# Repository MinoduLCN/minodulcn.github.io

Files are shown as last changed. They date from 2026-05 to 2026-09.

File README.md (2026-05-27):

# Minodu Project — GitHub Pages Site

Project presentation and documentation site for the Minodu Project.  
Built with [Jekyll](https://jekyllrb.com/) + [Minima](https://github.com/jekyll/minima) theme, served by GitHub Pages.

🌐 **Live site:** <https://minodulcn.github.io>

---

## Pages

| Page | File | URL |
|---|---|-----|
| Home | `index.md` | `/` |
| Getting Started | `getting-started.md` | `/getting-started/` |
| Features | `features.md` | `/features/` |
| Documentation | `docs.md` | `/docs/` |
| About | `about.md` | `/about/` |

---

## Local Development

### Step 1 — Install a modern Ruby

macOS ships with Ruby 2.6, which is too old for the `github-pages` gem. Use `rbenv` to manage a newer version:

```bash
brew install rbenv ruby-build

# Add rbenv to your shell (run once)
echo 'eval "$(rbenv init - zsh)"' >> ~/.zshrc
source ~/.zshrc

# Install Ruby 3.3 and pin it to this project
rbenv install 3.3.6
rbenv local 3.3.6      # creates a .ruby-version file in the repo
ruby --version          # should show 3.3.6
```

### Step 2 — Install dependencies

```bash
gem install bundler
bundle install
```

> `bundle install` reads the `Gemfile` and installs Jekyll + the same gem set GitHub Pages uses,
> so what you see locally matches what GitHub builds.

### Step 3 — Serve locally

```bash
bundle exec jekyll serve
```

Then open **http://localhost:4000** in your browser. The server watches for file changes and
rebuilds automatically — just save a file and refresh.

### Useful flags

| Flag | Effect |
|---|---|
| `--livereload` | Auto-reloads the browser on save |
| `--drafts` | Also renders posts in `_drafts/` |
| `bundle exec jekyll build` | One-shot build into `_site/` without serving |

---

## Deployment

Every push to `main` triggers an automatic build by GitHub Pages.  
No manual step needed — just push and GitHub does the rest.

> **One-time setup:** Confirm GitHub Pages is enabled in  
> **Settings → Pages → Source → Deploy from branch → `main` / `(root)`**

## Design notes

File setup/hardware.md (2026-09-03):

---
layout: page
title: Hardware Assembly
---

The Minodu Local Community Network mainly consists of two parts: the [Local Community Network](#assembly-guide-minodu-local-community-network): a Raspberry Pi, the TeleAgriculture Board and a power converter, housed in a custom 3D-printed protection box; and the 3D-printed [Stevenson Screen](#stevenson-screen--sensors) in which the environmental sensors are fixed and protected.

<iframe
  src="https://a360.co/4q3GGlT"
  style="width:100%; height:720px;"
></iframe>
[Link to Design (Autodesk Fusion 360)](https://a360.co/4q3GGlT): https://a360.co/4q3GGlT

# Assembly guide: Minodu Local Community Network

<div style="display: grid; grid-template-columns: 1fr 1fr; gap: 1rem; flex-wrap: wrap;">

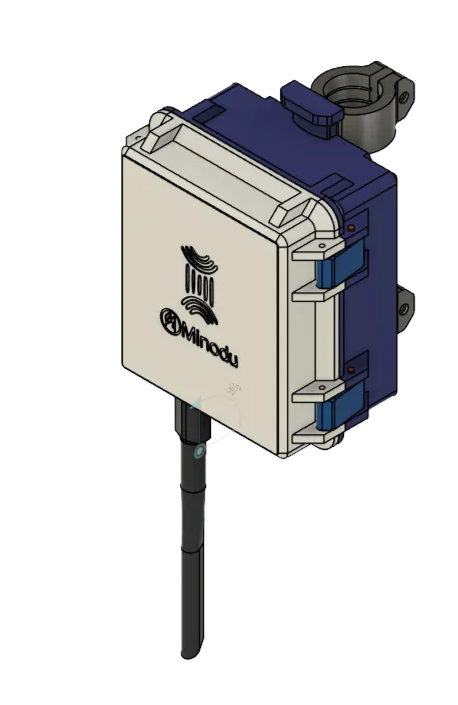
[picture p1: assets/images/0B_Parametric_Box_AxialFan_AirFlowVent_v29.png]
  
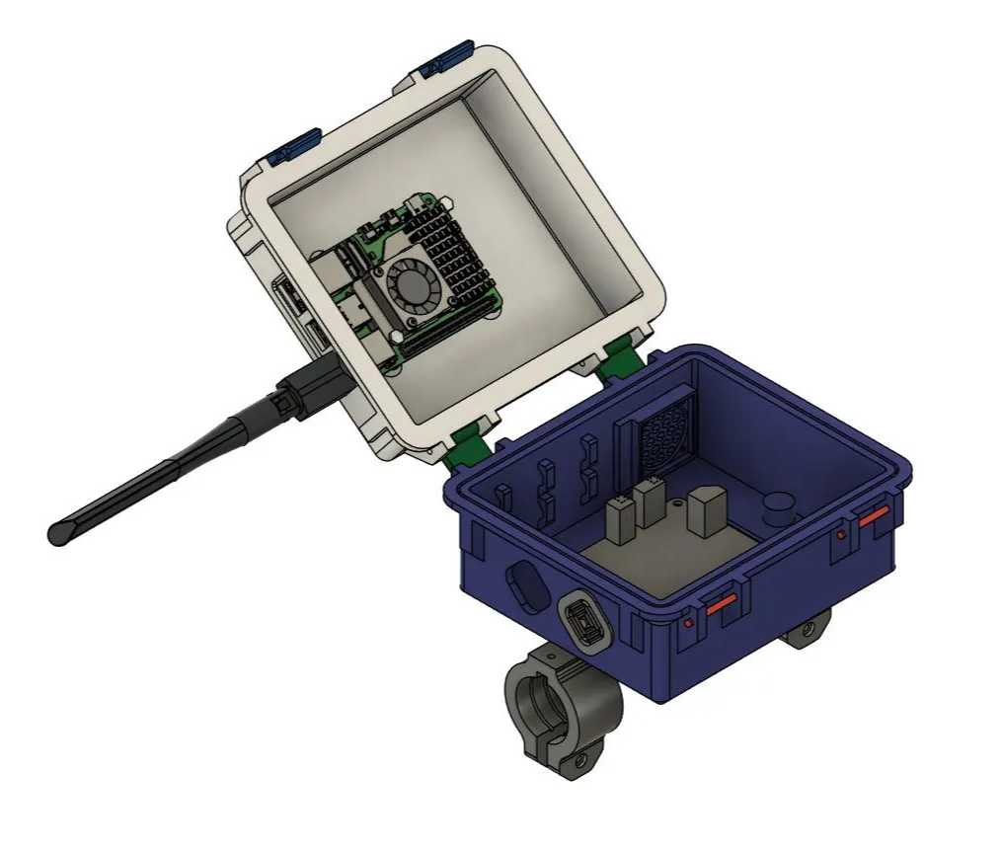
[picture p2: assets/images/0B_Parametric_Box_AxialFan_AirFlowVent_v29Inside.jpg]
  
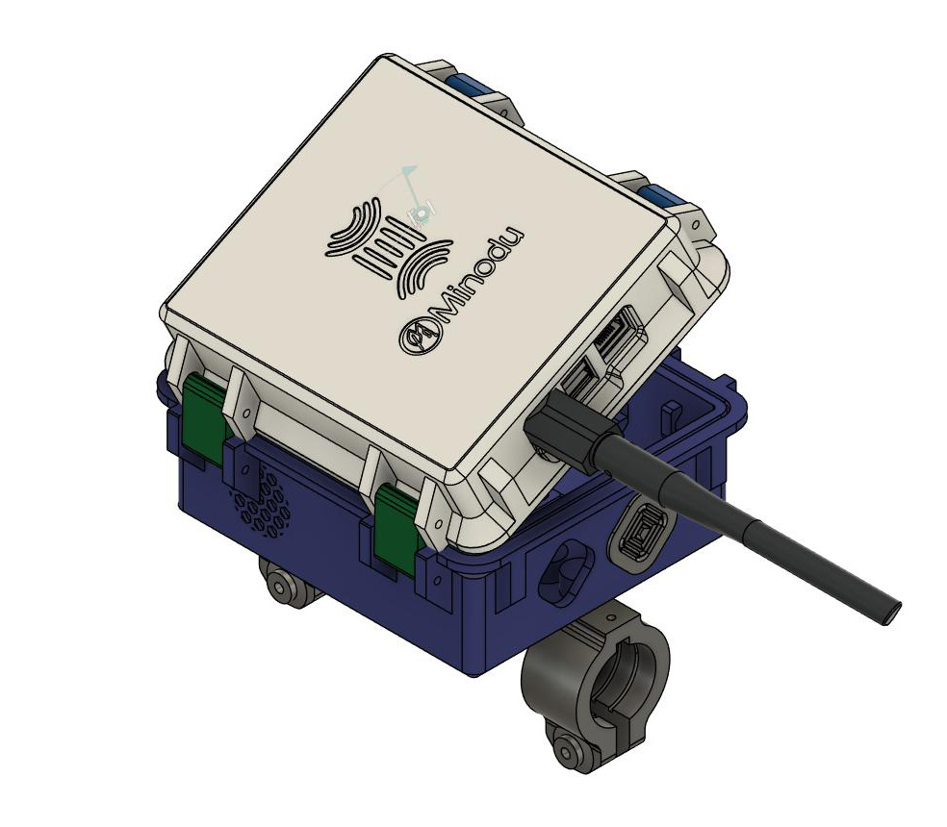
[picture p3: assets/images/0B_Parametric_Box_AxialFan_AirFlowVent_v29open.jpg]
  
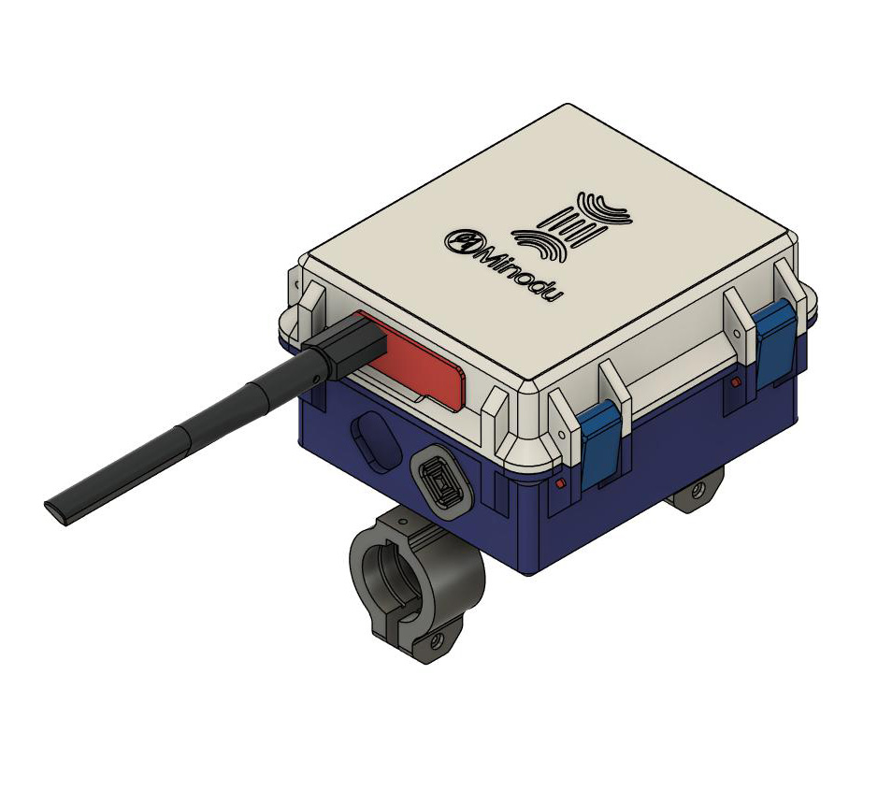
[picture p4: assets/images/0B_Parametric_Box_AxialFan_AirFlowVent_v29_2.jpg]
  

</div>

## 3D Printing Guide

### Materials
- Idealy PETG, ASA, ABS ( Unprotected ABS should almost never be used outdoors. To make ABS suitable for the sun, it must be coated in a UV-resistant paint or clear coat)
- TPU for flexible and sealing components

### Protection Box 3D Files
*ABS or at least PETG for outdoor setup*
 - [01x Base](../assets/3dFiles/Base_x01.stl)
 - [01x Top](../assets/3dFiles/Top_x01.stl) if you can Print Mulitcolor use This [Top_x01-MultiColor.stl](../assets/3dFiles/Top_x01-MultiColor.stl)
 - [02x Hinge](../assets/3dFiles/Hinge_x02.stl)
 - [02x Latch](../assets/3dFiles/Latch_x02.stl)
 - [02x Latch clip](../assets/3dFiles/Clip_x02.stl)

 *Flexible parts (TPU)*
 - [02x TPU Cable outlet cap](../assets/3dFiles/TPU_CableOutletCap_x02.stl)
 - [01x TPU RPi5 ports dust cap](../assets/3dFiles/TPU_RPi5PortDustCaps_x01.stl)

  For the 3D Files for the Stevenson Screen see [Stevenson Screen 3D Files](#stevenson-screen-3d-files)

### Slicer Setup
3D printers only understand G-code language (**geometric code)**; So what we need to do is to convert the *STL* files into G CODE. 

Recommended tool: I personally use [OrcaSlicer](https://www.orcaslicer.com/) but they all work the same.
Tool tutorial: Watch [this quick video](https://www.youtube.com/watch?v=KWfKkeOSpmw) to get you started if you are new to 3D printing with OrcaSlicer.

Here is The Orca slicer projectfile withh all the parts
    - [Minodu_Box.3mf](../assets/3dFiles/Minodu_Box.3mf)

## Protection Box assembly
This guide explains how to assemble the 3D-printed protection box for the Minodu Local Network. The enclosure is designed to house a Raspberry Pi 5, the Tele-Agriculture Board, a 12V-to-5V DC-DC power converter, sensor cables, and can be mounted on a pole for outdoor installations with a Stevenson screen.

**Assembly video**

<iframe width="100%" style="aspect-ratio: 16 / 9" src="https://www.youtube.com/embed/7zh7hve5er4?si=OtjEWRjfrtD__3ae" title="Minodu Protection Box Assembly steps" frameborder="0" allow="accelerometer; autoplay; clipboard-write; encrypted-media; gyroscope; picture-in-picture; web-share" referrerpolicy="strict-origin-when-cross-origin" allowfullscreen></iframe>

### Required Components

#### 3D Printed Parts

- Top cover
- Bottom enclosure
- 2 × Hinges
- 2 × Latches
- TPU dust cap

#### Electronics

- Raspberry Pi 5
- Raspberry Pi Active Cooler
- Tele-Agriculture Board
- 12 V → 5 V DC-DC Converter
- 30 × 30 × 10 mm cooling fan

#### Hardware

- 04x M2.5 heat-set inserts
- 04x M2.5 × 20 mm standoffs
- 04x M2.5 × 6 mm screws
- 06x M3 × 30 mm hex socket head screws
- 06x M3 hex nuts
- 02x M6 heat-set inserts
- 02x M6 × 14 mm countersunk screw

### Step by step assembly
#### Step 1 – Install Raspberry Pi Inserts
{:.no_toc}

| Steps | Images |
|---|---|
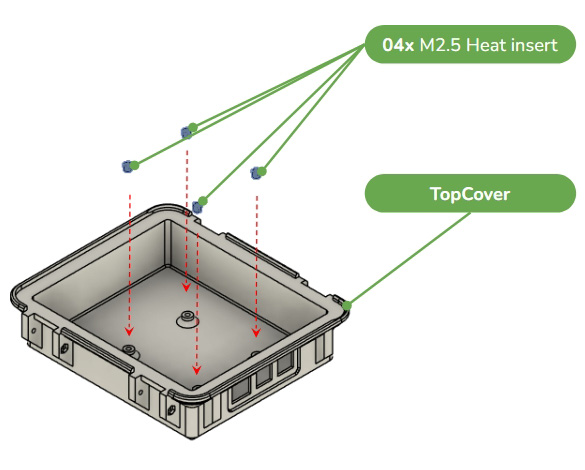
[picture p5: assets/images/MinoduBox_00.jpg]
Step 01
| Turn the top cover upside down. Insert the M2.5 heat-set inserts into the designated mounting holes using a soldering iron or heat-set insert tool. |  |
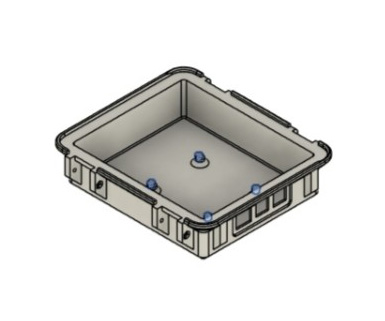
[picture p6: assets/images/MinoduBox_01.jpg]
Step 02
| Ensure every insert sits perfectly flush with the plastic surface. **CAUTION: Allow the inserts to cool before continuing.** |  |

___

#### Step 2 – Mount the Raspberry Pi
{:.no_toc}

| Steps | Images |
|---|---|
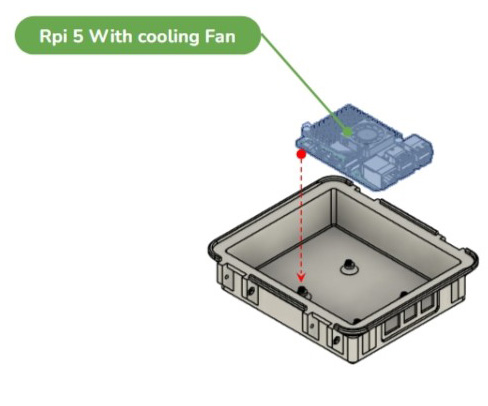
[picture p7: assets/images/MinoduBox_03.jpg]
| Position the Raspberry Pi 5 (with its cooling fan already installed) over the inserts. |  |
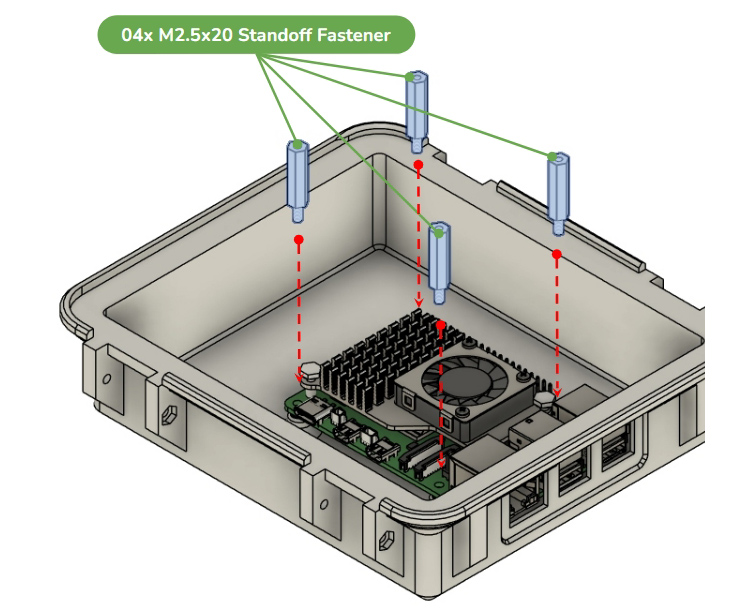
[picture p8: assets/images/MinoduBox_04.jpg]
| Install the 20 mm M2.5 standoffs and secure the Raspberry Pi. |  |
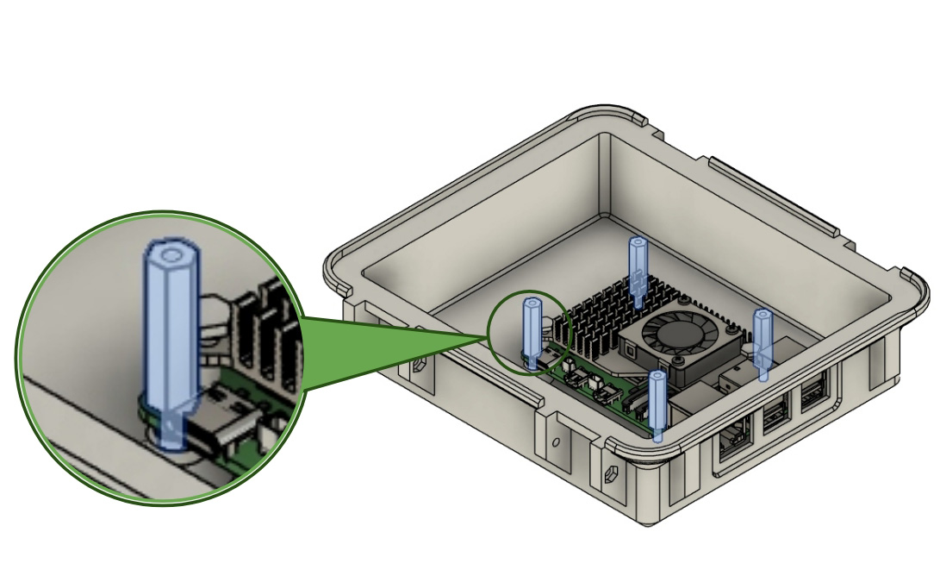
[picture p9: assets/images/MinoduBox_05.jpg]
| Verify that the board is firmly mounted. |  |

___

#### Step 3 – Install the Tele-Agriculture Board
{:.no_toc}

| Steps | Images |
|---|---|
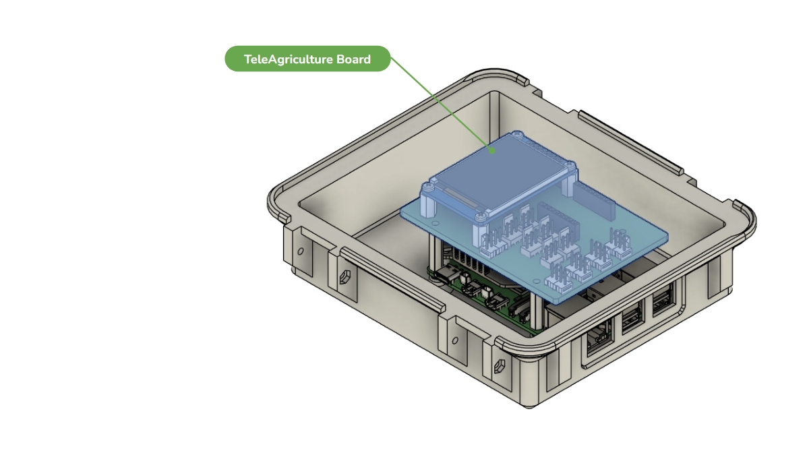
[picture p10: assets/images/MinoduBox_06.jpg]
| Place the Tele-Agriculture Board on top of the standoffs. |  |
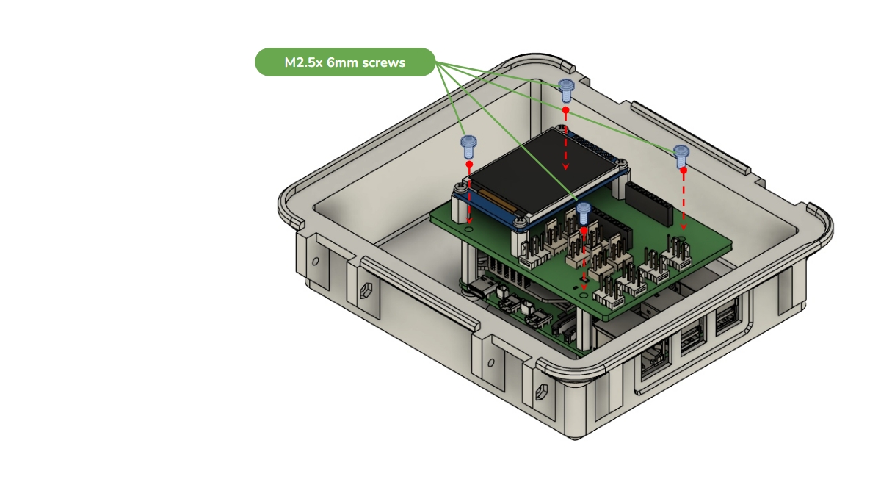
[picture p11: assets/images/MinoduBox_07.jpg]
| Secure it using M2.5 × 6 mm screws. |  |
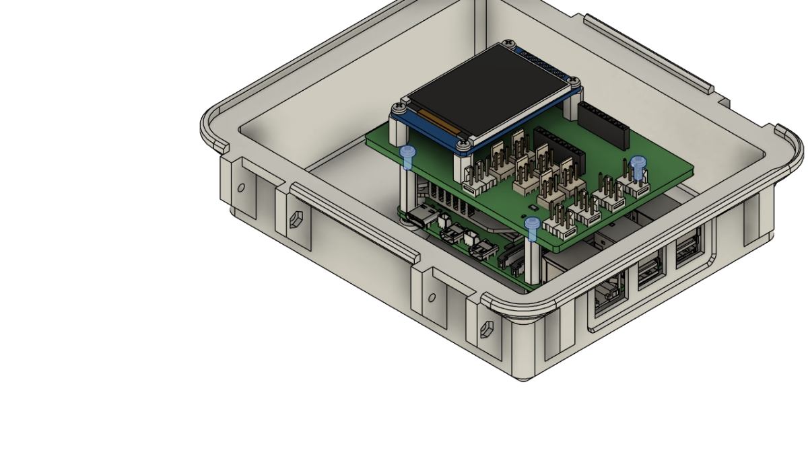
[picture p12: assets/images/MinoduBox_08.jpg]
Step 04 Step 0X
| Install the fourth screw located beneath the display. **IMPORTANT: Check that nothing moves or is loose.** |  |

___

#### Step 4 – Assemble the Latches
{:.no_toc}

| Steps | Images |
|---|---|
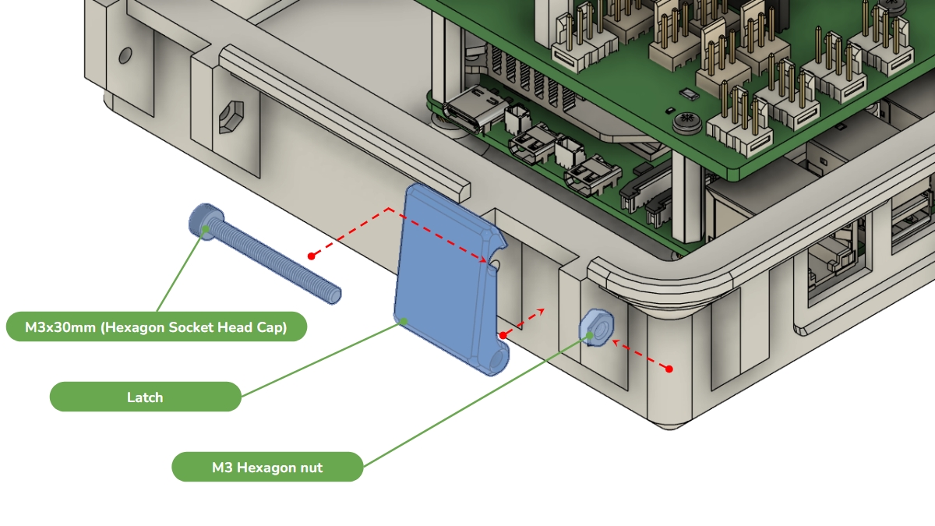
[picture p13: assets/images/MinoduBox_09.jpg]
| Insert one M3 hex nut. Align the latch. Insert one M3 × 30 mm screw. |  |
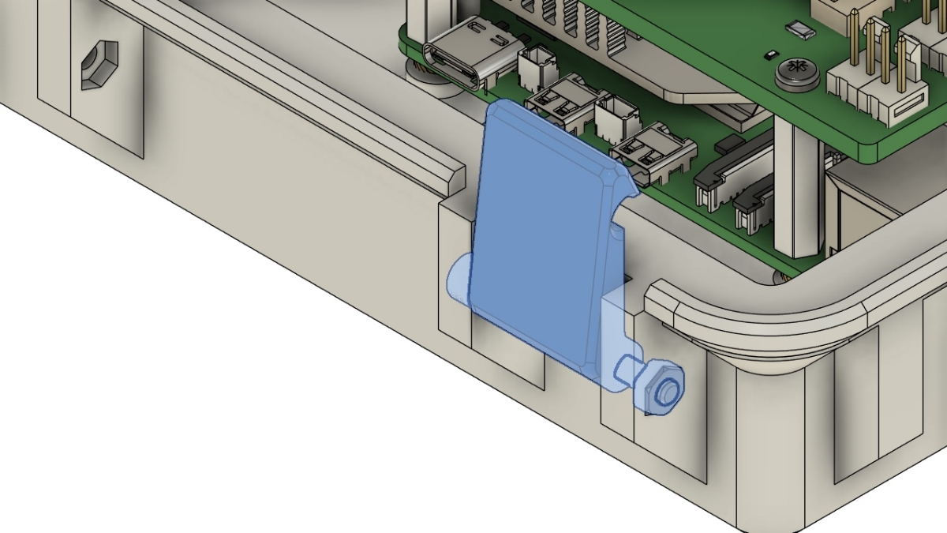
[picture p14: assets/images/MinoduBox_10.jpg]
| Tighten until secure. |  |
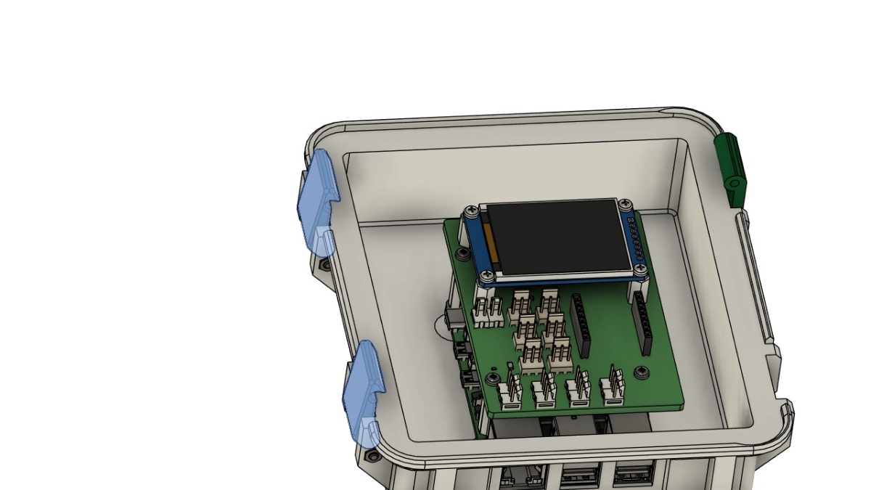
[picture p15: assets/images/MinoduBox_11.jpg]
| Repeat for the second latch. |  |

___

#### Step 5 – Assemble the Hinges
{:.no_toc}

| Steps | Images |
|---|---|
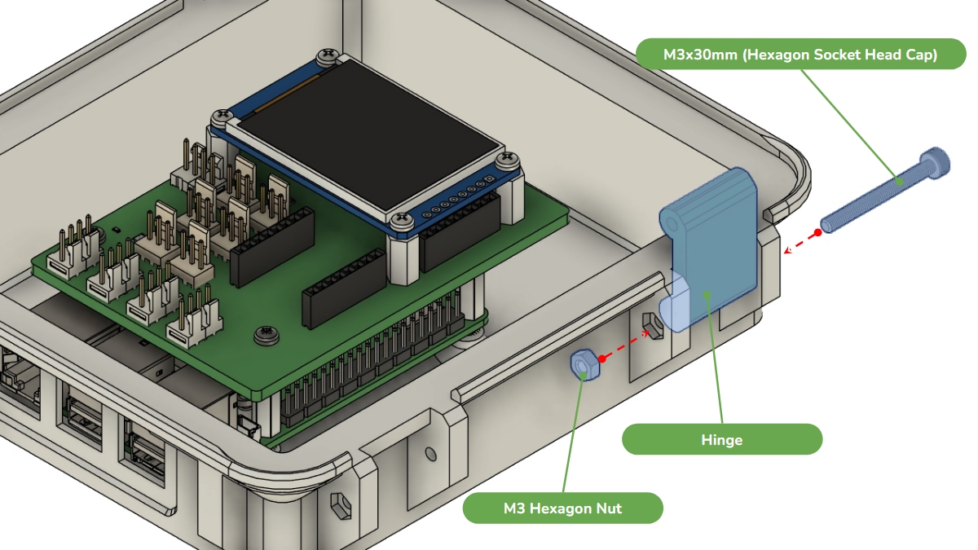
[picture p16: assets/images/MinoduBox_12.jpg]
| On the other side of the box, using the same hardware: Insert the M3 nut. Align the hinge. Insert the M3 × 30 mm screw. Tighten. |  |
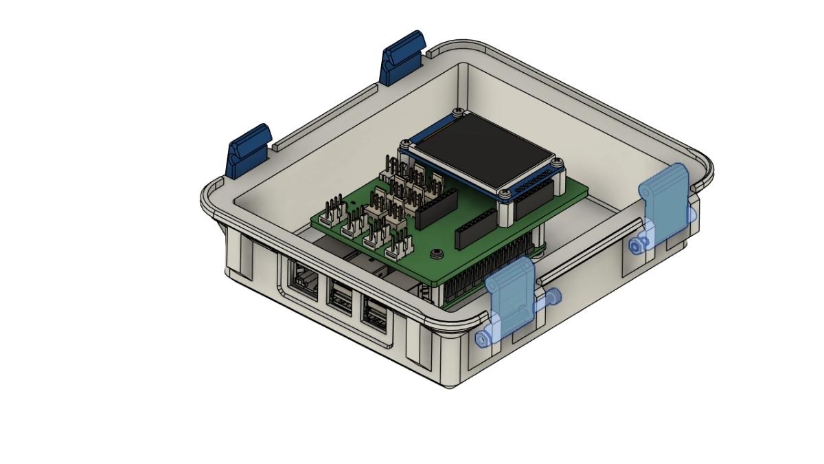
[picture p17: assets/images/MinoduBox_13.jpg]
| Repeat for the second hinge. Ensure both hinges rotate freely. |  |

___

#### Step 6 – Install the DC Converter Insert
{:.no_toc}

| Steps | Images |
|---|---|
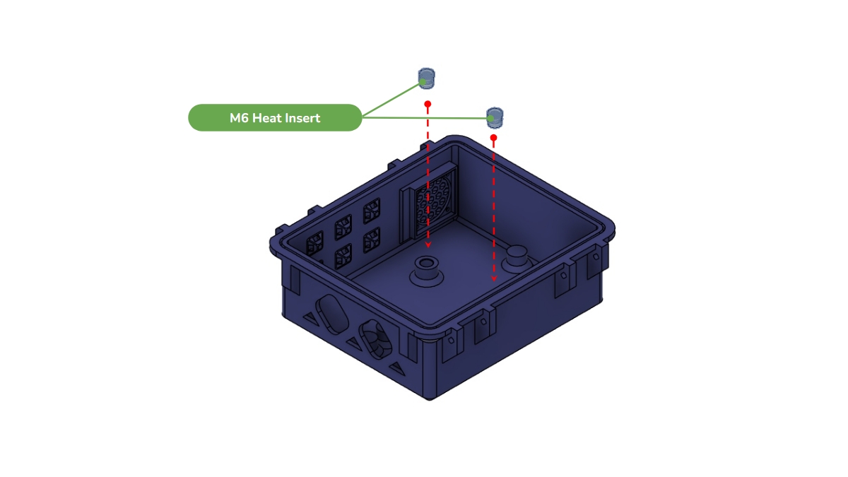
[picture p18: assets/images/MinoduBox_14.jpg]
| Install the M6 heat-set insert for the DC-DC converter into the bottom enclosure. |  |
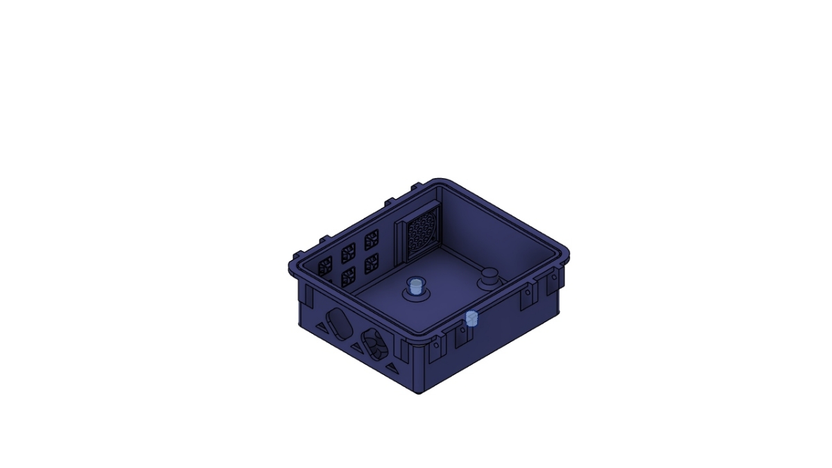
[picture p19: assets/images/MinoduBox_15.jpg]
| Make sure it is completely flush with the plastic. |  |

___

#### Step 7 – Install the Cooling Fan
{:.no_toc}

| Steps | Images |
|---|---|
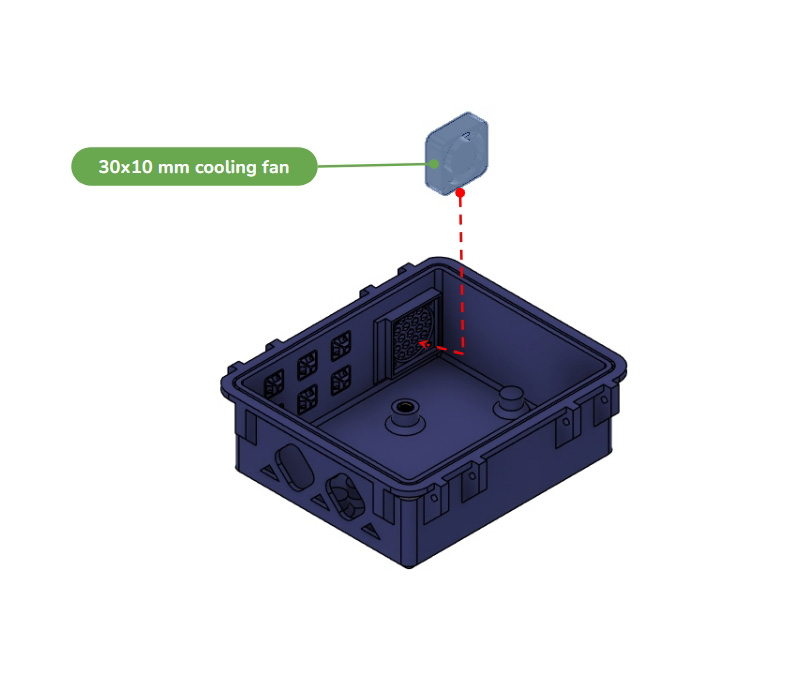
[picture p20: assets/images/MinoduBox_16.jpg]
| Insert the 30 × 30 × 10 mm cooling fan into its ventilation opening. **IMPORTANT: The cable exits toward the wiring opening. Airflow is directed from inside the enclosure to the outside.** |  |
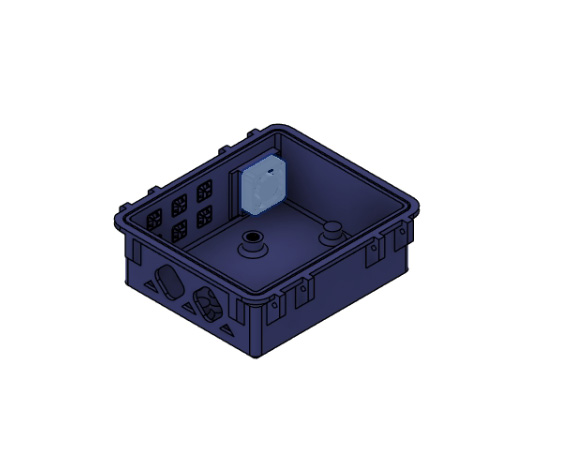
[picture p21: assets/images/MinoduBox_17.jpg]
| Push the fan fully into position. If necessary, secure it with a very small amount of glue. **CAUTION: Ensure the fan blades rotate freely. If the blades touch the >enclosure, If they rub against the enclosure, it can be jammed, overheat and be fried.** |  |

___

#### Step 8 – Install the DC-DC Converter
{:.no_toc}

| Steps | Images |
|---|---|
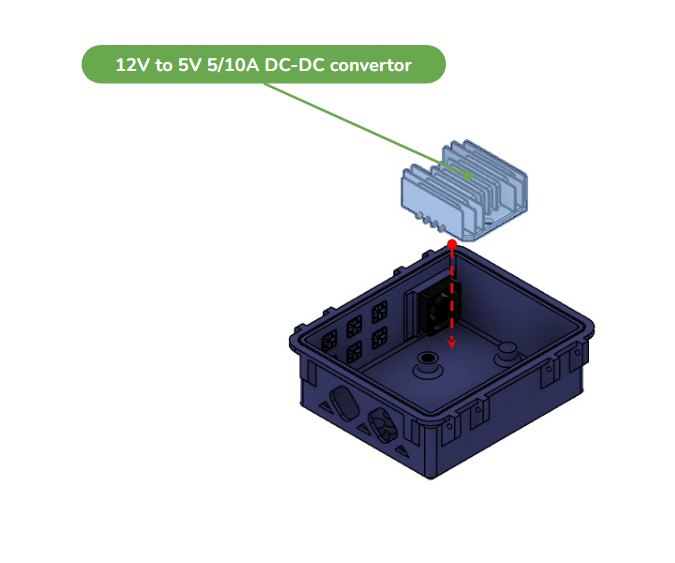
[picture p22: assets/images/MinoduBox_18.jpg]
| Position the 12V-to-5V converter inside the enclosure. |  |
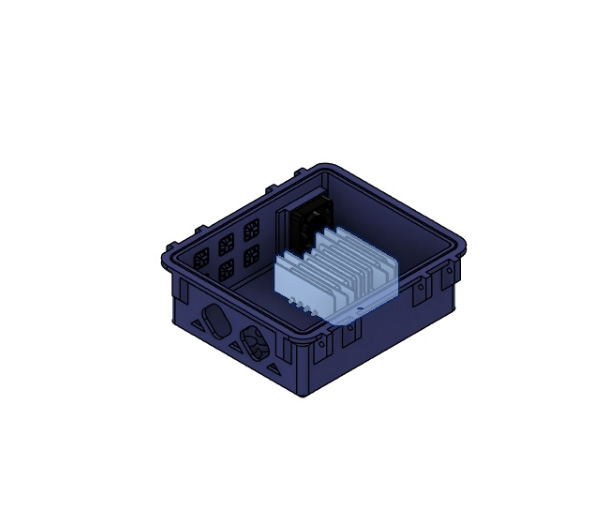
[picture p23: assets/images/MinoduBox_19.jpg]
| Align the mounting holes with the insert. |  |
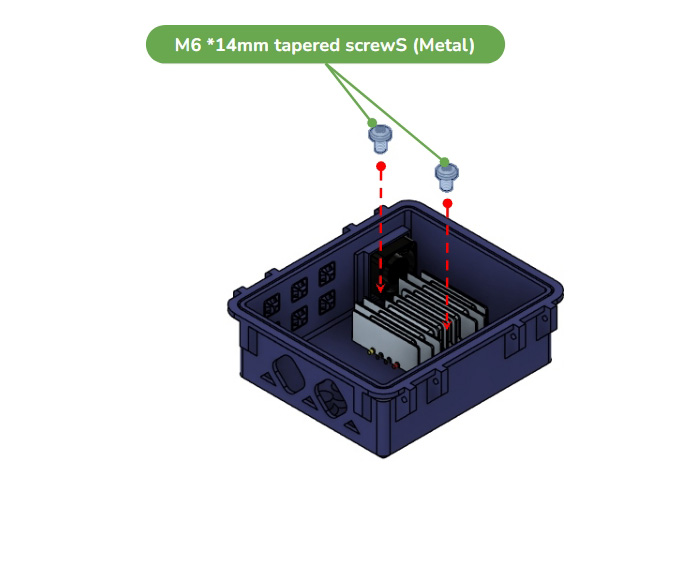
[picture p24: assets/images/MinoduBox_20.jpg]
| Secure it using the M6 × 14 mm countersunk screw. |  |
| Ensure the wiring faces the cable exit. | Step 0X |

___

#### Step 9 – Join Both Halves
{:.no_toc}

| Steps | Images |
|---|---|
| Align the hinge side first. Insert the hinge screws, nuts and, tighten. | Step 0X |
| Then align the latch side and secure it. Verify that: A) The enclosure opens smoothly. B) The enclosure closes correctly. | Step 0X |

#### Step 10 – Install the Latch Clips
{:.no_toc}

| Steps | Images |
|---|---|
| Insert the two printed latch clips into the lower enclosure. Push them fully into place until flush. | Step 0X |
| Close the enclosure and verify that the latches lock securely. | Step 0X |

#### Step 11 – Final Assembly
{:.no_toc}

| Steps | Images |
|---|---|
| Install: A) TPU dust cap; B) Wi-Fi antenna; C) Sensor cables. Install the dust cap around the cables to maintain dust protection. Route all cables through the cable openings. | Step 0X |

The enclosure is now ready to be mounted on a pole together with the Stevenson screen for outdoor deployment.

## Stevenson Screen Assembly

This guide explains how to assemble the 3D-printed Stevenson Screen and install the environmental sensors.

**Assembly video**

<iframe width="100%" style="aspect-ratio: 16 / 9" src="https://www.youtube.com/embed/IDYrpug46No?list=PLMNTAdNwypnw" title="Minodu StevensonScreen Assembly Steps" frameborder="0" allow="accelerometer; autoplay; clipboard-write; encrypted-media; gyroscope; picture-in-picture; web-share" referrerpolicy="strict-origin-when-cross-origin" allowfullscreen></iframe>

### Required Hardware
  - 7 × M3 nuts
  - 4 x M3 lock nuts / nyloc nuts
  - 3 × M3 × 10 mm screws
  - 4 × M3 × 140 mm threaded rods
  - 30+ x M2 heat-set inserts
   
### Required 3D-Printed Parts
  - [01x Stevenson screen sensor plate](../assets/3dFiles/StevensonScreen_RC01_Sensor_Plate)
  - [01x Stevenson screen top](../assets/3dFiles/StevensonScreen_RC01_Top.stl)
  - [01x Stevenson screen sensor plate holder](../assets/3dFiles/StevensonScreen_RC01_Midlle_SensorPlate_Holder.stl)
  - [06x Stevenson screen Midlle sections](../assets/3dFiles/StevensonScreen_RC01_Midlle_X06)
  - [01x Stevenson screen base](../assets/3dFiles/StevensonScreen_RC01_Base.stl)
  - [01x Stevenson screen bottom cover](../assets/3dFiles/StevensonScreen_RC01_Botom.stl)
  
### Step by step assembly 

#### Step 1 – Install the M3 Nuts in the Top
{:.no_toc}

| Steps | Images |
|---|---|
| Take the Stevenson Screen top and locate the four recessed holes. Insert the four M3 nuts into the recessed holes.| Step 0X |
| Push each nut fully into its recess and make sure that they are properly seated and secure. | Step 0X |

#### Step 2 – Install the Threaded Rods
{:.no_toc}

| Steps | Images |
|---|---|
| Take the four M3 × 140 mm threaded rods. Insert one threaded rod into each of the four holes and screw them gently into the M3 nuts installed in the previous step. Do not overtighten (⚠️ Important: Tighten the rods only enough to hold them securely. Excessive force may damage or crack the 3D-printed Stevenson Screen top).| Step 0X |
| Make sure all four rods are secure and properly aligned, then set the assembly aside. | Step 0X |

#### Step 3 – Install the M2 Heat-Set Inserts in the Sensor Plate
{:.no_toc}

| Steps | Images |
|---|---|
| Take the sensor plate and install the M2 heat-set inserts into the designated mounting holes. The position of the inserts can be adapted according to the sensors being used.Ideally, determine the sensor positions before installing the inserts.| Step 0X |
| Make sure each heat-set insert is: 1- Fully inserted; 2- Properly aligned with the sensor holes; 3- Flush with the surface of the sensor plate. | Step 0X |

#### Step 4 – Install the Sensors
{:.no_toc}

Once the inserts are installed, mount the sensors onto the sensor plate using the appropriate screws.
Arrange the sensors according to your desired configuration and route their wires appropriately.

If a particular sensor cannot be mounted using the heat-set inserts, it can instead be secured directly to the sensor plate using zip ties.

Make sure that:
- The sensors are firmly secured;
- The sensors do not obstruct each other;
- The cables are properly routed;

#### Step 5 – Assemble the Sensor Plate Holder
{:.no_toc}

| Steps | Images |
|---|---|
| Take the 3D-printed sensor plate holder. Insert the three M3 nuts into the three recessed holes. | Step 0X |
| Make sure the nuts are fully seated and correctly oriented.| Step 0X |

#### Step 6 – Attach the Sensor Plate to the Holder
{:.no_toc}

| Steps | Images |
|---|---|
| Take the sensor plate with the sensors already installed and wired. Align it with the three sensor plate holder holes.| Step 0X |
| Secure the two parts using three M3 × 10 mm screws.| Step 0X |
| Make sure the sensor plate is firmly attached and that none of the parts are loose.| Step 0X | 

#### Step 7 – Install the Sensor Assembly on the Stevenson Screen Top
{:.no_toc}

| Steps | Images |
|---|---|
| Take the assembled sensor plate + sensor plate holder. Align the four holes with the four 140 mm threaded rods installed on the Stevenson Screen top. Carefully slide the sensor assembly down over the four rods. ⚠️ Important: Lower the assembly gradually and evenly. Do not force one side down while leaving the other side high, as this can bend the threaded rods and make assembly difficult. | Step 0X |
|Push the assembly down gently until it reaches its intended position. Verify that everything is correctly aligned and securely assembled.| Step 0X |

#### Step 8 – Install the Stevenson Screen Middle Sections
{:.no_toc}

| Steps | Images |
|---|---|
| Take the six 3D-printed Stevenson Screen middle sections.Stack them one by one on top of the previously assembled components. Make sure each section is correctly aligned before adding the next one. | Step 0X |

#### Step 9 – Install the Stevenson Screen Base
{:.no_toc}

| Steps | Images |
|---|---|
| TTake the Stevenson Screen base. Place it on top of the assembled middle sections. Check that all components are correctly aligned and that the sensor cables remain properly routed.| Step 0X|

#### Step 10 – Install the Bottom Cover
{:.no_toc}

| Steps | Images |
|---|---|
| Take the Stevenson Screen bottom cover and place it on the base. Make sure that the cable opening is positioned on the same side as the mounting bracket. This orientation will make it easier to route the sensor cables toward the main protection box. | Step 0X |

#### Step 11 – Secure the Assembly
{:.no_toc}

Before securing the final assembly, verify that:
- All sensors are installed;
- All sensors are properly wired;
- All cables are correctly routed;
- The Stevenson Screen sections are properly aligned;
- The threaded rods are straight;
- Nothing is interfering with the sensors.

{:.no_toc}

| Steps | Images |
|---|---|
|Secure the complete assembly using M3 lock nuts (nyloc nuts).⚠️ Recommended: Use nyloc nuts rather than standard M3 nuts. A regular nut can gradually loosen due to vibration, especially in outdoor installations. Once all four lock nuts are tightened, check the complete assembly one final time. | Step 0X |

#### **Final Check**
{:.no_toc}
The Stevenson Screen is now ready to be connected to the Minodu Local Network protection box and mounted for outdoor deployment.

Ensure that the sensors have sufficient exposure to the surrounding air and that the Stevenson Screen provides adequate protection from direct environmental exposure while allowing appropriate airflow.

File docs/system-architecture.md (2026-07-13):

---
layout: page
title: System Architecture
---

The Local Community Network (LCN) is a decentralised, offline-first system combining hardware, software, and local networking.

**Key Design Principles**

- local Wi-Fi network  
- local data storage  
- local access via browser
- local llm
- low power consumption

**Data flow**

1. Sensors collect environmental data  
2. Data is processed and stored locally on the Raspberry Pi  
3. The application provides access to data through a local network  
4. Administrators manage content via the backoffice 

## Hardware Architecture

The system consists of three hardware components:

- **Raspberry Pi (Local Server)**  
  Hosts the application and creates a local Wi-Fi network  

- **Teleagriculture Board**
  Reads and collects the sensor data from the weather sensors and sends them to the raspberry pi.

- **Stevenscreen with Sensors and Wind instruments**  
  Collect environmental data such as temperature, humidity, air pressure, air quality, wind direction and speed

System Architecture Diagram

## Software Architecture

The software stack runs in several seperate docker containers. They are all build from the main minodu repository, which houses a monorepo with all the components:

* **Minodu Backend** serves a REST API to access and edit agricultural data, weather data and market information
* **Minodu Forum** serves a REST API to interact with the forum
* **Minodu AI Services** runs an API to interact with the llm, speech to text and text to speech functionalities
* **Minodu Database** serves a mysql database which holds all the shared data of the components
* **Mindu Frontend** serves the web frontend to access the minodu services
* **Minodu Backoffice** serves the backoffice for the admin to edit the system data

Software Architecture Diagram

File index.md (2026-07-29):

---
layout: home
title: Home
---

# Welcome to Minodu!
{:.no_toc}

## Fostering local sustainable development through technology and research
{:.no_toc}

<!--![cover](assets/images/minodu_cover.webp){: .cover-image}-->
<div class="video">
<iframe src="https://www.youtube.com/embed/Fekm3XAx7Lo?controls=0"
title="Minodu Project Video"
style="position: absolute; top00%; width: 100%; height: 100%;"
frameborder="0"
allow="accelerometer; autoplay; clipboard-write; encrypted-media; gyroscope; picture-in-picture; web-share"
allowfullscreen>
</iframe>
</div>

Together with rural communities in the Kara region of northern Togo, students, researchers, and technical partners, the Minodu project co-designed a **Local Community Network (LCN)** that works without continuous internet access or electricity. It provides local weather data, agricultural audio content in French and Kabiyè, a community forum, and a market interface. The system combines low-cost hardware, environmental sensing, local knowledge, and community-based maintenance. 

## Getting started

What do you want to do?
### [About the Minodu project](about)
**Learn more about this project.**

### [Setup guide](setup) 
**Learn how to build or repair the system.**
- [Material list](setup/materials)
- [Hardware assembly](setup/hardware)
- [Raspberry PI installation](setup/pi)
- [Teleagriculture installation](setup/teleagriculture)

### [Manual](manual)
**Take a look here if you want to use the local network.**
- [Minodu app](manual/app)
- [Backoffice](manual/backoffice)

### [Backoffice](manual/backoffice)
**Get to know how to manage the system.**

### [Documentation](docs)
**Find here more detailed Information about the system.**
- [System Architecture](docs/system-architecture)
- [Minodu API](docs/api)
- [Workshop materials](docs/workshop)

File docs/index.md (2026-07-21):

---
layout: page
title: Docs
heading_title: Documentation
---

This section provides technical and methodological documentation of the Minodu project and the Local Community Network (LCN).
The documentation covers system architecture, implementation details, and the participatory processes used throughout the project.

### System Architecture
This Section describes how the minodu system is organized and explains the technical structure.

*[→ Go to system architecture](./system-architecture)*

### Minodu API
The Minodu API documents the interfaces used for data exchange between system components, including sensor data, application services, and local network communication.

*[→ Go to Minodu API](./api)*

### Workshop materials
This section documents the participatory design and evaluation process of the project, including co-design workshops, prototyping activities, and user feedback methods.

*[→ Explore Workshop materials](./workshop)*

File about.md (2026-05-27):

---
layout: page
title: About
permalink: /about/
---

## The Project

Minodu started as … *(tell the origin story: what gap it fills, when it was created, what drives it)*.

Today it is used for … *(describe the current scope and audience)*.

---

## The Team

| Name | Role | GitHub |
|---|---|---|
| *(Your Name)* | Maintainer | [@minodulcn](https://github.com/minodulcn) |
| *(Contributor)* | *(Role)* | *(link)* |

---

## Contributing

Contributions are welcome! Here's how:

1. Fork the repository on [GitHub](https://github.com/minodulcn/minodulcn.github.io).
2. Create a feature branch: `git checkout -b feature/my-feature`
3. Commit your changes: `git commit -m "Add my feature"`
4. Open a Pull Request.

Please read `CONTRIBUTING.md` *(create this file when ready)* for the full guidelines.

---

## License

Minodu is released under the [MIT License](https://opensource.org/licenses/MIT) *(or replace with your actual license)*.

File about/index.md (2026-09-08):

---
layout: page
title: About
heading_title: About the project
---

Minodu explores how decentralised, locally maintained digital infrastructures can support climate resilience in low-resource settings. Its aim is to bridge local knowledge with scientific knowledge to better address the effects of climate change. The project follows a **co-design** approach: we design, test, and build together.
At the core of Minodu is the Local Community Network (LCN), a decentralised, offline-first system based on low-cost hardware and software. It combines environmental sensing, local data access, and community exchange.
The system enables access to environmental data, agricultural advice, and community knowledge through local networks that operate without continuous Internet connectivity.

LCN_Tchitchao
Local Community Network in Tchitchao.

### Objectives
Launched in 2023 in the Kara region of northern Togo, Minodu aims to: 

- facilitate access to useful knowledge without depending on continuous Internet access; 

- value local knowledge and field-based experience, particularly from the communities of Tchitchao, Lama-Saoudé, and Soumdina-Haut; 

- co-create practical solutions with communities, based on locally identified needs; 

- strengthen self-reliance, local maintenance capacities, and mutual aid between villages. 

Students from the [**Kara University**](https://univ-kara.org/) worked with the communities to co-design **simple, practical and context-based** solutions.

soumdina-group

### What does DIY mean? 

**DIY** stands for **«Do It Yourself»**. It means building, repairing, or adapting things with simple and accessible materials, without relying on expensive external experts.

In Minodu, the DIY approach helps create a robust local community network that is affordable, locally understandable, and easier to maintain over time. 

diy

### Partners
This project is the result of a collaboration between the following parties:
- **Local communities**: Tchitchao, Lama-Saoudé, Soumdina-Haut
- **Kara University**: Magnim Essolakina BOKOBANA, Damghane OUDANOU, Mikémina PILO
- **DFKI (German Center for Artificial Intelligence)**: Friederike Fröbel, Philipp Gschwendtner, Antonia Katthaen, Carina Lange, Jannes Ulbrich 
- **Further Contributers**: Séti AFANOU, Nihade ASSOUMANOU, Abiré BÉRÉ, Ousia FOLI-BEBE, Lutz Reiter, Eric Tiedt, Victoire TSAMEDI

### Funding
This project is funded by the German Federal Ministry of Research, Technology and Space (BMFTR) as part of the Minodu project (FKZ 01LL2202A), within the funding line *"Sustainable land management in sub-Saharan Africa: improving livelihoods through local research"*.

---
### Contributing

Contributions are welcome! 
*Minodu is an open and evolving project. We welcome contributions from students, developers, researchers, makers, community members, and partner organisations who want to help improve the Local Community Network and adapt it to real needs on the ground.* 

You can contribute in different ways, for example by:
- reporting problems or bugs you encounter while using the system; 
- suggesting new features, content, or interface improvements; 
- improving the documentation, setup guide, or user manual; 
- translating or adapting content into local languages; 
- sharing ideas for using the LCN in schools, villages, farms, associations, or training contexts; 
- contributing code, hardware improvements, or maintenance solutions. 

If you would like to contribute directly to the code or documentation, you can: 
1. Fork the repository on [GitHub](https://github.com/minodulcn/minodu).
2. Create a feature branch: `git checkout -b feature/my-feature`
3. Commit your changes: `git commit -m "Add my feature"`
4. Open a Pull Request with a brief description of what you changed and why.

### Support
Are you having problems with your Local Community Network (LCN)?
Or do you have ideas you’d like to implement or share with others?
If you are not familiar with GitHub, you can still contribute. Please send us your feedback, questions, ideas, or post them in the [Discussion Baord](https://github.com/MinoduLCN/minodu/discussions). 
Minodu is built through shared testing, local experience, and practical improvements over time. 

### License

Minodu source code is released under the [GNU License](https://github.com/MinoduLCN/minodu/blob/main/LICENCSE.md).

### Tech-Team

| Name | GitHub |
|---|---|
| Victoire TSAMEDI | [abayi6](https://github.com/abayi6) |
| Friederike Fröbel | [frfr01](https://github.com/frfr01) |
| Jannes Ulbrich | [jannesulbrich](https://github.com/jannesulbrich) |
| Lutz Reiter | [lutzer](https://github.com/lutzer) |
| Ousia A. FOLI-BEBE | [ousiafb](https://github.com/ousiafb) |
| Séti AFANOU | [setico](https://github.com/setico) |

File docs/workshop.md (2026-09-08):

---
layout: page
title: Workshop materials
toc: true
---

The development and evaluation of the Local Community Network (LCN) followed an iterative, participatory process combining co-design, prototyping, and multi-layered evaluation methods.
The workshops form an iterative process from exploration and co-design to prototyping, testing, and multi-layered evaluation.

### Atelier pratique 07/23
This first workshop was conducted on July 27 and 28, 2023, as a hands-on, station-based learning experience at the University of Kara, introducing participants to topics such as electronics, programming, environmental sensing, and climate adaptation.  

The full activity booklet, guiding participants through the workshop stations and exercises, is available here: 
- [Activity booklet](../assets/pdf/Cahier_d'activit%C3%A9_AtelierPratique.pdf)
- [Publication about a part of this workshop](https://dl.acm.org/doi/10.1145/3757232.3757251)

### Weather sounds 03/24
Minodu Weather sounds workshop

The workshop was conducted on March 2024 with students from the University of Kara. This workshop explored how weather sounds are associated with colors, emotions, and visual representations.

The worksheet in English is available here: 
[Activity sheet](./assets/pdf/EvenementsMeteoEN fin.pdf)

### Paper Prototyping with stickers 11/24
Minodu Paper Prototyping Workshop

These workshops were conducted in November 2024 with students from Kara University, who facilitated the activities in the local language with three rural communities (Tchitchao, Soumdina Haut, and Lama Saoudé) in the Kara region. Participants used a sticker-based paper prototyping method to explore needs, priorities, and expectations regarding a local community network. The participants expressed their ideas through drawing and sticker-based activities, focusing on relevant topics, desired services, and the role of weather information in their everyday practices.  

The materials used in this workshop are available here:  
- [Paper Prototyping booklet](../assets/pdf/PaperPrototypingTaches.pdf)  
- [Sticker set](../assets/pdf/CollectedIconsSticker.pdf)

### Clickthrough Prototype Testing 05/25
Minodu Card Sorting Game Workshop

This workshop focused on testing and refining a local, offline-first interface through a clickthrough prototype. Participants navigated the interface through guided tasks, exploring different application sections and information pathways to evaluate usability, clarity, and structure.

The activity booklet used to guide testing and collect feedback is available here:
- [Activity booklet](../assets/pdf/Cahier_d'activit%C3%A9_Interface.pdf)

### Card Sorting Game 05/25
Minodu Card Sorting Game Workshop

This activity was inspired by prior research on culture-aware categorisations of interface elements by [Rodil et al.](https://link.springer.com/chapter/10.1007/978-3-642-40483-2_30). Participants grouped and organised different content images, icons and pictograms to express their own understanding and priorities and to create a categorisation for the Local Community Network (LCN).

The materials used in this workshop are available here: 
- [Card set](../assets/pdf/CardSortingCategories.pdf)

### Application Feedback Workshop 03/26
The application feedback workshop (03/26) follows a three-step methodology to capture how the Local Community Network (LCN) is perceived, understood, and evaluated.

The sticker set used across the following three activities is available here:
- [Sticker set](../assets/pdf/260312_StickerGes_A.pdf)

The sheet is structured into three sections: the left side is used for the System Usability Score (SUS), the middle section for demographic information and application feedback, and the right side for developing user stories.

#### Perception: Application Impression
Minodu Application Workshop

During this workshop activity participants shared their impressions of the system, reflecting on which parts they found useful, confusing, or missing. The worksheet guided participants to evaluate different sections of the application and to articulate their expectations and suggestions for improvement. 
Participants were also invited to rethink the representation of the chatbot by proposing alternative symbols. This task provided insights into how specific system elements are interpreted and how their representation can be adapted to local contexts.

The material used for this activity is available here:  
- [Worksheet](../assets/pdf/FicheDeTravail1.1.pdf)

#### Interpretation: User Stories
Minodu User Stories Workshop

This activity focused on exploring how participants understand and explain the Local Community Network (LCN) through storytelling. Using a guided worksheet, participants were invited to imagine explaining the system to a family member and/or friend and to describe its purpose, use, and relevance within their everyday lives.
The activity encouraged participants to express their perspectives through narratives, drawings, and stickers, supporting the development of user stories grounded in lived experience and local contexts.  

The worksheet used in this workshop is available here:  
- [Worksheet](../assets/pdf/FicheDeTravail2_Histoire.pdf)

#### Evaluation: System Usability Score (SUS)
Minodu User Stories Workshop

This activity focused on evaluating the usability of the local network system using a context-adapted System Usability Scale (SUS). Participants interacted with the system and provided structured feedback on clarity, usability, and overall experience. 
The adapted SUS was translated and simplified to ensure accessibility and comprehension in the local context, using a visual scale.

The materials used in this workshop are available here: 
- [Worksheet](../assets/pdf/FicheDeTravail3_SUS.pdf)

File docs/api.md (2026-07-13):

---
layout: page
title: Minodu API
---

In this document the api of the MinoduLCN system is described. It shows all available endpoints to interact with the system and retrieve data.

## Backend API

When running the project in **development mode**, the full Swagger/OpenAPI documentation is available interactively at `http://localhost:3000/api-docs`

When runnding the project in **release mode**m the docuenation is available at: `http://localhost/api/backend/api-docs`

This interactive documentation allows you to:
- Explore all available endpoints
- View detailed request/response schemas
- Test API endpoints directly from your browser
- Understand the complete API structure

> **Note:** The Swagger UI is only available when the application is running in development environment (`NODE_ENV=development`).

---

### Authentication

Most API endpoints are protected and require a Bearer token for authentication. The token can be obtained by using the `signin` or `signup` endpoints.

- **Security Scheme**: `bearer` (JWT)
- **Format**: `Authorization: Bearer <your-jwt-token>`

---

### API Reference

#### Auth
{:.no_toc}
Endpoints for user authentication and account management.

###### POST `/v1/auth/signin`
{:.no_toc}
Login to your account.

**Request Body:**

```json
{
  "phone": "string (required) - User phone number",
  "password": "string (required) - User password"
}
```

**Response:** `201 Created` - Authentication successful.

---

###### POST `/v1/auth/signup`
{:.no_toc}
Create a new account.

**Request Body:**

```json
{
  "fullName": "string (required) - User full name",
  "phone": "string (required) - User phone number",
  "gender": "string (required) - User gender",
  "password": "string (required) - User password"
}
```

**Response:** `201 Created` - Account created successfully.

---

###### GET `/v1/auth/logout`
{:.no_toc}
Logout from the current session.

**Authentication:** Required (Bearer Token)

**Response:** `200 OK` - Logout successful.

---

#### User
{:.no_toc}
Endpoints for managing users and retrieving user information.

###### GET `/v1/users`
{:.no_toc}
List all users.

**Authentication:** Required (Bearer Token)

**Response:** `200 OK` - Returns list of all users.

---

###### POST `/v1/users`
{:.no_toc}
Create a new user.

**Authentication:** Required (Bearer Token)

**Request Body:**

```json
{
  "fullName": "string (required) - User full name",
  "phone": "string (required) - User phone number",
  "gender": "string (required) - User gender",
  "password": "string (required) - User password",
  "isContactPerson": "string (required) - Is the user the community contact person?"
}
```

**Response:** `201 Created` - User created successfully.

---

###### PATCH `/v1/users`
{:.no_toc}
Update the current user's data.

**Authentication:** Required (Bearer Token)

**Request Body:**

```json
{
  "fullName": "string (required) - User full name",
  "gender": "string (required) - User gender (Male, Female, Other)",
  "phone": "string (required) - User phone number",
  "isContactPerson": "string (required) - Is the user the community contact person?"
}
```

**Response:** `200 OK` - User updated successfully.

---

###### GET `/v1/users/dashboard`
{:.no_toc}
Get the admin dashboard data.

**Authentication:** Required (Bearer Token)

**Response:** `200 OK` - Returns admin dashboard statistics.

---

###### GET `/v1/users/current`
{:.no_toc}
Get details of the current authenticated user.

**Authentication:** Required (Bearer Token)

**Response:** `200 OK` - Returns current user details.

---

###### GET `/v1/users/{id}`
{:.no_toc}
Get information for a specific user.

**Authentication:** Required (Bearer Token)

**Path Parameters:**
- `id` (number, required) - User ID

**Response:** `200 OK` - Returns user information.

---

###### PATCH `/v1/users/{id}`
{:.no_toc}
Update data for a specific user.

**Authentication:** Required (Bearer Token)

**Path Parameters:**
- `id` (number, required) - User ID

**Request Body:**

```json
{
  "fullName": "string (required) - User full name",
  "gender": "string (required) - User gender (Male, Female, Other)",
  "phone": "string (required) - User phone number",
  "isContactPerson": "string (required) - Is the user the community contact person?"
}
```

**Response:** `200 OK` - User updated successfully.

---

###### GET `/v1/users/contact-person`
{:.no_toc}
Get contact person information.

**Authentication:** Required (Bearer Token)

**Query Parameters:**
- `id` (number, required) - User ID

**Response:** `200 OK` - Returns contact person information.

---

###### PUT `/v1/users/password`
{:.no_toc}
Modify the current user's password.

**Authentication:** Required (Bearer Token)

**Request Body:**

```json
{
  "password": "string (required) - New user password"
}
```

**Response:** `200 OK` - Password updated successfully.

---

#### Role
{:.no_toc}
Endpoints for managing roles.

###### GET `/v1/roles`
{:.no_toc}
List all roles.

**Authentication:** Required (Bearer Token)

**Response:** `200 OK` - Returns list of all roles.

---

###### GET `/v1/roles/{id}`
{:.no_toc}
Get information for a specific role.

**Authentication:** Required (Bearer Token)

**Path Parameters:**
- `id` (string, required) - Role ID

**Response:** `200 OK` - Returns role information.

---

#### Product Management
{:.no_toc}

###### Products
{:.no_toc}

GET `/v1/products`
List all products.

**Authentication:** Required (Bearer Token)

**Response:** `200 OK` - Returns list of all products.

---

POST `/v1/products`
Create a new product.

**Authentication:** Required (Bearer Token)

**Content-Type:** `multipart/form-data`

**Request Body:**

| Field | Type | Required | Description |
|---|---|---|---|
| `name` | string | Yes | Name of the product |
| `description` | string | Yes | Description of the product |
| `price` | number | Yes | Price of the product |
| `sales_unit` | string | Yes | Product sales unit (e.g., kg, piece, liter) |
| `categoryId` | number | Yes | Product category ID |
| `image` | file (binary) | Yes | Image file to upload |

**Response:** `201 Created` - Product created successfully.

---

GET `/v1/products/{id}`
Get information for a specific product.

**Authentication:** Required (Bearer Token)

**Path Parameters:**
- `id` (string, required) - Product ID

**Response:** `200 OK` - Returns product information.

---

PATCH `/v1/products/{id}`
Update a specific product.

**Authentication:** Required (Bearer Token)

**Path Parameters:**
- `id` (string, required) - Product ID

**Content-Type:** `multipart/form-data`

**Request Body:**

| Field | Type | Required | Description |
|---|---|---|---|
| `name` | string | Yes | Name of the product |
| `description` | string | Yes | Description of the product |
| `price` | number | Yes | Price of the product |
| `sales_unit` | string | Yes | Product sales unit |
| `categoryId` | number | Yes | Product category ID |
| `image` | file (binary) | No | Image file to upload |

**Response:** `200 OK` - Product updated successfully.

---

DELETE `/v1/products/{id}`
Delete a specific product.

**Authentication:** Required (Bearer Token)

**Path Parameters:**
- `id` (string, required) - Product ID

**Response:** `200 OK` - Product deleted successfully.

---

###### Product Categories
{:.no_toc}

GET `/v1/product-categories`
List all product categories.

**Authentication:** Required (Bearer Token)

**Response:** `200 OK` - Returns list of all product categories.

---

POST `/v1/product-categories`
Create a new product category.

**Authentication:** Required (Bearer Token)

**Content-Type:** `multipart/form-data`

**Request Body:**

| Field | Type | Required | Description |
|---|---|---|---|
| `name` | string | Yes | Name of the category |
| `image` | file (binary) | No | Image file to upload |

**Response:** `201 Created` - Category created successfully.

---

GET `/v1/product-categories/{id}`
Get information for a specific category.

**Authentication:** Required (Bearer Token)

**Path Parameters:**
- `id` (string, required) - Category ID

**Response:** `200 OK` - Returns category information.

---

PATCH `/v1/product-categories/{id}`
Update a specific category.

**Authentication:** Required (Bearer Token)

**Path Parameters:**
- `id` (string, required) - Category ID

**Content-Type:** `multipart/form-data`

**Request Body:**

| Field | Type | Required | Description |
|---|---|---|---|
| `name` | string | Yes | Name of the product category |
| `image` | file (binary) | No | Image file to upload |

**Response:** `200 OK` - Category updated successfully.

---

DELETE `/v1/product-categories/{id}`
Delete a specific category.

**Authentication:** Required (Bearer Token)

**Path Parameters:**
- `id` (string, required) - Category ID

**Response:** `200 OK` - Category deleted successfully.

---

#### Product Offers & Demands
{:.no_toc}

###### Product Offers
{:.no_toc}

GET `/v1/product-offers`
List all product offers.

**Authentication:** Required (Bearer Token)

**Response:** `200 OK` - Returns list of all product offers.

---

POST `/v1/product-offers`
Create a new product offer.

**Authentication:** Required (Bearer Token)

**Request Body:**

```json
{
  "productId": "number (required) - Product ID",
  "farmerId": "number (required) - Farmer ID",
  "quantity": "number (required) - Quantity available"
}
```

**Response:** `201 Created` - Product offer created successfully.

---

GET `/v1/product-offers/archived`
List all archived product offers.

**Authentication:** Required (Bearer Token)

**Response:** `200 OK` - Returns list of archived product offers.

---

GET `/v1/product-offers/farmer/{id}`
List product offers filtered by farmer.

**Authentication:** Required (Bearer Token)

**Path Parameters:**
- `id` (string, required) - Farmer ID

**Response:** `200 OK` - Returns filtered product offers.

---

GET `/v1/product-offers/product/{id}`
List product offers filtered by product.

**Authentication:** Required (Bearer Token)

**Path Parameters:**
- `id` (string, required) - Product ID

**Response:** `200 OK` - Returns filtered product offers.

---

GET `/v1/product-offers/{id}`
Get information for a specific offer.

**Authentication:** Required (Bearer Token)

**Path Parameters:**
- `id` (string, required) - Offer ID

**Response:** `200 OK` - Returns offer information.

---

PATCH `/v1/product-offers/{id}`
Update a specific product offer.

**Authentication:** Required (Bearer Token)

**Path Parameters:**
- `id` (string, required) - Offer ID

**Request Body:**

```json
{
  "productId": "number (optional) - Product ID",
  "farmerId": "number (optional) - Farmer ID",
  "quantity": "number (optional) - Quantity available"
}
```

**Response:** `200 OK` - Offer updated successfully.

---

DELETE `/v1/product-offers/{id}`
Delete a specific product offer.

**Authentication:** Required (Bearer Token)

**Path Parameters:**
- `id` (string, required) - Offer ID

**Response:** `200 OK` - Offer deleted successfully.

---

PUT `/v1/product-offers/archive/{id}`
Archive a specific product offer.

**Authentication:** Required (Bearer Token)

**Path Parameters:**
- `id` (string, required) - Offer ID

**Response:** `200 OK` - Offer archived successfully.

---

PUT `/v1/product-offers/unarchive/{id}`
Unarchive a specific product offer.

**Authentication:** Required (Bearer Token)

**Path Parameters:**
- `id` (string, required) - Offer ID

**Response:** `200 OK` - Offer unarchived successfully.

---

###### Product Demands
{:.no_toc}

GET `/v1/product-demands`
List all product demands.

**Authentication:** Required (Bearer Token)

**Response:** `200 OK` - Returns list of all product demands.

---

POST `/v1/product-demands`
Create a new product demand.

**Authentication:** Required (Bearer Token)

**Request Body:**

```json
{
  "productId": "number (required) - Product ID",
  "partnerId": "number (required) - Partner ID",
  "quantity": "number (required) - Quantity demanded",
  "deadline": "string (required) - Deadline date (ISO format)"
}
```

**Response:** `201 Created` - Product demand created successfully.

---

GET `/v1/product-demands/archived`
List all archived product demands.

**Authentication:** Required (Bearer Token)

**Response:** `200 OK` - Returns list of archived product demands.

---

GET `/v1/product-demands/partner/{id}`
List demands filtered by partner.

**Authentication:** Required (Bearer Token)

**Path Parameters:**
- `id` (string, required) - Partner ID

**Response:** `200 OK` - Returns filtered product demands.

---

GET `/v1/product-demands/product/{id}`
List demands filtered by product.

**Authentication:** Required (Bearer Token)

**Path Parameters:**
- `id` (string, required) - Product ID

**Response:** `200 OK` - Returns filtered product demands.

---

GET `/v1/product-demands/{id}`
Get information for a specific demand.

**Authentication:** Required (Bearer Token)

**Path Parameters:**
- `id` (string, required) - Demand ID

**Response:** `200 OK` - Returns demand information.

---

PATCH `/v1/product-demands/{id}`
Update a specific product demand.

**Authentication:** Required (Bearer Token)

**Path Parameters:**
- `id` (string, required) - Demand ID

**Request Body:**

```json
{
  "productId": "number (optional) - Product ID",
  "partnerId": "number (optional) - Partner ID",
  "quantity": "number (optional) - Quantity demanded",
  "deadline": "string (optional) - Deadline date (ISO format)"
}
```

**Response:** `200 OK` - Demand updated successfully.

---

DELETE `/v1/product-demands/{id}`
Delete a specific product demand.

**Authentication:** Required (Bearer Token)

**Path Parameters:**
- `id` (string, required) - Demand ID

**Response:** `200 OK` - Demand deleted successfully.

---

PUT `/v1/product-demands/{id}/archive`
Archive a specific product demand.

**Authentication:** Required (Bearer Token)

**Path Parameters:**
- `id` (string, required) - Demand ID

**Response:** `200 OK` - Demand archived successfully.

---

PUT `/v1/product-demands/{id}/unarchive`
Unarchive a specific product demand.

**Authentication:** Required (Bearer Token)

**Path Parameters:**
- `id` (string, required) - Demand ID

**Response:** `200 OK` - Demand unarchived successfully.

---

#### Post Management
{:.no_toc}

###### Posts
{:.no_toc}

GET `/v1/posts`
List all posts.

**Authentication:** Required (Bearer Token)

**Response:** `200 OK` - Returns list of all posts.

---

POST `/v1/posts`
Create a new post.

**Authentication:** Required (Bearer Token)

**Content-Type:** `multipart/form-data`

**Request Body:**

| Field | Type | Required | Description |
|---|---|---|---|
| `idCategory` | number | Yes | Post category ID |
| `author` | string | Yes | Post author |
| `title` | string | Yes | Post title |
| `description` | string | Yes | Post description |
| `image` | file (binary) | No | Post image |
| `attachment` | file (binary) | Yes | Post attachment file |
| `attachmentKb` | file (binary) | Yes | Post attachment in Kabye language |
| `attachmentPdf` | file (binary) | Yes | Post attachment in PDF format |
| `tags` | string | Yes | Post tags list (comma-separated or array) |
| `resources` | string | No | Post resources list (comma-separated or array) |

**Response:** `201 Created` - Post created successfully.

---

GET `/v1/posts/resource/{id}`
List posts filtered by a specific resource.

**Authentication:** Required (Bearer Token)

**Path Parameters:**
- `id` (string, required) - Resource ID

**Response:** `200 OK` - Returns filtered posts.

---

GET `/v1/posts/tag/{id}`
List posts filtered by a specific tag.

**Authentication:** Required (Bearer Token)

**Path Parameters:**
- `id` (string, required) - Tag ID

**Response:** `200 OK` - Returns filtered posts.

---

GET `/v1/posts/{id}`
Get information for a specific post.

**Authentication:** Required (Bearer Token)

**Path Parameters:**
- `id` (string, required) - Post ID

**Response:** `200 OK` - Returns post information.

---

PATCH `/v1/posts/{id}`
Update a specific post.

**Authentication:** Required (Bearer Token)

**Path Parameters:**
- `id` (string, required) - Post ID

**Content-Type:** `multipart/form-data`

**Request Body:**

| Field | Type | Required | Description |
|---|---|---|---|
| `idCategory` | number | Yes | Post category ID |
| `author` | string | Yes | Post author |
| `title` | string | Yes | Post title |
| `description` | string | Yes | Post description |
| `image` | file (binary) | No | Post image |
| `attachment` | file (binary) | No | Post attachment file |
| `attachmentKb` | file (binary) | No | Post attachment in Kabye language |
| `attachmentPdf` | file (binary) | No | Post attachment in PDF format |
| `tags` | string | Yes | Post tags list |
| `resources` | string | No | Post resources list |

**Response:** `200 OK` - Post updated successfully.

---

DELETE `/v1/posts/{id}`
Delete a specific post.

**Authentication:** Required (Bearer Token)

**Path Parameters:**
- `id` (string, required) - Post ID

**Response:** `200 OK` - Post deleted successfully.

---

###### Post Categories
{:.no_toc}

GET `/v1/post-categories`
List all post categories.

**Authentication:** Required (Bearer Token)

**Response:** `200 OK` - Returns list of all post categories.

---

POST `/v1/post-categories`
Create a new post category.

**Authentication:** Required (Bearer Token)

**Content-Type:** `multipart/form-data`

**Request Body:**

| Field | Type | Required | Description |
|---|---|---|---|
| `name` | string | Yes | Name of the category |
| `nameKb` | string | Yes | Name of the category in Kabye |
| `image` | file (binary) | No | Image file to upload |

**Response:** `201 Created` - Category created successfully.

---

GET `/v1/post-categories/{id}`
Get information for a specific category.

**Authentication:** Required (Bearer Token)

**Path Parameters:**
- `id` (string, required) - Category ID

**Response:** `200 OK` - Returns category information.

---

PATCH `/v1/post-categories/{id}`
Update a specific category.

**Authentication:** Required (Bearer Token)

**Path Parameters:**
- `id` (string, required) - Category ID

**Content-Type:** `multipart/form-data`

**Request Body:**

| Field | Type | Required | Description |
|---|---|---|---|
| `name` | string | Yes | Name of the category |
| `nameKb` | string | Yes | Name of the category in Kabye |
| `image` | file (binary) | No | Image file to upload |

**Response:** `200 OK` - Category updated successfully.

---

DELETE `/v1/post-categories/{id}`
Delete a specific category.

**Authentication:** Required (Bearer Token)

**Path Parameters:**
- `id` (string, required) - Category ID

**Response:** `200 OK` - Category deleted successfully.

---

###### Post Tags
{:.no_toc}

GET `/v1/tags`
List all tags.

**Authentication:** Required (Bearer Token)

**Response:** `200 OK` - Returns list of all tags.

---

POST `/v1/tags`
Create a new tag.

**Authentication:** Required (Bearer Token)

**Content-Type:** `multipart/form-data`

**Request Body:**

| Field | Type | Required | Description |
|---|---|---|---|
| `name` | string | No | Name of the tag |
| `image` | file (binary) | Yes | Image file to upload |

**Response:** `201 Created` - Tag created successfully.

---

GET `/v1/tags/{id}`
Get information for a specific tag.

**Authentication:** Required (Bearer Token)

**Path Parameters:**
- `id` (string, required) - Tag ID

**Response:** `200 OK` - Returns tag information.

---

PATCH `/v1/tags/{id}`
Update a specific tag.

**Authentication:** Required (Bearer Token)

**Path Parameters:**
- `id` (string, required) - Tag ID

**Content-Type:** `multipart/form-data`

**Request Body:**

| Field | Type | Required | Description |
|---|---|---|---|
| `name` | string | Yes | Name of the tag |
| `image` | file (binary) | No | Image file to upload |

**Response:** `200 OK` - Tag updated successfully.

---

DELETE `/v1/tags/{id}`
Delete a specific tag.

**Authentication:** Required (Bearer Token)

**Path Parameters:**
- `id` (string, required) - Tag ID

**Response:** `200 OK` - Tag deleted successfully.

---

###### Post Resources
{:.no_toc}

GET `/v1/resource`
List all resources.

**Authentication:** Required (Bearer Token)

**Response:** `200 OK` - Returns list of all resources.

---

POST `/v1/resource`
Create a new resource.

**Authentication:** Required (Bearer Token)

**Content-Type:** `multipart/form-data`

**Request Body:**

| Field | Type | Required | Description |
|---|---|---|---|
| `name` | string | Yes | Name of the resource |
| `image` | file (binary) | Yes | Image file to upload |

**Response:** `201 Created` - Resource created successfully.

---

GET `/v1/resource/{id}`
Get information for a specific resource.

**Authentication:** Required (Bearer Token)

**Path Parameters:**
- `id` (string, required) - Resource ID

**Response:** `200 OK` - Returns resource information.

---

PATCH `/v1/resource/{id}`
Update a specific resource.

**Authentication:** Required (Bearer Token)

**Path Parameters:**
- `id` (string, required) - Resource ID

**Content-Type:** `multipart/form-data`

**Request Body:**

| Field | Type | Required | Description |
|---|---|---|---|
| `name` | string | Yes | Name of the resource |
| `image` | file (binary) | No | Image file to upload |

**Response:** `200 OK` - Resource updated successfully.

---

DELETE `/v1/resource/{id}`
Delete a specific resource.

**Authentication:** Required (Bearer Token)

**Path Parameters:**
- `id` (string, required) - Resource ID

**Response:** `200 OK` - Resource deleted successfully.

---

#### Configuration
{:.no_toc}

###### GET `/v1/config`
{:.no_toc}
Get the current configuration.

**Authentication:** Required (Bearer Token)

**Response:** `200 OK` - Returns current community configuration.

---

###### PATCH `/v1/config`
{:.no_toc}
Update the default configuration.

**Authentication:** Required (Bearer Token)

**Request Body:**

```json
{
  "name": "string (optional) - Community name",
  "intro": "string (optional) - Community introduction",
  "adresse": "string (optional) - Community address",
  "location": "string (optional) - Community location",
  "whatsappLink": "string (optional) - Advice center WhatsApp link",
  "stationLink": "string (optional) - Teleagriculture station link"
}
```

**Response:** `200 OK` - Configuration updated successfully.

---

#### Weather
{:.no_toc}

###### GET `/v1/weather`
{:.no_toc}
List weather data.

**Query Parameters:**
- `limit` (number, required) - Number of records to retrieve

**Authentication:** Not required

**Response:** `200 OK` - Returns list of weather data.

---

###### POST `/v1/weather`
{:.no_toc}
Sync weather from the teleagriculture station.

**Authentication:** Not required

**Request Body:**

```json
{
  "temp": "number (optional) - Main temperature in °C (example: 22)",
  "temp1": "number (optional) - Secondary temperature in °C (example: 21.8)",
  "hum": "number (optional) - Main humidity percentage (example: 45)",
  "hum1": "number (optional) - Secondary humidity percentage (example: 47.2)",
  "press": "number (optional) - Atmospheric pressure in hPa (example: 1013.25)",
  "lux": "number (optional) - Luminosity in lux (example: 320.5)",
  "ambient": "number (optional) - Ambient light sensor raw value (example: 215)",
  "CO": "number (optional) - Carbon monoxide concentration in ppm (example: 0.5)",
  "NO2": "number (optional) - Nitrogen dioxide concentration in ppb (example: 12)",
  "wind_dir": "number (optional) - Wind direction in degrees (example: 180)",
  "wind_spd": "number (optional) - Wind speed in m/s (example: 5.2)",
  "uv": "number (optional) - UV index (example: 6)",
  "battery": "number (optional) - Battery level in % (example: 85)",
  "time": "string (optional) - Time of the measurement (ISO format)"
}
```

**Response:** `201 Created` - Weather data synced successfully.

---

###### GET `/v1/weather/current`
{:.no_toc}
Get the current weather details.

**Authentication:** Not required

**Response:** `200 OK` - Returns current weather information.

---

###### GET `/v1/weather/download`
{:.no_toc}
Download weather data as a spreadsheet.

**Authentication:** Not required

**Response:** `200 OK` - Returns weather data in spreadsheet format (file download).

---

#### Partners
{:.no_toc}

###### GET `/v1/partners`
{:.no_toc}
List all partners.

**Authentication:** Required (Bearer Token)

**Response:** `200 OK` - Returns list of all partners.

---

###### POST `/v1/partners`
{:.no_toc}
Create a new partner.

**Authentication:** Required (Bearer Token)

**Request Body:**

```json
{
  "name": "string (required) - Partner's name",
  "adresse": "string (required) - Partner's address (city, village, etc.)",
  "phone": "string (required) - Partner's phone number"
}
```

**Response:** `201 Created` - Partner created successfully.

---

###### GET `/v1/partners/{id}`
{:.no_toc}
Get information for a specific partner.

**Authentication:** Required (Bearer Token)

**Path Parameters:**
- `id` (string, required) - Partner ID

**Response:** `200 OK` - Returns partner information.

---

###### PATCH `/v1/partners/{id}`
{:.no_toc}
Update a specific partner.

**Authentication:** Required (Bearer Token)

**Path Parameters:**
- `id` (string, required) - Partner ID

**Request Body:**

```json
{
  "name": "string (optional) - Partner's name",
  "adresse": "string (optional) - Partner's address (city, village, etc.)",
  "phone": "string (optional) - Partner's phone number"
}
```

**Response:** `200 OK` - Partner updated successfully.

---

###### DELETE `/v1/partners/{id}`
{:.no_toc}
Delete a specific partner.

**Authentication:** Required (Bearer Token)

**Path Parameters:**
- `id` (string, required) - Partner ID

**Response:** `200 OK` - Partner deleted successfully.

---

#### Utilities
{:.no_toc}

###### Backup
{:.no_toc}

GET `/backup/create`
Create a system backup (files & database dump).

**Authentication:** Not required

**Response:** `200 OK` - Backup created successfully.

---

###### Nginx Logs
{:.no_toc}

GET `/v1/nginx-logs`
Read raw Nginx log files.

**Authentication:** Required (Bearer Token)

**Query Parameters:**
| Parameter | Type | Required | Description |
|---|---|---|---|
| `lines` | number | No | Number of lines to retrieve (default: 500) |
| `type` | string | No | Type of log to read: `access`, `error`, or `default` |

**Response:** `200 OK` - Returns the requested Nginx logs.

---

DELETE `/v1/nginx-logs`
Empty all log files.

**Authentication:** Required (Bearer Token)

**Response:** `200 OK` - All log files emptied successfully.

---

###### Forum
{:.no_toc}

GET `/v1/forum`
List all forum entries.

**Authentication:** Required (Bearer Token)

**Response:** `200 OK` - Returns list of all forum entries.

---

DELETE `/v1/forum/{id}`
Remove a specific forum entry.

**Authentication:** Required (Bearer Token)

**Path Parameters:**
- `id` (string, required) - Forum entry ID

**Response:** `200 OK` - Forum entry removed successfully.

## Forum API

When running the project in **development mode** with `npx nx dev minodu-forum`, the full Swagger/OpenAPI documentation is available interactively at `http://localhost:3003/docs`

When runnding the project in **release mode** with `npm run docker:start`in root dir, the docuemation is available at: `http://localhost/api/forum/docs`
<!-- Generator: Widdershins v4.0.1 -->

> Scroll down for code samples, example requests and responses. Select a language for code samples from the tabs above or the mobile navigation menu.

Base URLs:

* <a href="/api/forum">/api/forum</a>

### Authentication

- HTTP Authentication, scheme: bearer 

#### Root
{:.no_toc}

`GET /`

> Example responses

> 200 Response

```json
null
```

<h3 id="root-responses">Responses</h3>

|Status|Meaning|Description|Schema|
|---|---|---|---|
|200|[OK](https://tools.ietf.org/html/rfc7231#section-6.3.1)|Successful Response|Inline|

<h3 id="root-responseschema">Response Schema</h3>

<aside class="success">
This operation does not require authentication
</aside>

#### Get Posts
{:.no_toc}

`GET /posts/`

> Example responses

> 200 Response

```json
[
  {
    "id": 0,
    "title": "string",
    "text": "string",
    "created_at": "2019-08-24T14:15:22Z",
    "updated_at": "2019-08-24T14:15:22Z",
    "parent_id": 0,
    "author": {
      "id": 0,
      "name": "string",
      "avatar": {
        "id": 0,
        "filename": "string",
        "file_urlpath": "string",
        "color": "string"
      }
    },
    "files": [
      {
        "id": 0,
        "text": "string",
        "filename": "string",
        "content_type": "string",
        "file_hash": "string",
        "file_urlpath": "string",
        "processing_state": "processing"
      }
    ]
  }
]
```

<h3 id="get-posts-responses">Responses</h3>
{:.no_toc}

|Status|Meaning|Description|Schema|
|---|---|---|---|
|200|[OK](https://tools.ietf.org/html/rfc7231#section-6.3.1)|Successful Response|Inline|

<h3 id="get-posts-responseschema">Response Schema</h3>
{:.no_toc}

Status Code **200**

*Response Get Posts Posts  Get*

|Name|Type|Required|Restrictions|Description|
|---|---|---|---|---|
|Response Get Posts Posts  Get|[[PostResponse](#schemapostresponse)]|false|none|none|

*anyOf*

|Name|Type|Required|Restrictions|Description|
|---|---|---|---|---|
| |

*or*

|Name|Type|Required|Restrictions|Description|
|---|---|---|---|---|
| |

*continued*

|Name|Type|Required|Restrictions|Description|
|---|---|---|---|---|
| |

*anyOf*

|Name|Type|Required|Restrictions|Description|
|---|---|---|---|---|
| |

*or*

|Name|Type|Required|Restrictions|Description|
|---|---|---|---|---|
| |

*continued*

|Name|Type|Required|Restrictions|Description|
|---|---|---|---|---|
|»» files|[[FileResponse](#schemafileresponse)]|true|none|none|

<aside class="success">
This operation does not require authentication
</aside>

#### Create Post
{:.no_toc}

`POST /posts/`

> Body parameter

```json
{
  "title": "string",
  "text": "string",
  "parent_id": 0
}
```

<h3 id="create-post-parameters">Parameters</h3>
{:.no_toc}

|Name|In|Type|Required|Description|
|---|---|---|---|---|
|body|body|[PostCreate](#schemapostcreate)|true|none|

> Example responses

> 200 Response

```json
{
  "id": 0,
  "title": "string",
  "text": "string",
  "created_at": "2019-08-24T14:15:22Z",
  "updated_at": "2019-08-24T14:15:22Z",
  "parent_id": 0,
  "author": {
    "id": 0,
    "name": "string",
    "avatar": {
      "id": 0,
      "filename": "string",
      "file_urlpath": "string",
      "color": "string"
    }
  },
  "files": [
    {
      "id": 0,
      "text": "string",
      "filename": "string",
      "content_type": "string",
      "file_hash": "string",
      "file_urlpath": "string",
      "processing_state": "processing"
    }
  ]
}
```

<h3 id="create-post-responses">Responses</h3>
{:.no_toc}

|Status|Meaning|Description|Schema|
|---|---|---|---|
|200|[OK](https://tools.ietf.org/html/rfc7231#section-6.3.1)|Successful Response|[PostResponse](#schemapostresponse)|
|422|[Unprocessable Entity](https://tools.ietf.org/html/rfc2518#section-10.3)|Validation Error|[HTTPValidationError](#schemahttpvalidationerror)|

<aside class="warning">
To perform this operation, you must be authenticated by means of one of the following methods:
HTTPBearer
</aside>

#### Get Posts Paginated
{:.no_toc}

`GET /posts/paginated/`

<h3 id="get-posts-paginated-parameters">Parameters</h3>
{:.no_toc}

|Name|In|Type|Required|Description|
|---|---|---|---|---|
|before|query|any|false|none|
|limit|query|integer|false|none|

> Example responses

> 200 Response

```json
{
  "posts": [
    {
      "id": 0,
      "title": "string",
      "text": "string",
      "created_at": "2019-08-24T14:15:22Z",
      "updated_at": "2019-08-24T14:15:22Z",
      "parent_id": 0,
      "author": {
        "id": 0,
        "name": "string",
        "avatar": {
          "id": 0,
          "filename": "string",
          "file_urlpath": "string",
          "color": "string"
        }
      },
      "files": [
        {
          "id": 0,
          "text": "string",
          "filename": "string",
          "content_type": "string",
          "file_hash": "string",
          "file_urlpath": "string",
          "processing_state": "processing"
        }
      ]
    }
  ],
  "has_more": true
}
```

<h3 id="get-posts-paginated-responses">Responses</h3>
{:.no_toc}

|Status|Meaning|Description|Schema|
|---|---|---|---|
|200|[OK](https://tools.ietf.org/html/rfc7231#section-6.3.1)|Successful Response|[PaginatedPostsResponse](#schemapaginatedpostsresponse)|
|422|[Unprocessable Entity](https://tools.ietf.org/html/rfc2518#section-10.3)|Validation Error|[HTTPValidationError](#schemahttpvalidationerror)|

<aside class="success">
This operation does not require authentication
</aside>

#### Get Threads
{:.no_toc}

`GET /posts/threads`

> Example responses

> 200 Response

```json
[
  {
    "id": 0,
    "title": "string",
    "text": "string",
    "created_at": "2019-08-24T14:15:22Z",
    "updated_at": "2019-08-24T14:15:22Z",
    "author": {
      "id": 0,
      "name": "string",
      "avatar": {
        "id": 0,
        "filename": "string",
        "file_urlpath": "string",
        "color": "string"
      }
    },
    "files": [
      {
        "id": 0,
        "text": "string",
        "filename": "string",
        "content_type": "string",
        "file_hash": "string",
        "file_urlpath": "string",
        "processing_state": "processing"
      }
    ],
    "children": [
      {
        "id": 0,
        "title": "string",
        "text": "string",
        "created_at": "2019-08-24T14:15:22Z",
        "updated_at": "2019-08-24T14:15:22Z",
        "parent_id": 0,
        "author": {
          "id": 0,
          "name": "string",
          "avatar": {
            "id": 0,
            "filename": "string",
            "file_urlpath": "string",
            "color": "string"
          }
        },
        "files": [
          {
            "id": 0,
            "text": "string",
            "filename": "string",
            "content_type": "string",
            "file_hash": "string",
            "file_urlpath": "string",
            "processing_state": "processing"
          }
        ]
      }
    ]
  }
]
```

<h3 id="get-threads-responses">Responses</h3>
{:.no_toc}

|Status|Meaning|Description|Schema|
|---|---|---|---|
|200|[OK](https://tools.ietf.org/html/rfc7231#section-6.3.1)|Successful Response|Inline|

<h3 id="get-threads-responseschema">Response Schema</h3>
{:.no_toc}

Status Code **200**

*Response Get Threads Posts Threads Get*

|Name|Type|Required|Restrictions|Description|
|---|---|---|---|---|
|Response Get Threads Posts Threads Get|[[ThreadResponse](#schemathreadresponse)]|false|none|none|

*anyOf*

|Name|Type|Required|Restrictions|Description|
|---|---|---|---|---|
| |

*or*

|Name|Type|Required|Restrictions|Description|
|---|---|---|---|---|
| |

*continued*

|Name|Type|Required|Restrictions|Description|
|---|---|---|---|---|
|»» files|[[FileResponse](#schemafileresponse)]|true|none|none|
|»» children|[[PostResponse](#schemapostresponse)]|true|none|none|

*anyOf*

|Name|Type|Required|Restrictions|Description|
|---|---|---|---|---|
| |

*or*

|Name|Type|Required|Restrictions|Description|
|---|---|---|---|---|
| |

*continued*

|Name|Type|Required|Restrictions|Description|
|---|---|---|---|---|
| |

<aside class="success">
This operation does not require authentication
</aside>

#### Get Post
{:.no_toc}

`GET /posts/{post_id}`

<h3 id="get-post-parameters">Parameters</h3>

|Name|In|Type|Required|Description|
|---|---|---|---|---|
|post_id|path|integer|true|none|

> Example responses

> 200 Response

```json
{
  "id": 0,
  "title": "string",
  "text": "string",
  "created_at": "2019-08-24T14:15:22Z",
  "updated_at": "2019-08-24T14:15:22Z",
  "parent_id": 0,
  "author": {
    "id": 0,
    "name": "string",
    "avatar": {
      "id": 0,
      "filename": "string",
      "file_urlpath": "string",
      "color": "string"
    }
  },
  "files": [
    {
      "id": 0,
      "text": "string",
      "filename": "string",
      "content_type": "string",
      "file_hash": "string",
      "file_urlpath": "string",
      "processing_state": "processing"
    }
  ]
}
```

<h3 id="get-post-responses">Responses</h3>
{:.no_toc}

|Status|Meaning|Description|Schema|
|---|---|---|---|
|200|[OK](https://tools.ietf.org/html/rfc7231#section-6.3.1)|Successful Response|[PostResponse](#schemapostresponse)|
|422|[Unprocessable Entity](https://tools.ietf.org/html/rfc2518#section-10.3)|Validation Error|[HTTPValidationError](#schemahttpvalidationerror)|

<aside class="success">
This operation does not require authentication
</aside>

#### Edit Post
{:.no_toc}

`PUT /posts/{post_id}`

> Body parameter

```json
{
  "title": "string",
  "text": "string"
}
```

<h3 id="edit-post-parameters">Parameters</h3>
{:.no_toc}

|Name|In|Type|Required|Description|
|---|---|---|---|---|
|post_id|path|integer|true|none|
|body|body|[PostEdit](#schemapostedit)|true|none|

> Example responses

> 200 Response

```json
{
  "id": 0,
  "title": "string",
  "text": "string",
  "created_at": "2019-08-24T14:15:22Z",
  "updated_at": "2019-08-24T14:15:22Z",
  "parent_id": 0,
  "author": {
    "id": 0,
    "name": "string",
    "avatar": {
      "id": 0,
      "filename": "string",
      "file_urlpath": "string",
      "color": "string"
    }
  },
  "files": [
    {
      "id": 0,
      "text": "string",
      "filename": "string",
      "content_type": "string",
      "file_hash": "string",
      "file_urlpath": "string",
      "processing_state": "processing"
    }
  ]
}
```

<h3 id="edit-post-responses">Responses</h3>
{:.no_toc}

|Status|Meaning|Description|Schema|
|---|---|---|---|
|200|[OK](https://tools.ietf.org/html/rfc7231#section-6.3.1)|Successful Response|[PostResponse](#schemapostresponse)|
|422|[Unprocessable Entity](https://tools.ietf.org/html/rfc2518#section-10.3)|Validation Error|[HTTPValidationError](#schemahttpvalidationerror)|

<aside class="warning">
To perform this operation, you must be authenticated by means of one of the following methods:
HTTPBearer
</aside>

#### Delete File
{:.no_toc}

`DELETE /posts/{post_id}`

<h3 id="delete-file-parameters">Parameters</h3>
{:.no_toc}

|Name|In|Type|Required|Description|
|---|---|---|---|---|
|post_id|path|integer|true|none|

> Example responses

> 200 Response

```json
null
```

<h3 id="delete-file-responses">Responses</h3>
{:.no_toc}

|Status|Meaning|Description|Schema|
|---|---|---|---|
|200|[OK](https://tools.ietf.org/html/rfc7231#section-6.3.1)|Successful Response|Inline|
|422|[Unprocessable Entity](https://tools.ietf.org/html/rfc2518#section-10.3)|Validation Error|[HTTPValidationError](#schemahttpvalidationerror)|

<h3 id="delete-file-responseschema">Response Schema</h3>
{:.no_toc}

<aside class="warning">
To perform this operation, you must be authenticated by means of one of the following methods:
HTTPBearer
</aside>

#### Get Authors
{:.no_toc}

`GET /authors/`

> Example responses

> 200 Response

```json
[
  {
    "id": 0,
    "name": "string",
    "avatar": {
      "id": 0,
      "filename": "string",
      "file_urlpath": "string",
      "color": "string"
    }
  }
]
```

<h3 id="get-authors-responses">Responses</h3>
{:.no_toc}

|Status|Meaning|Description|Schema|
|---|---|---|---|
|200|[OK](https://tools.ietf.org/html/rfc7231#section-6.3.1)|Successful Response|Inline|

<h3 id="get-authors-responseschema">Response Schema</h3>
{:.no_toc}

Status Code **200**

*Response Get Authors Authors  Get*

|Name|Type|Required|Restrictions|Description|
|---|---|---|---|---|
|Response Get Authors Authors  Get|[[AuthorResponse](#schemaauthorresponse)]|false|none|none|

<aside class="success">
This operation does not require authentication
</aside>

#### Get Post
{:.no_toc}

`GET /authors/{author_id}`

<h3 id="get-post-parameters">Parameters</h3>
{:.no_toc}

|Name|In|Type|Required|Description|
|---|---|---|---|---|
|author_id|path|integer|true|none|

> Example responses

> 200 Response

```json
{
  "id": 0,
  "name": "string",
  "avatar": {
    "id": 0,
    "filename": "string",
    "file_urlpath": "string",
    "color": "string"
  }
}
```

<h3 id="get-post-responses">Responses</h3>
{:.no_toc}

|Status|Meaning|Description|Schema|
|---|---|---|---|
|200|[OK](https://tools.ietf.org/html/rfc7231#section-6.3.1)|Successful Response|[AuthorResponse](#schemaauthorresponse)|
|422|[Unprocessable Entity](https://tools.ietf.org/html/rfc2518#section-10.3)|Validation Error|[HTTPValidationError](#schemahttpvalidationerror)|

<aside class="success">
This operation does not require authentication
</aside>

#### Edit Author
{:.no_toc}

`PUT /authors/{author_id}`

> Body parameter

```json
{
  "name": "string",
  "avatar": 0
}
```

<h3 id="edit-author-parameters">Parameters</h3>
{:.no_toc}

|Name|In|Type|Required|Description|
|---|---|---|---|---|
|author_id|path|integer|true|none|
|body|body|[AuthorEdit](#schemaauthoredit)|true|none|

> Example responses

> 200 Response

```json
{
  "id": 0,
  "name": "string",
  "avatar": {
    "id": 0,
    "filename": "string",
    "file_urlpath": "string",
    "color": "string"
  }
}
```

<h3 id="edit-author-responses">Responses</h3>
{:.no_toc}

|Status|Meaning|Description|Schema|
|---|---|---|---|
|200|[OK](https://tools.ietf.org/html/rfc7231#section-6.3.1)|Successful Response|[AuthorResponse](#schemaauthorresponse)|
|422|[Unprocessable Entity](https://tools.ietf.org/html/rfc2518#section-10.3)|Validation Error|[HTTPValidationError](#schemahttpvalidationerror)|

<aside class="warning">
To perform this operation, you must be authenticated by means of one of the following methods:
HTTPBearer
</aside>

#### Create Author
{:.no_toc}

`POST /authors/create`

> Body parameter

```json
{
  "name": "string",
  "avatar": 0
}
```

<h3 id="create-author-parameters">Parameters</h3>
{:.no_toc}

|Name|In|Type|Required|Description|
|---|---|---|---|---|
|body|body|[AuthorCreate](#schemaauthorcreate)|true|none|

> Example responses

> 200 Response

```json
{
  "token": "string",
  "id": 0
}
```

<h3 id="create-author-responses">Responses</h3>
{:.no_toc}

|Status|Meaning|Description|Schema|
|---|---|---|---|
|200|[OK](https://tools.ietf.org/html/rfc7231#section-6.3.1)|Successful Response|[AuthorCreateResponse](#schemaauthorcreateresponse)|
|422|[Unprocessable Entity](https://tools.ietf.org/html/rfc2518#section-10.3)|Validation Error|[HTTPValidationError](#schemahttpvalidationerror)|

<aside class="success">
This operation does not require authentication
</aside>

#### Get Files
{:.no_toc}

`GET /files/`

> Example responses

> 200 Response

```json
[
  {
    "id": 0,
    "text": "string",
    "filename": "string",
    "content_type": "string",
    "file_hash": "string",
    "file_urlpath": "string",
    "processing_state": "processing"
  }
]
```

<h3 id="get-files-responses">Responses</h3>
{:.no_toc}

|Status|Meaning|Description|Schema|
|---|---|---|---|
|200|[OK](https://tools.ietf.org/html/rfc7231#section-6.3.1)|Successful Response|Inline|

<h3 id="get-files-responseschema">Response Schema</h3>
{:.no_toc}

Status Code **200**

*Response Get Files Files  Get*

|Name|Type|Required|Restrictions|Description|
|---|---|---|---|---|
|Response Get Files Files  Get|[[FileResponse](#schemafileresponse)]|false|none|none|

<aside class="success">
This operation does not require authentication
</aside>

#### Get File
{:.no_toc}

`GET /files/{file_id}`

<h3 id="get-file-parameters">Parameters</h3>
{:.no_toc}

|Name|In|Type|Required|Description|
|---|---|---|---|---|
|file_id|path|integer|true|none|

> Example responses

> 200 Response

```json
{
  "id": 0,
  "text": "string",
  "filename": "string",
  "content_type": "string",
  "file_hash": "string",
  "file_urlpath": "string",
  "processing_state": "processing"
}
```

<h3 id="get-file-responses">Responses</h3>
{:.no_toc}

|Status|Meaning|Description|Schema|
|---|---|---|---|
|200|[OK](https://tools.ietf.org/html/rfc7231#section-6.3.1)|Successful Response|[FileResponse](#schemafileresponse)|
|422|[Unprocessable Entity](https://tools.ietf.org/html/rfc2518#section-10.3)|Validation Error|[HTTPValidationError](#schemahttpvalidationerror)|

<aside class="success">
This operation does not require authentication
</aside>

#### Delete File
{:.no_toc}

`DELETE /files/{file_id}`

<h3 id="delete-file-parameters">Parameters</h3>
{:.no_toc}

|Name|In|Type|Required|Description|
|---|---|---|---|---|
|file_id|path|integer|true|none|

> Example responses

> 200 Response

```json
null
```

<h3 id="delete-file-responses">Responses</h3>
{:.no_toc}

|Status|Meaning|Description|Schema|
|---|---|---|---|
|200|[OK](https://tools.ietf.org/html/rfc7231#section-6.3.1)|Successful Response|Inline|
|422|[Unprocessable Entity](https://tools.ietf.org/html/rfc2518#section-10.3)|Validation Error|[HTTPValidationError](#schemahttpvalidationerror)|

<h3 id="delete-file-responseschema">Response Schema</h3>
{:.no_toc}

<aside class="warning">
To perform this operation, you must be authenticated by means of one of the following methods:
HTTPBearer
</aside>

#### Upload File
{:.no_toc}

`POST /files/upload`

> Body parameter

```yaml
file: string
post_id: 0
language: string

```

<h3 id="upload-file-parameters">Parameters</h3>
{:.no_toc}

|Name|In|Type|Required|Description|
|---|---|---|---|---|
|body|body|[Body_upload_file_files_upload_post](#schemabody_upload_file_files_upload_post)|true|none|

> Example responses

> 200 Response

```json
{
  "id": 0,
  "text": "string",
  "filename": "string",
  "content_type": "string",
  "file_hash": "string",
  "file_urlpath": "string",
  "processing_state": "processing"
}
```

<h3 id="upload-file-responses">Responses</h3>
{:.no_toc}

|Status|Meaning|Description|Schema|
|---|---|---|---|
|200|[OK](https://tools.ietf.org/html/rfc7231#section-6.3.1)|Successful Response|[FileResponse](#schemafileresponse)|
|422|[Unprocessable Entity](https://tools.ietf.org/html/rfc2518#section-10.3)|Validation Error|[HTTPValidationError](#schemahttpvalidationerror)|

<aside class="warning">
To perform this operation, you must be authenticated by means of one of the following methods:
HTTPBearer
</aside>

#### Get Avatars
{:.no_toc}

`GET /avatars/`

> Example responses

> 200 Response

```json
[
  {
    "id": 0,
    "filename": "string",
    "file_urlpath": "string",
    "color": "string"
  }
]
```

<h3 id="get-avatars-responses">Responses</h3>
{:.no_toc}

|Status|Meaning|Description|Schema|
|---|---|---|---|
|200|[OK](https://tools.ietf.org/html/rfc7231#section-6.3.1)|Successful Response|Inline|

<h3 id="get-avatars-responseschema">Response Schema</h3>
{:.no_toc}

Status Code **200**

*Response Get Avatars Avatars  Get*

|Name|Type|Required|Restrictions|Description|
|---|---|---|---|---|
|Response Get Avatars Avatars  Get|[[AvatarResponse](#schemaavatarresponse)]|false|none|none|

<aside class="success">
This operation does not require authentication
</aside>

#### Check Login
{:.no_toc}

`GET /login/`

> Example responses

> 200 Response

```json
{
  "id": 0,
  "name": "string",
  "avatar": {
    "id": 0,
    "filename": "string",
    "file_urlpath": "string",
    "color": "string"
  }
}
```

<h3 id="check-login-responses">Responses</h3>
{:.no_toc}

|Status|Meaning|Description|Schema|
|---|---|---|---|
|200|[OK](https://tools.ietf.org/html/rfc7231#section-6.3.1)|Successful Response|[AuthorResponse](#schemaauthorresponse)|

<aside class="warning">
To perform this operation, you must be authenticated by means of one of the following methods:
HTTPBearer
</aside>

#### Stream Events
{:.no_toc}

`GET /events/`

> Example responses

> 200 Response

```json
null
```

<h3 id="stream-events-responses">Responses</h3>
{:.no_toc}

|Status|Meaning|Description|Schema|
|---|---|---|---|
|200|[OK](https://tools.ietf.org/html/rfc7231#section-6.3.1)|Successful Response|Inline|

<h3 id="stream-events-responseschema">Response Schema</h3>
{:.no_toc}

<aside class="success">
This operation does not require authentication
</aside>

#### Delete File
{:.no_toc}

`DELETE /admin/posts/{post_id}`

<h3 id="delete-file-parameters">Parameters</h3>
{:.no_toc}

|Name|In|Type|Required|Description|
|---|---|---|---|---|
|post_id|path|integer|true|none|
|X-Admin-Password|header|string|false|none|

> Example responses

> 200 Response

```json
null
```

<h3 id="delete-file-responses">Responses</h3>
{:.no_toc}

|Status|Meaning|Description|Schema|
|---|---|---|---|
|200|[OK](https://tools.ietf.org/html/rfc7231#section-6.3.1)|Successful Response|Inline|
|422|[Unprocessable Entity](https://tools.ietf.org/html/rfc2518#section-10.3)|Validation Error|[HTTPValidationError](#schemahttpvalidationerror)|

<h3 id="delete-file-responseschema">Response Schema</h3>
{:.no_toc}

<aside class="success">
This operation does not require authentication
</aside>

### Schemas

<!-- backwards compatibility -->

```json
{
  "name": "string",
  "avatar": 0
}

```

#### AuthorCreate
{:.no_toc}

|Name|Type|Required|Restrictions|Description|
|---|---|---|---|---|
|name|string|true|none|none|
|avatar|any|false|none|none|

anyOf

|Name|Type|Required|Restrictions|Description|
|---|---|---|---|---|
|» *anonymous*|integer|false|none|none|

or

|Name|Type|Required|Restrictions|Description|
|---|---|---|---|---|
|» *anonymous*|null|false|none|none|

<!-- backwards compatibility -->

```json
{
  "token": "string",
  "id": 0
}

```

#### AuthorCreateResponse
{:.no_toc}

|Name|Type|Required|Restrictions|Description|
|---|---|---|---|---|
|token|string|true|none|none|
|id|integer|true|none|none|

<!-- backwards compatibility -->

```json
{
  "name": "string",
  "avatar": 0
}

```

#### AuthorEdit
{:.no_toc}

|Name|Type|Required|Restrictions|Description|
|---|---|---|---|---|
|name|any|false|none|none|

anyOf

|Name|Type|Required|Restrictions|Description|
|---|---|---|---|---|
|» *anonymous*|string|false|none|none|

or

|Name|Type|Required|Restrictions|Description|
|---|---|---|---|---|
|» *anonymous*|null|false|none|none|

continued

|Name|Type|Required|Restrictions|Description|
|---|---|---|---|---|
|avatar|any|false|none|none|

anyOf

|Name|Type|Required|Restrictions|Description|
|---|---|---|---|---|
|» *anonymous*|integer|false|none|none|

or

|Name|Type|Required|Restrictions|Description|
|---|---|---|---|---|
|» *anonymous*|null|false|none|none|

<!-- backwards compatibility -->

```json
{
  "id": 0,
  "name": "string",
  "avatar": {
    "id": 0,
    "filename": "string",
    "file_urlpath": "string",
    "color": "string"
  }
}

```

#### AuthorResponse
{:.no_toc}

|Name|Type|Required|Restrictions|Description|
|---|---|---|---|---|
|id|integer|true|none|none|
|name|string|true|none|none|
|avatar|any|true|none|none|

anyOf

or

<!-- backwards compatibility -->

```json
{
  "id": 0,
  "filename": "string",
  "file_urlpath": "string",
  "color": "string"
}

```

#### AvatarResponse
{:.no_toc}

|Name|Type|Required|Restrictions|Description|
|---|---|---|---|---|
|id|integer|true|none|none|
|filename|string|true|none|none|
|file_urlpath|string|true|none|none|
|color|string|true|none|none|

<!-- backwards compatibility -->

```json
{
  "file": "string",
  "post_id": 0,
  "language": "string"
}

```

#### Body_upload_file_files_upload_post
{:.no_toc}

|Name|Type|Required|Restrictions|Description|
|---|---|---|---|---|
|file|string(binary)|true|none|none|
|post_id|integer|true|none|none|
|language|string|true|none|none|

<!-- backwards compatibility -->

```json
"processing"

```

#### FileProcessingStatus
{:.no_toc}

|Name|Type|Required|Restrictions|Description|
|---|---|---|---|---|
|FileProcessingStatus|string|false|none|none|

###### Enumerated Values
{:.no_toc}

|Property|Value|
|---|---|
|FileProcessingStatus|processing|
|FileProcessingStatus|done|
|FileProcessingStatus|error|

<!-- backwards compatibility -->

```json
{
  "id": 0,
  "text": "string",
  "filename": "string",
  "content_type": "string",
  "file_hash": "string",
  "file_urlpath": "string",
  "processing_state": "processing"
}

```

#### FileResponse
{:.no_toc}

|Name|Type|Required|Restrictions|Description|
|---|---|---|---|---|
|id|integer|true|none|none|
|text|string|true|none|none|
|filename|string|true|none|none|
|content_type|string|true|none|none|
|file_hash|string|true|none|none|
|file_urlpath|string|true|none|none|

<!-- backwards compatibility -->

```json
{
  "detail": [
    {
      "loc": [
        "string"
      ],
      "msg": "string",
      "type": "string"
    }
  ]
}

```

#### HTTPValidationError
{:.no_toc}

|Name|Type|Required|Restrictions|Description|
|---|---|---|---|---|
|detail|[[ValidationError](#schemavalidationerror)]|false|none|none|

<!-- backwards compatibility -->

```json
{
  "posts": [
    {
      "id": 0,
      "title": "string",
      "text": "string",
      "created_at": "2019-08-24T14:15:22Z",
      "updated_at": "2019-08-24T14:15:22Z",
      "parent_id": 0,
      "author": {
        "id": 0,
        "name": "string",
        "avatar": {
          "id": 0,
          "filename": "string",
          "file_urlpath": "string",
          "color": "string"
        }
      },
      "files": [
        {
          "id": 0,
          "text": "string",
          "filename": "string",
          "content_type": "string",
          "file_hash": "string",
          "file_urlpath": "string",
          "processing_state": "processing"
        }
      ]
    }
  ],
  "has_more": true
}

```

#### PaginatedPostsResponse
{:.no_toc}

|Name|Type|Required|Restrictions|Description|
|---|---|---|---|---|
|posts|[[PostResponse](#schemapostresponse)]|true|none|none|

<!-- backwards compatibility -->

```json
{
  "title": "string",
  "text": "string",
  "parent_id": 0
}

```

#### PostCreate
{:.no_toc}

|Name|Type|Required|Restrictions|Description|
|---|---|---|---|---|
|title|string|true|none|none|
|text|string|true|none|none|
|parent_id|any|false|none|none|

anyOf

|Name|Type|Required|Restrictions|Description|
|---|---|---|---|---|
|» *anonymous*|integer|false|none|none|

or

|Name|Type|Required|Restrictions|Description|
|---|---|---|---|---|
|» *anonymous*|null|false|none|none|

<!-- backwards compatibility -->

```json
{
  "title": "string",
  "text": "string"
}

```

#### PostEdit
{:.no_toc}

|Name|Type|Required|Restrictions|Description|
|---|---|---|---|---|
|title|any|false|none|none|

anyOf

|Name|Type|Required|Restrictions|Description|
|---|---|---|---|---|
|» *anonymous*|string|false|none|none|

or

|Name|Type|Required|Restrictions|Description|
|---|---|---|---|---|
|» *anonymous*|null|false|none|none|

continued

|Name|Type|Required|Restrictions|Description|
|---|---|---|---|---|
|text|any|false|none|none|

anyOf

|Name|Type|Required|Restrictions|Description|
|---|---|---|---|---|
|» *anonymous*|string|false|none|none|

or

|Name|Type|Required|Restrictions|Description|
|---|---|---|---|---|
|» *anonymous*|null|false|none|none|

<!-- backwards compatibility -->

```json
{
  "id": 0,
  "title": "string",
  "text": "string",
  "created_at": "2019-08-24T14:15:22Z",
  "updated_at": "2019-08-24T14:15:22Z",
  "parent_id": 0,
  "author": {
    "id": 0,
    "name": "string",
    "avatar": {
      "id": 0,
      "filename": "string",
      "file_urlpath": "string",
      "color": "string"
    }
  },
  "files": [
    {
      "id": 0,
      "text": "string",
      "filename": "string",
      "content_type": "string",
      "file_hash": "string",
      "file_urlpath": "string",
      "processing_state": "processing"
    }
  ]
}

```

#### PostResponse
{:.no_toc}

|Name|Type|Required|Restrictions|Description|
|---|---|---|---|---|
|id|integer|true|none|none|
|title|string|true|none|none|
|text|string|true|none|none|
|created_at|string(date-time)|true|none|none|
|updated_at|string(date-time)|true|none|none|
|parent_id|any|true|none|none|

anyOf

|Name|Type|Required|Restrictions|Description|
|---|---|---|---|---|
|» *anonymous*|integer|false|none|none|

or

|Name|Type|Required|Restrictions|Description|
|---|---|---|---|---|
|» *anonymous*|null|false|none|none|

continued

<!-- backwards compatibility -->

```json
{
  "id": 0,
  "title": "string",
  "text": "string",
  "created_at": "2019-08-24T14:15:22Z",
  "updated_at": "2019-08-24T14:15:22Z",
  "author": {
    "id": 0,
    "name": "string",
    "avatar": {
      "id": 0,
      "filename": "string",
      "file_urlpath": "string",
      "color": "string"
    }
  },
  "files": [
    {
      "id": 0,
      "text": "string",
      "filename": "string",
      "content_type": "string",
      "file_hash": "string",
      "file_urlpath": "string",
      "processing_state": "processing"
    }
  ],
  "children": [
    {
      "id": 0,
      "title": "string",
      "text": "string",
      "created_at": "2019-08-24T14:15:22Z",
      "updated_at": "2019-08-24T14:15:22Z",
      "parent_id": 0,
      "author": {
        "id": 0,
        "name": "string",
        "avatar": {
          "id": 0,
          "filename": "string",
          "file_urlpath": "string",
          "color": "string"
        }
      },
      "files": [
        {
          "id": 0,
          "text": "string",
          "filename": "string",
          "content_type": "string",
          "file_hash": "string",
          "file_urlpath": "string",
          "processing_state": "processing"
        }
      ]
    }
  ]
}

```

#### ThreadResponse
{:.no_toc}

|Name|Type|Required|Restrictions|Description|
|---|---|---|---|---|
|id|integer|true|none|none|
|title|string|true|none|none|
|text|string|true|none|none|
|created_at|string(date-time)|true|none|none|
|updated_at|string(date-time)|true|none|none|

<!-- backwards compatibility -->

```json
{
  "loc": [
    "string"
  ],
  "msg": "string",
  "type": "string"
}

```

#### ValidationError
{:.no_toc}

|Name|Type|Required|Restrictions|Description|
|---|---|---|---|---|
|loc|[anyOf]|true|none|none|

anyOf

|Name|Type|Required|Restrictions|Description|
|---|---|---|---|---|
|» *anonymous*|string|false|none|none|

or

|Name|Type|Required|Restrictions|Description|
|---|---|---|---|---|
|» *anonymous*|integer|false|none|none|

continued

|Name|Type|Required|Restrictions|Description|
|---|---|---|---|---|
|msg|string|true|none|none|
|type|string|true|none|none|

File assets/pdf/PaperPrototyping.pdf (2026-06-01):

Tâche 1
Nous voulons développer un réseau d‘échange auquel vous pouvez accéder avec votre téléphone portable. Réfléchissez à l‘utilisation que vous voulez faire avec le réseau d‘échange. Quels sont vos souhaits pour cela ? Collez jusqu‘à 5 autocollants ici.
S‘il n‘y a rien d‘approprié, prenez des crayons de couleur et dessinez-le.

BONJOUR!
Bienvenue à notre atelier dans le cadre du projet Minodu.
L’objectif du projet Minodu est de concevoir avec vous des moyens de restaurer la santé du sol, de vous prémunir contre les pluies abondantes ou absentes et de protéger vos plantes contre les ravageurs.
Ce sont vous qui avez le plus de connaissances et d’expérience. Vous vivez sur votre sol et, comme vous êtes un producteur, vous y travaillez le plus. L’atelier prendra environ une heure et se composera de 4 tâches.


l’équipe de projet Minodu

Tâche 4
Choisis jusqu’à trois icônes qui te semblent correspondre à l’ambiance acoustique. Entoure-les avec un crayon. Si tu penses à une icône appropriée, dessine-la dans la case vide.

AMBIANCE ACOUSTIC 3

Tâche 3
Prends 2 minutes pour illustrer l‘ambiance acoustique. Tu es complètement libre comment le dessiner. Utilise les marqueurs et dessine ce qui te vient à l‘esprit.

AMBIANCE ACOUSTIC 3

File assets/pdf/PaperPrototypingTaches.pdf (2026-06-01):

BONJOUR!

Bienvenue à notre atelier dans le cadre du projet Minodu.

L’objectif du projet Minodu est de concevoir avec vous des moyens de restaurer la santé du sol, de vous prémunir contre les pluies abondantes ou absentes et de protéger vos plantes contre les ravageurs.

Ce sont vous qui avez le plus de connaissances et d’expérience. Vous vivez sur votre sol et, comme vous êtes un producteur, vous y travaillez le plus.

L’atelier prendra environ une heure et se composera de 4 tâches.

Nous voulons développer un réseau d‘échange auquel vous pouvez accéder avec un portable andoid ou avec un autre écran.
Vous y trouverez des informations et des applications qui peuvent vous aider en votre qualité de producteur dans la culture de vos plantes, animaux et peut par exemple vous donner des connaissances sur comment se préparer à une sécheresse ou une pluie extrême.

Nous avons préparé à cet effet une feuille de stickers avec des thèmes qui pourraient vous intéresser.
Vous pouvez utiliser ces stickers pour nous montrer ce dont vous avez réellement besoin en termes d’informations et d’applications. Vous pouvez également dessiner quelque chose qui manque avec les crayons.

Merci beaucoup
l’équipe de projet Minodu

Processus

1. Preparataion (10 min)
Préparez les tâches, les stickers et les crayons. Accueillez les participants, expliquez l'atelier et demandez s'il y a des questions à ce sujet !
2. Mise en œuvre
Préparez les tâches, les stickers et les crayons. Accueillez les participants, expliquez l'atelier et demandez s'il y a des questions à ce sujet !
3. Documentation et évaluation
Après que tous les prototypes ont été réalisés, veuillez noter la signification de chaque symbole pour les participants. Vous pouvez également enregistrer de courts audios avec les personnes. Que voulaient-ils exprimer ?
Documentez bien ces déclarations, s'il vous plaît !

La méthode
Le prototypage sur papier est une activité essentielle dans les processus de conception. Vous représentez des captures d'écran pour aider à déterminer comment votre conception/produit devrait apparaître. Le prototypage sur papier est un moyen simple d'aider à façonner des concepts. Cette méthode est utile lors des séances de remue-méninges, au cours desquelles votre équipe cherche la meilleure façon de résoudre les problèmes des utilisateurs.

## Réseau d’échange

Réfléchissez à l‘utilisation que vous voulez faire avec le réseau d‘échange.
Que voulez-vous voir à l‘écran, de quoi avez-vous besoin ?
Quels sont vos souhaits pour cela ?

Collez jusqu‘à 5 autocollants sur le smartphone android.

S‘il n‘y a rien d‘approprié, prenez des crayons de couleur et dessinez-le.

Documentation


## Que fait le temps ? Va-t-il pleuvoir demain ?

Quel temps fait-il aujourd'hui ? Quel temps fera-t-il demain ? Quand la pluie va-t-elle tomber ? Une période de sécheresse nous attend-elle ? Comment souhaitez-vous voir ces informations ?

Choisissez à nouveau jusqu'à 5 stickers et collez-les sur l'écran !

S'il n'y a rien d'approprié, choisissez les crayons et dessinez quelque chose, s'il vous plaît !

Documentation

## Ce sur quoi je veux en savoir plus

Lorsque les saisons sèches et les saisons des pluies changent, certains défis se présentent à nous. Il peut s'agir de savoir comment lutter contre les ravageurs, comment conserver l'eau ou encore quelles plantes sont plus résistantes.

Quels sont les sujets qui vous intéressent ?

Choisissez à nouveau jusqu'à 5 stickers et collez-les sur l'écran !

S'il n'y a rien d'approprié, choisissez les crayons et dessinez quelque chose, s'il vous plaît !

Documentation

## Mon application désirée sur mon téléphone Android

Il a maintenant beaucoup été question de pluie, de sécheresse et de votre activité comme producteur. En plus de ces thèmes ou en extension de ces thèmes, quelle autre application ou information aimeriez-vous avoir sur un portable Android ou un écran ?

Choisissez à nouveau jusqu'à 5 stickers et collez-les sur l'écran !

S'il n'y a rien d'approprié, choisissez les crayons et dessinez quelque chose, s'il vous plaît !

Documentation

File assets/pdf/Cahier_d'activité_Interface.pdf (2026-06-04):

# Cahier d’activité Interface et Contenu du


# Réseau Local

## BONJOUR ET BIENVENUE!

Ce cahier vous guide pour tester un réseau local.
Ce réseau fonctionne sans Internet.
Il vous donne accès à des conseils agricoles, à la météo, à un forum, et à d’autres informations utiles pour votre village.

Ce réseau est encore en test.
Nous voulons savoir :
Est-ce que cela fonctionne bien pour vous ?
Est-ce que c’est facile à comprendre ? Est-ce que c’est utile ?

Votre avis est très important
C’est vous qui allez utiliser ce réseau.
Votre avis nous aide à le rendre plus simple,
plus clair, et plus utile.

Merci de nous dire ce que vous pensez.
Ensemble, nous pouvons améliorer ce réseau pour qu’il réponde vraiment à vos besoins.

Bonne découverte, et merci pour votre participation !

l’équipe de projet Minodu

Les données recueillies dans le cadre de cette étude sont rédigées de manière anonyme. Nous vous demandons de nous donner votre accord pour le traitement de vos données dans le cadre de notre recherche .

Signature

## QUI ÊTES-VOUS?

Age

Genre

Village/ ville

Années à l‘école

Avez-vous un smartphone ?

Avez-vous un ordinateur ?

18-24 | 25-34 | 35-44 | 45-54 | 55-64 | 64+
| femme | | homme | divers
0 | 1-5 | 6-10 | 11+
| | oui | non
| | oui | non

## Contenue

Réseau local | p. 6
Essayez | p. 7
Icônes et symboles | p. 10
Types de conseils | p. 11
Symboles et kabiyè | p. 12
Météo | p.13
Approch Baobab

## RÉSEAU LOCAL

Le réseau local est divisé en différents domaines et applications. Nous voulons voir si cette division est pertinente et facile à utiliser. Nous avons créé deux approches dont nous aimerions recevoir vos impressions. Sur la base de vos retours, nous aimerions les développer davantage.

Le projet Minodu vise à créer des réseaux communautaires locaux et évolutifs pour une gestion durable des terres dans les communautés rurales grâce aux supports et applications numériques. Il s’agit ainsi de réduire l’écart entre les résultats scientifiques disponibles et les solutions concrètes adoptées au niveau communautaire pour une gestion durable des terres.


## Essayez

### Tâche 1

Trouvez le conseil sur la méthode Zaï.
Que devez-vous faire pour l’écouter en kabiyè ?

### Tâche 2

Choisissez un conseil et écoutez-le. Comment faire pour mieux visualiser le contenu ? Comment faire pour que le contenu soit plus clair ?
Esquissez une approche!
Conseil choisi:

### Évaluation

Comment vous trouvez l’application ?
Faites une croix ou un point sur la ligne. Voici un exemple.
intuitive | encrombant
clair | chaotique

mini-
maliste | surchargé
simple | compliqué
beau | moche
élégant | sans style
pratique | impracticable
utile | irritant
bien | mauvais

Maintenant, c’est à vous !

### Notes

Que pensez-vous d’autre de l‘application ?

### Questions

Serait-il utile d’avoir des audios qui expliquent l’application ?

Les écrits devraient-ils être aussi audibles ?

oui | non
oui | non

## ICONES ET SYMBOLES

Kabiyè: FR: Conseil; Kabiyè: FR: Météo; Kabiyè: FR: Marché; Kabiyè: FR: Forum; Kabiyè: FR:

Voici des icônes pour l’application.
Entourez celle qui vous semble la meilleure.
Ou dessinez un symbole que vous préférez.

Manquez-vous de points de menu pour utiliser le réseau local ?
Dessinez-les ici et écrivez leur nom en français ou en Kabiyè.

## TYPES DE CONSEILS

Voici des images.
Écrivez un mot en français ou en kabiyè pour chaque catégorie. Ajoutez aussi vos idées !


Kabiyè:

FR:


Kabiyè:

FR:


Kabiyè:

FR:


Kabiyè:

FR:


Kabiyè:

FR:

Kabiyè:

FR:

## SYMBOLES ET KABIYÈ

Y a-t-il un symbole ou un signe qui symbolise pour vous le kabiyè ?

Y a-t-il d’autres symboles qui vous viennent à l’esprit dans le contexte du réseau local et de la culture kabiyè ?
Merci de les partager avec nous et de les décrire en un ou deux mots.

## MÉTÉO

La météo joue un rôle important pour l’agriculture. Dessinez comment vous voulez les prévisions météo sur votre écran !

## APPROCH BAOBAB

Imaginez un écran avec des applis autour d’un baobab. Mettez-les autour de l’arbre.


Merci beaucoup !
Votre retour est très précieux pour améliorer votre réseau local.

FKZ 01LL2202A

Minodu: Cahier d‘activité - Interface et Contenu du Réseau Local (v1)
© 2026 by Friederike Fröbel (editor),
is licensed under CC BY-NC-SA 4.0.
To view a copy of this license, visit
https://creativecommons.org/licenses/by-nc-sa/4.0/
Contact: friederike.froebel@dfki.de

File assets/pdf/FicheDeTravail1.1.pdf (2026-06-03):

Impressions du Réseau Local

# Qui êtes-vous ? Cho si si sez un au ot oc

er présente !

Communauté | Groupe

↑ Dans quelle section aimeriez-vous passer plus de temps? ↑

↑ Quelle section vous semble compliquée ?

↑

↑ Qu'est-ce que vous souhaiteriez trouver d'autre dans l'application ? ↑

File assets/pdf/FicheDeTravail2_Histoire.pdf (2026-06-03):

L'histoire du Réseau Local

Un frère ou une sœur vient vous voir et voit le réseau local dans votre village. Il ou elle vous demande :
« Qu'est-ce que c'est ? À quoi ça sert ?

Quel histoire allez-vous lui raconter ?
Choisissez des autocollants et des crayons pour illustrer l'histoire.
Communauté | Groupe

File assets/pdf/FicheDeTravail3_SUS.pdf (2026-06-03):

Impressions du Réseau Local

L‘affirmation | Votre avis

01 J'ai envie d'utiliser ce système souvent.

02 Ce système est trop compliqué pour rien.

03 Ce système est facile à utiliser.

04 J’ai besoin que quelqu’un m’aide pour utiliser ce système

05 C’est un bon système, tout marche bien ensemble.

06 Rien me paraît clair quand j’utilise ce système

07 Les gens vont vite apprendre comment utiliser ce système.

08 Ce système est vraiment dur à utiliser.

09 Quand j’utilise ce système, je me sens très en confiance et à l'aise.

10 Avant de pouvoir l'utiliser, je dois apprendre beaucoup de choses.

Communauté | Groupe

Vous trouverez ci-dessous quelques affirmations concernant le système, le réseau local que vous avez essayé. Veuillez indiquer votre avis à l'aide des autocollants correspondants.

Oui,
tout à fait

Oui,
assez

Comme ci,
comme ça | Pas trop | Non,
| | pas du tout

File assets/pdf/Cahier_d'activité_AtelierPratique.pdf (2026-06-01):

# ATELIER PRATIQUE Cahier d’activité

FKZ 01LL2202A

27 et 28 juillet 2023 entre 10h et 16h à l’Université de Kara

Cahier d’activité: Atelier pratique © 2025 by Friederike Fröbel (editor)
is licensed under CC BY-NC-SA 4.0.
To view a copy of this license, visit https://creativecommons.org/licenses/by-nc-

3

## BONJOUR!

Ce cahier vous guide durant l‘atelier pratique.

Vous trouverez une brève description de chaque station, des questions à répondre et de l‘espace pour prendre des notes.

Il faut passer toutes les stations de l‘atelier pratique, documenté par des signatures, pour pouvoir recevoir un certificat de participation et pour pouvoir postuler pour devenir membre de notre équipe.

Vous pouvez garder ce cahier après l‘atelier et nous aimerions en prendre des photos comme documentation.

Nous vous souhaitons un bon atelier et des belles découvertes !

l’équipe de projet Minodu
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

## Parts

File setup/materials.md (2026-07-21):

---
layout: page
title: Bill of Materials
---

This document provides an overview of the hardware components and approximate costs for different configurations of the Local Community Network (LCN), based on actual project implementation.

## Core Setup 
This setup includes no solar power and no wind sensors.

| Component | Price (€) | Price (FCFA) | Shop / Link |
|---|---|---|---|
| Raspberry Pi 5 (incl. SD) | 184.90 | ~83,900 | https://www.rasppishop.de/Raspberry-Pi-5-mit-8-GB-RAM |
| Cooling (fan) | 5.55 | ~4,100 | https://www.reichelt.de/de/de/shop/produkt/raspberry_pi_-_luefter_fuer_raspberry_pi_5-360116 |
| Wi-Fi Adapter / Antenna | 19.95 | ~13,100 | https://www.reichelt.de/de/de/shop/produkt/wlan-adapter_usb_1300_mbit_s-279758 |
| RTC Battery | 4.8 | ~3,100 | https://www.reichelt.de/de/de/shop/produkt/raspberry_pi_-_rtc_batterie_fuer_raspberry_pi_5-360117 |
| USB-C Cable (90°) | 4.0 | ~2,600 | https://www.amazon.de/Rechtwinklige-Stecker-Stromkabel-installiert-Reparatur/dp/B0D8PBBHS6 |
| teleAgriCulture Board | ~30.00 | ~65,600 | https://teleagriculture.org/ |
| Display (1.8” TFT) | 4.95 | ~3,200 | https://www.ebay.de/itm/389456784599 |
| BME280 Sensor | 19.94 | ~13,100 | https://eckstein-shop.de/Adafruit-BME280-I2C-or-SPI-Temperature-Humidity-Pressure-Sensor |
| Multigas Sensor V2 | 27.3 | ~17,900 | https://www.reichelt.de/de/de/shop/produkt/arduino_-_gassensor_v2_mehrkanal-328573 |
| DHT22 Sensor | 11.89 | ~6,200 | https://eckstein-shop.de/WaveShare-DHT22-Temperature-Humidity-Sensor-for-Raspberry-Pi-Arduino |
| 3D Filament (Enclosure) | ~17 | ~11,200 | https://www.reichelt.de/de/de/shop/produkt/filament_abs_natural_weiss_1_75_mm_750_g-420023 |
| Mounting hardware | ~25 | ~16,400 | — |

**Estimated Cost:** ~350–380 € / ~230,000 – 250,000 FCFA  
*Prices in FCFA are approximate (1 € ≈ 655 FCFA). Local sourcing may differ.*

## Solar Power Add-on
This setup enables off-grid operation of the Local Community Network using solar energy.

| Component | Price (€) | Price (FCFA) | Shop / Link |
|---|---|---|---|
| Solar Panel (30W, 18V) | ~6.15 | ~4,030 | — |
| Battery (12V 24Ah) | ~46.15 | ~30,200 | — |
| Charge Controller (PWM) | ~12.31 | ~8,060 | — |
| Voltage Regulator (12V → 5V)  | 14.99 | ~9,820 | https://www.amazon.de/Zorblix-Spannungs-wandler-spannungsregler-einstellbar-Spannungs-stabilisator/dp/B0FNWMCZKM |
| Solar Cables | ~12.31 | ~8,060 | — |
| Mounting / installation | ~20 | ~13,100 | — |

**Estimated Add-on Cost:** ~110–120 € / ~73,000 – 80,000 FCFA  
*Prices in FCFA are approximate (1 € ≈ 655 FCFA). Local sourcing may differ.*

## Wind Measurement Add-on
This setup adds wind sensing capabilities to the Local Community Network, enabling the measurement of wind speed and direction as part of environmental monitoring

| Component | Price (€) | Price (FCFA) | Shop / Link |
|---|---|---|---|
| Wind Direction & Speed Kit | 105.50 | ~69,100 | https://botland.de/wetterstationen/16258-wetterstation-mit-windrichtungs-und-geschwindigkeitsmessung-sparkfun-sen-15901-845156010141.html |
| Additional connectors | ~5 | ~3,300 | — 

**Estimated Add-on Cost:** ~110 € / ~72,000 FCFA  
*Prices in FCFA are approximate (1 € ≈ 655 FCFA). Local sourcing may differ.*

## Lightweight Setup (Raspberry Pi 4 – No LLM)
This setup uses a Raspberry Pi 4 and does not support local LLM functionality. It is designed for reduced cost, lower power consumption, and more lightweight deployments.

| Component | Price (€) | Price (FCFA) | Shop / Link |
|---|---|---|---|
| Raspberry Pi 4 (2GB) | 57.90 | ~37,900 | https://www.rasppishop.de/Raspberry-Pi-4-Modell-B-2GB-SDRAM |
| SD Card (32 GB) | 6.14 | ~4,020 | https://www.rasppishop.de/Sandisk-32-GB-Noobs |
| Cooling (fan) | 9.99 | ~6,550 | https://www.reichelt.de/de/de/shop/produkt/raspberry_pi_-_luefter_fuer_compute_module_4-364272 |
| Power Supply | 12.00 | ~7,860 | https://www.reichelt.de/de/de/shop/produkt/raspberry_pi_netzteil_usb_c_27w_weiss-360118 |
| Wi-Fi Adapter / Antenna | 19.95 | ~13,070 | https://www.reichelt.de/de/de/shop/produkt/wlan-adapter_usb_1300_mbit_s-279758 |
| RTC Battery | 4.80 | ~3,140 | https://www.reichelt.de/de/de/shop/produkt/raspberry_pi_-_rtc_batterie_fuer_raspberry_pi_5-360117 |
| teleAgriCulture Board | 30.00 | ~19,650 | https://teleagriculture.org/ |
| Display (1.8” TFT) | 4.95 | ~3,250 | https://www.ebay.de/itm/389456784599 |
| BME280 Sensor | 19.94 | ~13,060 | https://eckstein-shop.de/Adafruit-BME280-I2C-or-SPI-Temperature-Humidity-Pressure-Sensor |
| Multigas Sensor V2 | 27.30 | ~17,880 | https://www.reichelt.de/de/de/shop/produkt/arduino_-_gassensor_v2_mehrkanal-328573 |
| DHT22 Sensor | 11.89 | ~7,780 | https://eckstein-shop.de/WaveShare-DHT22-Temperature-Humidity-Sensor-for-Raspberry-Pi-Arduino |
| 3D Filament (ABS) | ~17.00 | ~11,130 | https://www.reichelt.de/de/de/shop/produkt/filament_abs_natural_weiss_1_75_mm_750_g-420023 |
| Mounting hardware | ~25.00 | ~16,380 | — |

**Estimated Cost:** ~247 € / ~162,000 FCFA  
*Prices in FCFA are approximate (1 € ≈ 655 FCFA). Local sourcing may differ.*

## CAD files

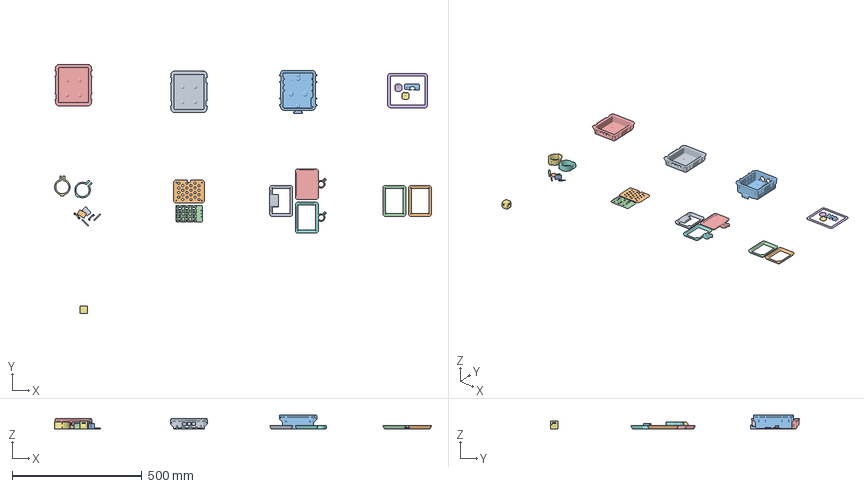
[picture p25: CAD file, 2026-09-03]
assets/3dFiles/Minodu_Box.3mf
1451.3 x 959.4 x 52.5 mm
Top_x01-MultiColor.stl_1
StevensonScreen_RC01_Midlle_X06.stl x 2
0B_Parametric_Box_AxialFan_AirFlowVent.stl_174
StevensonScreen_RC01_Top.stl
0B_Parametric_Box_AxialFan_AirFlowVent.stl_190
0B_Parametric_Box_AxialFan_AirFlowVent.stl_194
StevensonScreen_RC01_Base.stl
StevensonScreen_RC01_Midlle_SensorPlate_Holder.stl
StevensonScreen_RC01_Botom.stl
Base_x01.stl
StevensonScreen_RC01_Sensor_Plate.stl
Top_x01-MultiColor.stl
0B_Parametric_Box_AxialFan_AirFlowVent.stl_23
0B_Parametric_Box_AxialFan_AirFlowVent.stl_196
0B_Parametric_Box_AxialFan_AirFlowVent.stl_195
0B_Parametric_Box_AxialFan_AirFlowVent.stl_193
0B_Parametric_Box_AxialFan_AirFlowVent.stl_26
0B_Parametric_Box_AxialFan_AirFlowVent.stl_25
0B_Parametric_Box_AxialFan_AirFlowVent.stl_192
0B_Parametric_Box_AxialFan_AirFlowVent.stl_24
0B_Parametric_Box_AxialFan_AirFlowVent.stl_191
CALI HEX CUBE-ESUN.stl

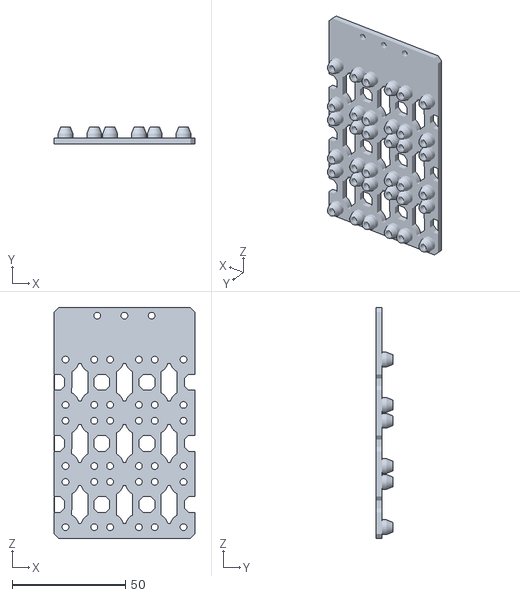
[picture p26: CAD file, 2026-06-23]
assets/3dFiles/StevensonScreen_RC01_Sensor_Plate.stl
62.1 x 7.60 x 102.0

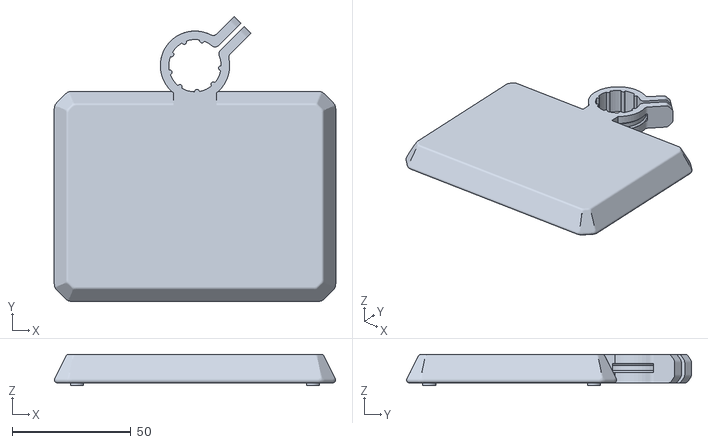
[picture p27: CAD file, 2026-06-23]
assets/3dFiles/StevensonScreen_RC01_Top.stl
118.5 x 119.9 x 13.2

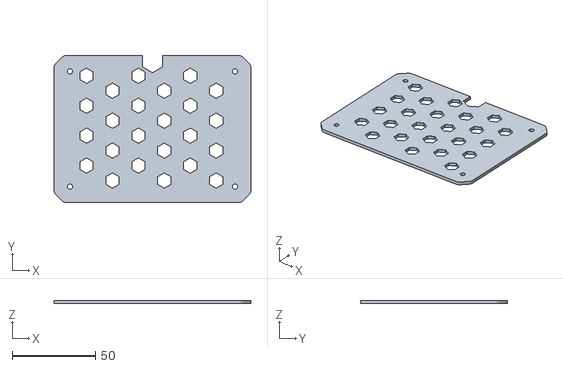
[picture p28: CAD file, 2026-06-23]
assets/3dFiles/StevensonScreen_RC01_Botom.stl
118.5 x 88.5 x 2.00

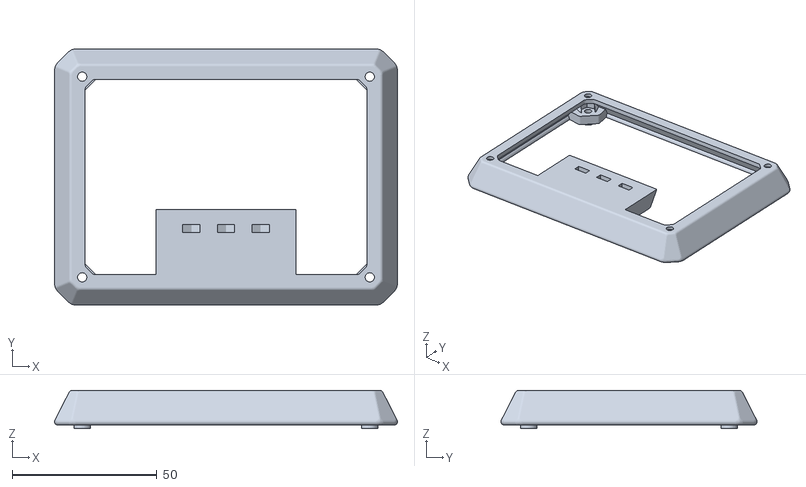
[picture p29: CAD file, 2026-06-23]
assets/3dFiles/StevensonScreen_RC01_Midlle_SensorPlate_Holder.stl
118.5 x 88.5 x 13.2

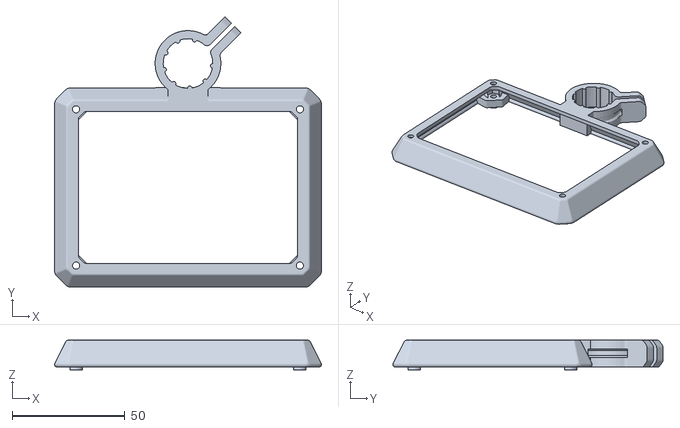
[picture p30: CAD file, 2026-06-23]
assets/3dFiles/StevensonScreen_RC01_Base.stl
118.5 x 119.9 x 13.2

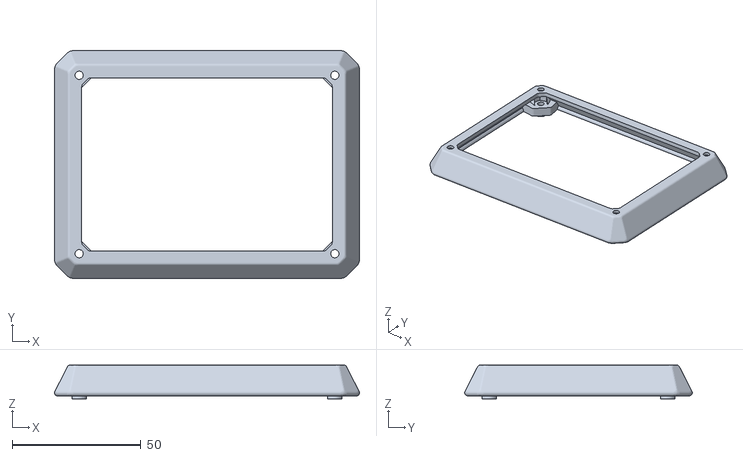
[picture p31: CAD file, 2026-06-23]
assets/3dFiles/StevensonScreen_RC01_Midlle_X06.stl
118.5 x 88.5 x 13.2

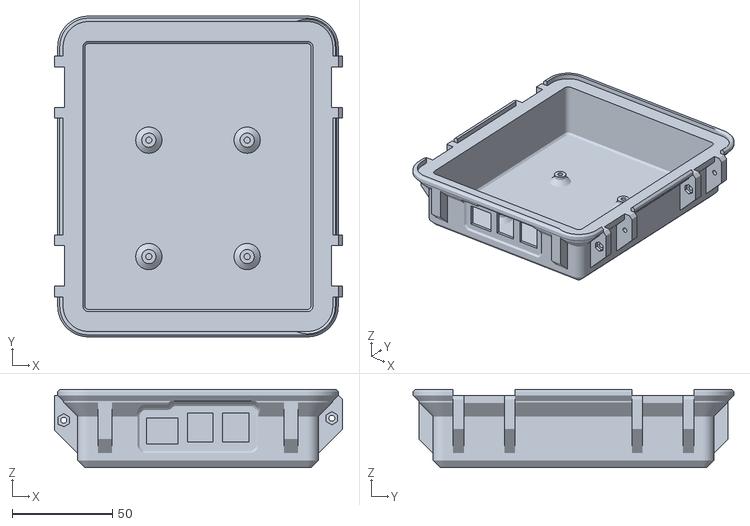
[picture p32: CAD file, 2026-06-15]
assets/3dFiles/Top_x01-MultiColor.stl
143.5 x 159.8 x 39.0

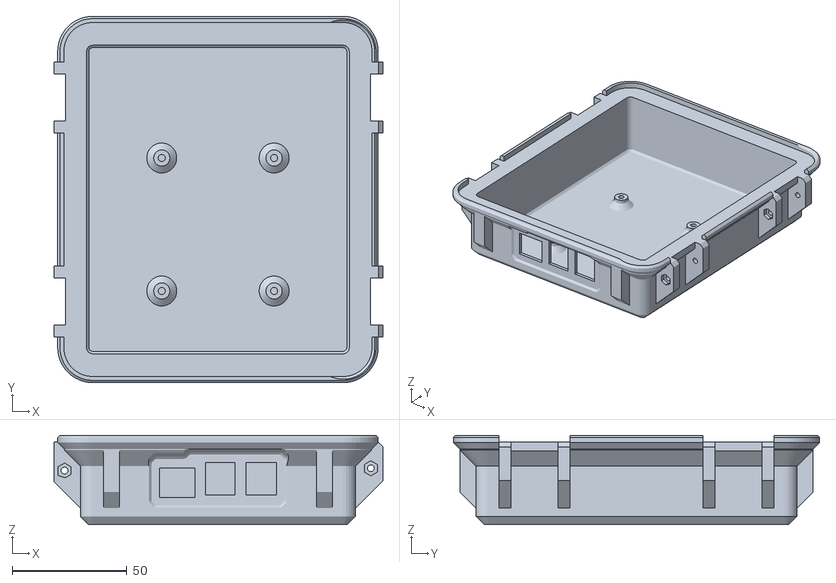
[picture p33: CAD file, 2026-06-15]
assets/3dFiles/Top_x01.stl
143.5 x 159.8 x 39.0

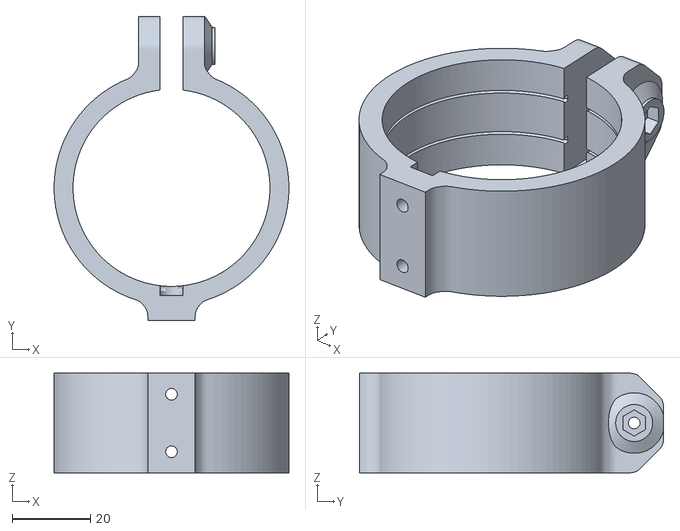
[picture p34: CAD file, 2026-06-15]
assets/3dFiles/50mm_Pole_Fixation.stl
60.1 x 77.8 x 25.5

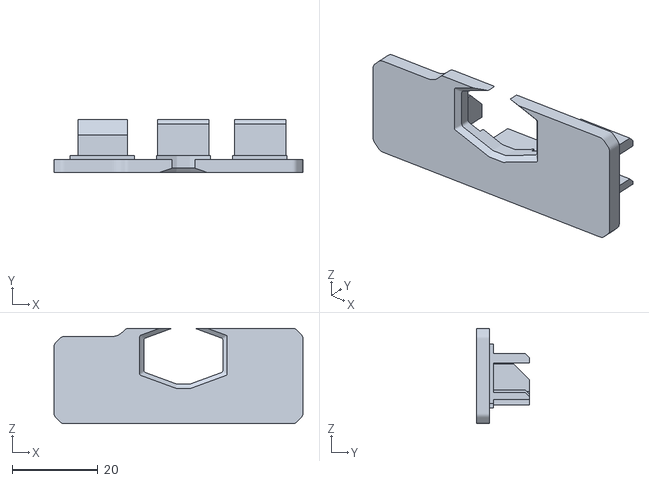
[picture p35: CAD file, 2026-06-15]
assets/3dFiles/TPU_RPi5PortDustCaps_x01.stl
58.0 x 12.3 x 22.2

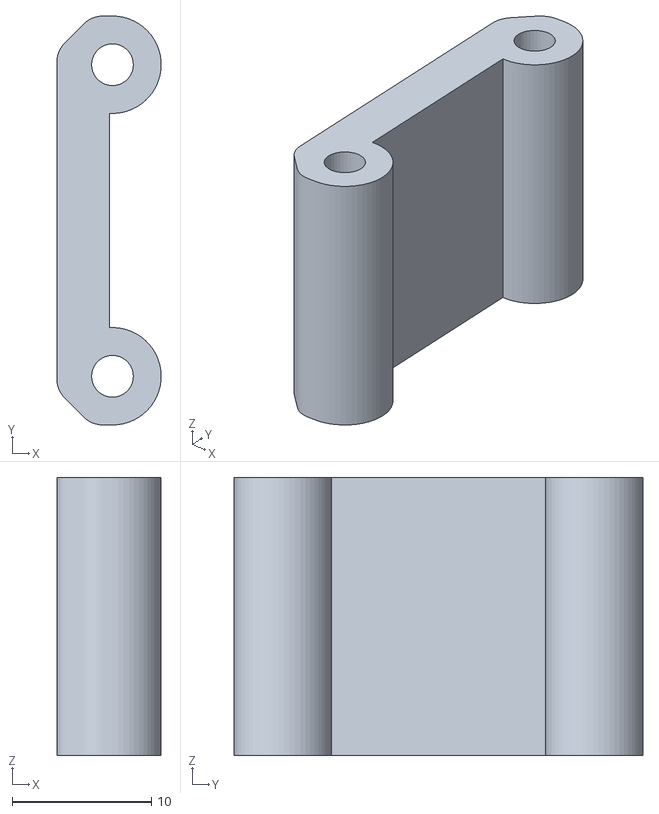
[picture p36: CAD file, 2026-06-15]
assets/3dFiles/Hinge_x02.stl
7.50 x 29.4 x 20.0

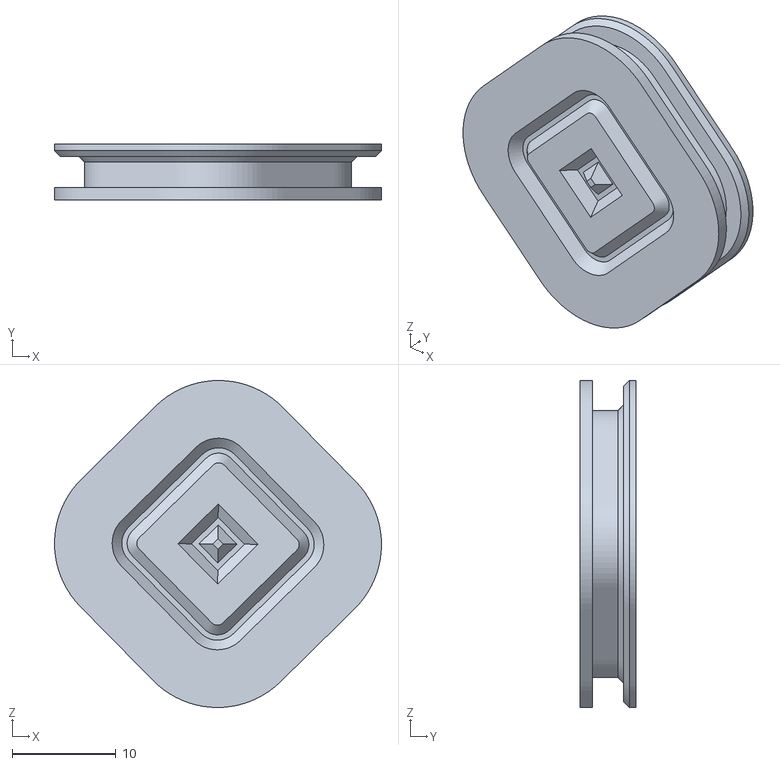
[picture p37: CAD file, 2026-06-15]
assets/3dFiles/TPU_CableOutletCap_x02.stl
31.5 x 5.40 x 31.5

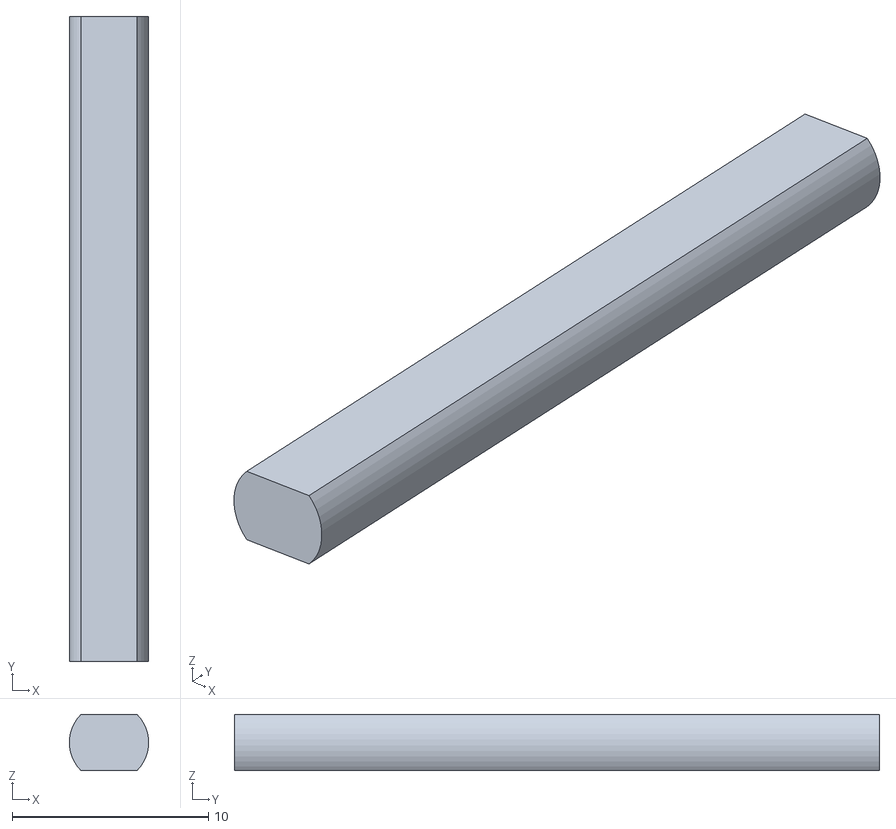
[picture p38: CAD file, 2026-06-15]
assets/3dFiles/Clip_x02.stl
4.04 x 32.9 x 2.86

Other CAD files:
assets/3dFiles/Latch_x02.stl
assets/3dFiles/Base_x01.stl

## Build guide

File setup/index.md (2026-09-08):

---
layout: page
title: Setup
heading_title: Setup Guide
---
 
Welcome to the **Local Community Network (LCN)** setup guide. A step-by-step reference for assembling and configuring a Raspberry Pi–based local network weather station with the DIY Teleagriculture board. Follow the sections below in order for a smooth setup experience.

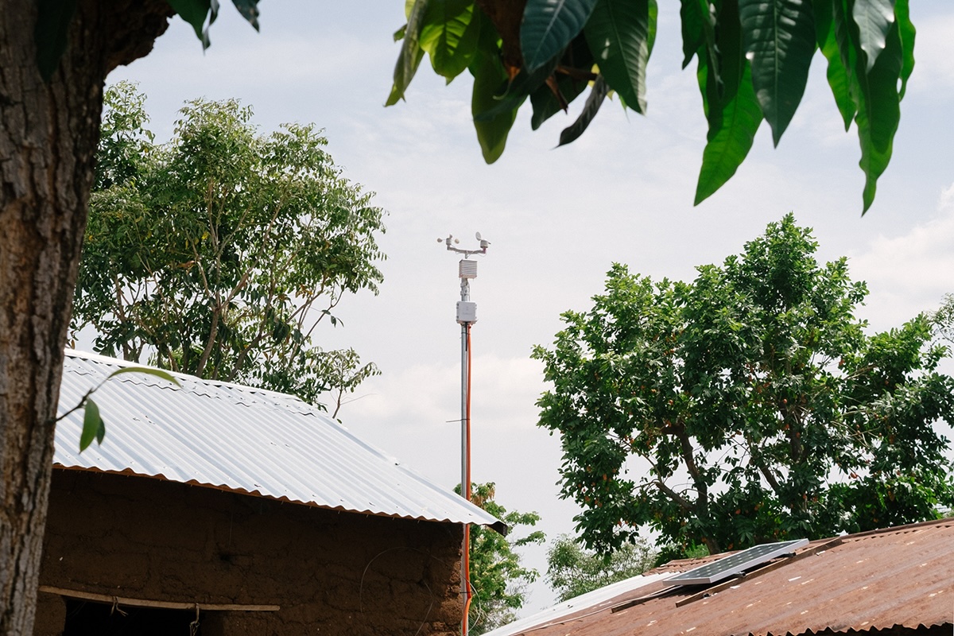
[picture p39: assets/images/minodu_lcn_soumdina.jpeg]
lcn_soumdina

 
## What You'll Be Building
 
**The Minodu Local Community Network (LCN)** is a self-hosted, hardware weather station that runs entirely offline and offgrid and spans a local WI-FI network. It combines a Raspberry Pi with the Teleagriculture DIY sensor board to collect, process, and serve real-time environmental data.
 
## Setup Sections
 
### Material List
This section lists all required hardware components, tools, and optional accessories, including the Raspberry Pi model, sensors, cables, and power supply.

*[→ Go to material list](./materials)*

### Hardware Assembly 
Step-by-step instructions for physically assembling the weather station. Covers mounting the Teleagriculture board, connecting sensors, and wiring the components together safely.

*[→ Go to hardware assembly](./hardware)*

### Raspberry Pi Installation 
How to flash the OS, configure networking, enable SSH, and prepare your Raspberry Pi to run the Local Community Network (LCN) software stack.

*[→ Go to Raspberry Pi Installation](./pi)*

### Teleagriculture Installation
Software setup for the Teleagriculture DIY weather kit. Covers driver installation, sensor calibration, and verifying that readings are coming through correctly.
 
*[→ Go to Teleagriculture Installation](./teleagriculture)*

## Help
**Need help?** Open an issue on the [Minodu issue tracker](https://github.com/MinoduLCN/minodu/issues) or make a post on our [Discussion Board](https://github.com/MinoduLCN/minodu/discussions).

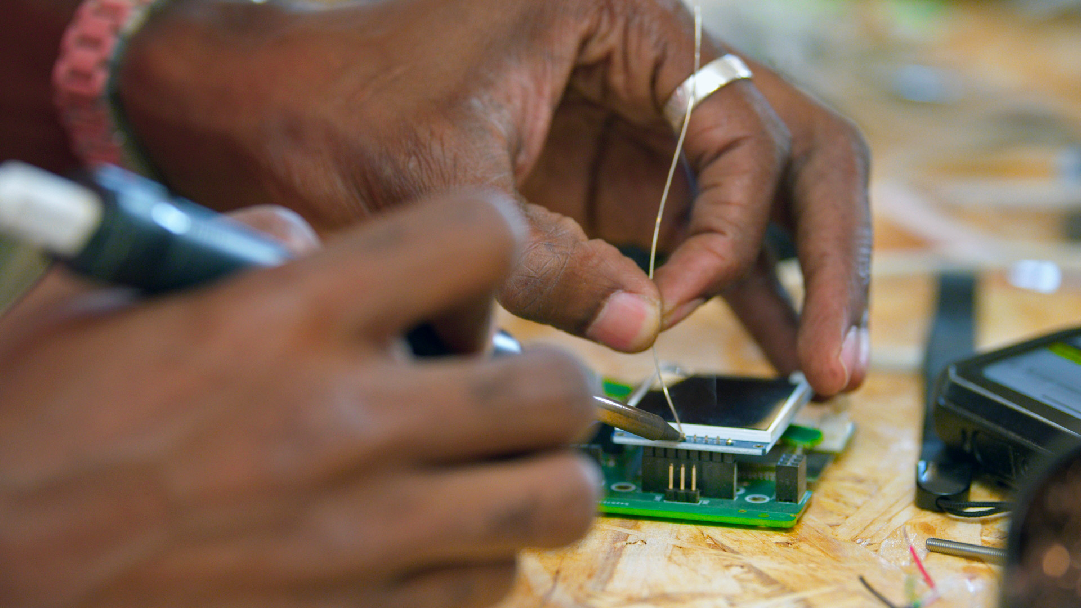
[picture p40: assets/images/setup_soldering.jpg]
soldering


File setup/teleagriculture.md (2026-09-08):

---
layout: page
title: Teleagriculture Setup
---

The Teleagriculture board is a weather station that reads out the current sensor data and sends it to the Minodu server. The Minodu server saves and analyzes the weather data. This page guides you on how to set up your Teleagriculture board and connect it to the Minodu system.

This guide explains how to setup the board for integrating it into the Minodu System

*Teleagriculture is an Open Source Project. You can find more information about it here:* [https://github.com/TeleAgriCulture/main](https://github.com/TeleAgriCulture/main)

## Board Assembly

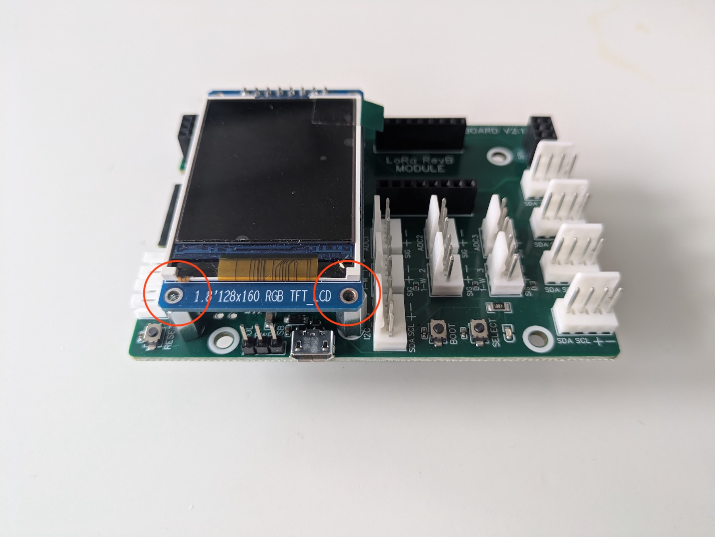
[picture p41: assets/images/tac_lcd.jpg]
| **Step 1:** Install the lcd module by pluging it into the pin header on the board and securing it with 2 screws |  |
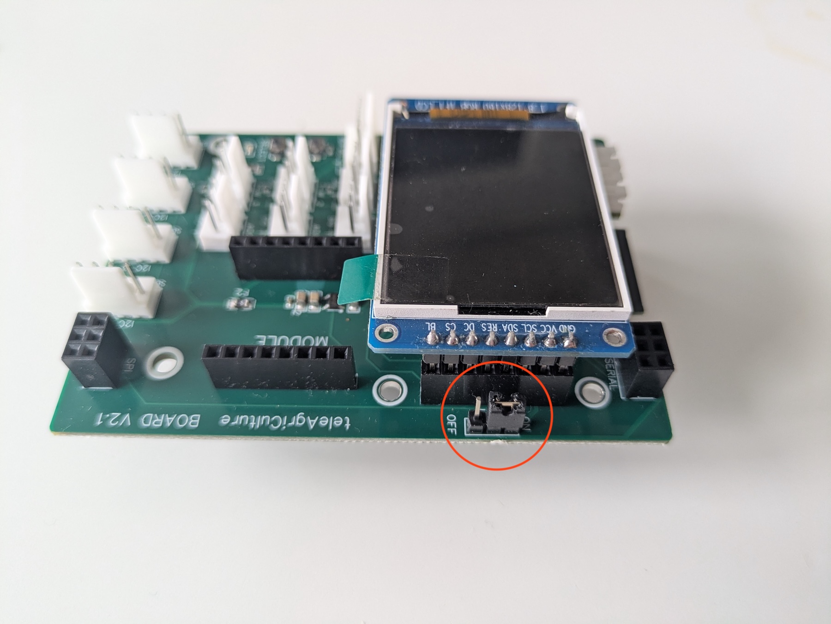
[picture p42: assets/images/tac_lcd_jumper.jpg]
| **Step 2:** Plug the lcd module enable jumper in the "On" position  |  |
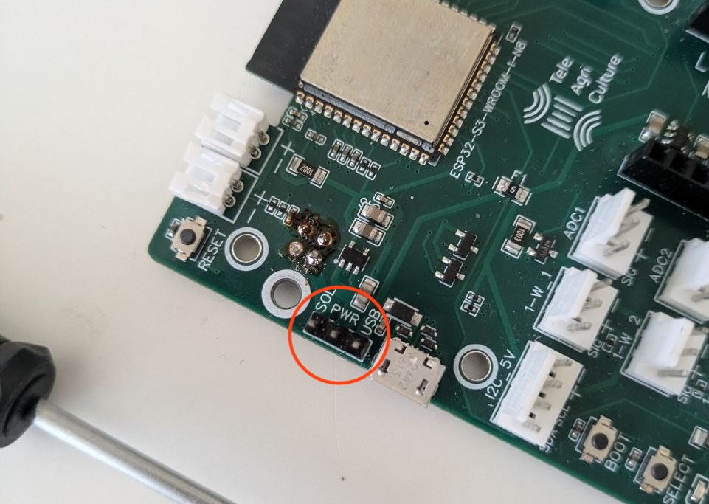
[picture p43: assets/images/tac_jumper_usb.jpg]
| **Step 3:** Set the jumper on the Teleagriculture board to use USB power by setting the jumper on the USB position  |  |

## Upload Minodu Firmware

You need to upload the specific Minodu firmware to the Teleagriculture Board. There are two ways to do that:

### Upload firmware via config menu

* Download the firmware file to your computer from here: [https://github.com/MinoduLCN/minodu-teleagriculture-firmware/raw/refs/heads/main/Firmware/firmware_EU_868_v_m179.bin](https://github.com/MinoduLCN/minodu-teleagriculture-firmware/raw/refs/heads/main/Firmware/firmware_EU_868_v_m179.bin)
* Power up the Teleagriculture Board, make sure it's in config mode, and connect to its wifi. SSID: *Teleagriculture Board*, Password: *enter123*
* Open the captive page, select *Update*, and select the firmware file you previously downloaded.

### Upload firmware via PlatformIO

* Clone the Minodu TAC repository: `git clone https://github.com/MinoduLCN/minodu-teleagriculture-firmware`
* Open the project in VS Code with the PlatformIO extension installed.
* Connect the Teleagriculture board to your computer.
* Press Upload in VS Code in the upper-right corner of the UI.

## Connect Sensors

Connect the sensors to the following ports on the Teleagriculture Board:

| Sensor | Connection | Description |
| --- | --- | --- |
| Multichannel Gas Sensor V2 | I2C (5V) | NO2, CO, C2H5OH - placed in the Stevenson screen |
| BME 280 | I2C (3V) | Temperature, Humidity, Pressure - placed in the Stevenson screen |
| LTR 390 | I2C (3V) | ambient light, UVA (UV light) - placed in the Stevenson screen |
| DHT22 | 1-W | Temperature & Humidity - placed inside the protection box |
| Sparkfun Anemometer | 1_W | Wind Speed |
| Sparkfun Windvane | ADC | Wind Direction - Place a Pullup resistor of 4,7 kOhm between 5V and Signal Wire |

## Setup Firmware configuration

This step guides you on how to configure the Teleagriculture board to connect to your Minodu network.

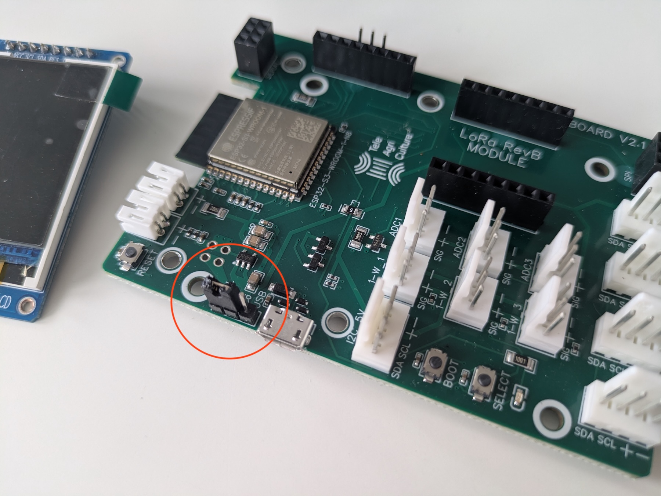
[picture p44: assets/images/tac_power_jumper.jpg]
| **Step 1:** Make sure the power jumper is set to the *SOL* power position. |  |
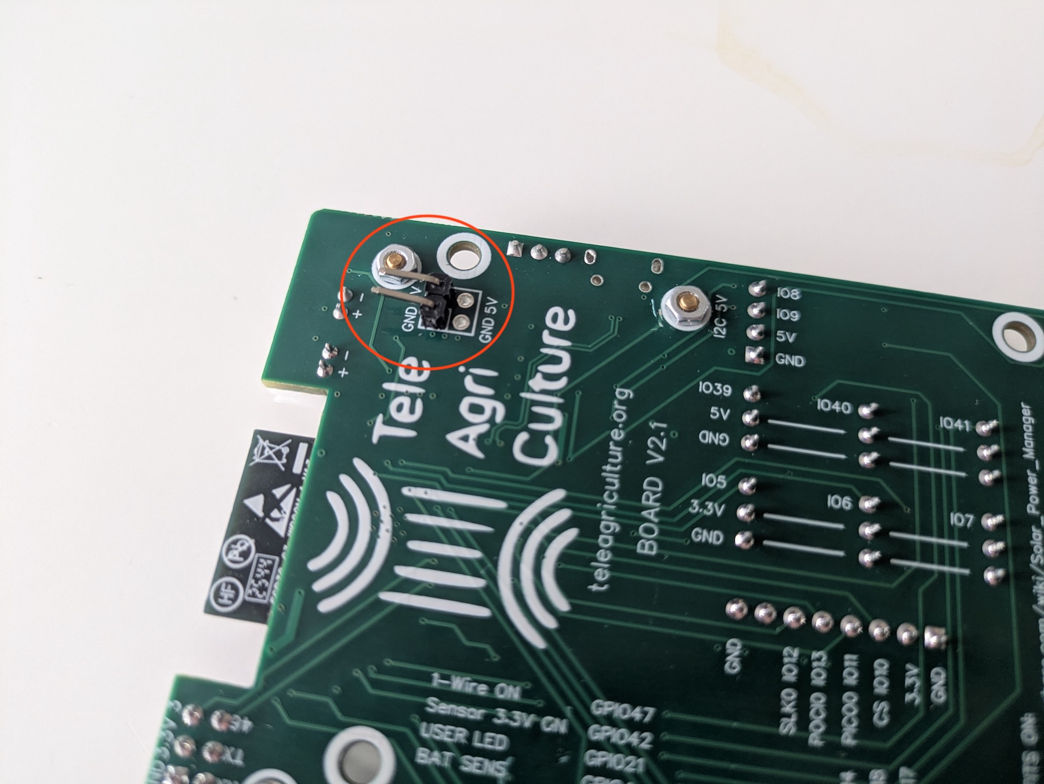
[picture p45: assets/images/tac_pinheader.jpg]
| **Step 2:** Solder an angled two Pin header on the bottom of the Teleagriculture Board to the Pins labeled GND and 5V |  |
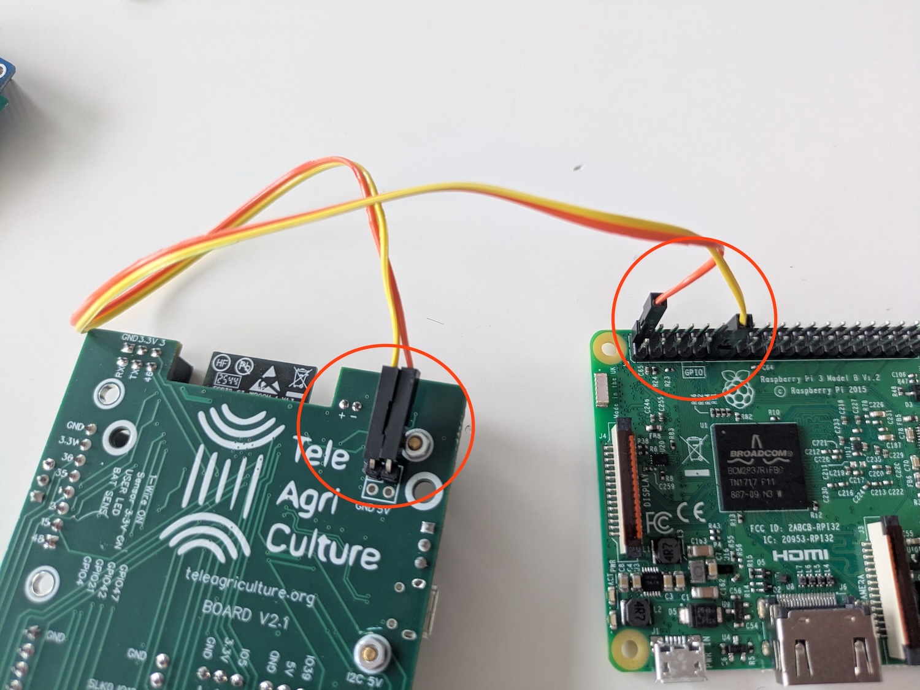
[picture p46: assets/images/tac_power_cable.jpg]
| **Step 2:** Connect a power cable between the soldered jumper and the raspberry PI header. The 5V cable should be connected to the PIN2 on the PI (That is the first pin in the outer row). The GND cable should be connected to PIN9 (That is the 5th pin in the inner row).  |  |
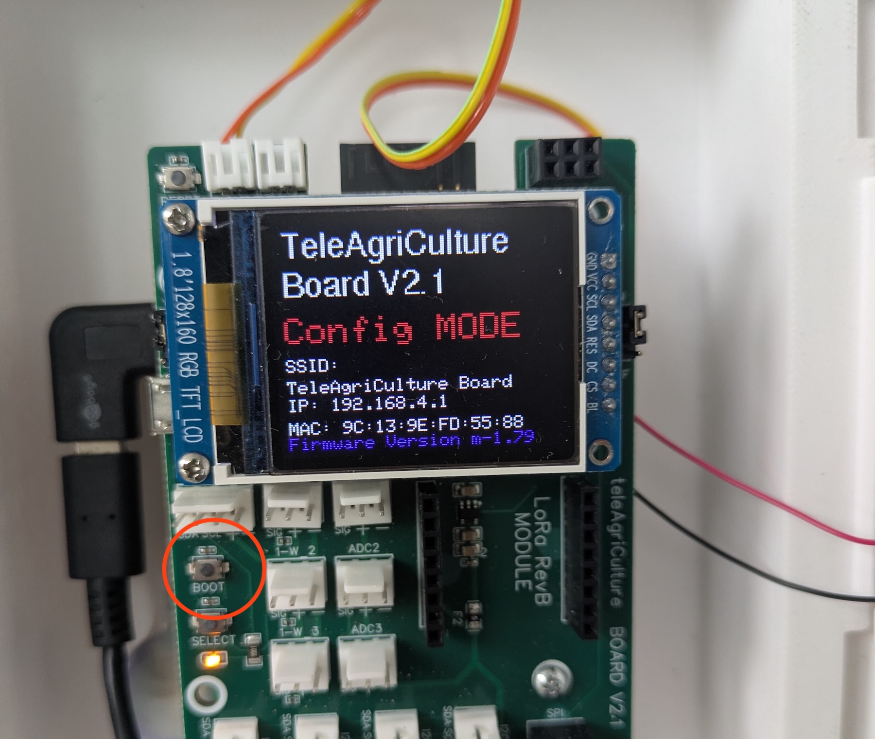
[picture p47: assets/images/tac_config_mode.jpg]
| **Step 3:** The display should show *Config Mode*. If it is not in config mode, press reset, then press the boot button for about 5 secs.  |  |
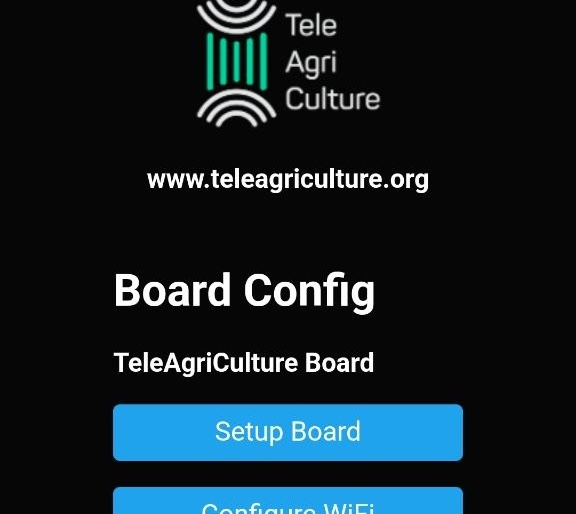
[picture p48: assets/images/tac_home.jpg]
| **Step 4:** Connect to the board via wifi, SSID is *Teleagriculture Board*, the password is *enter123*, and open the captive page by pressing *Sign In*. |   |
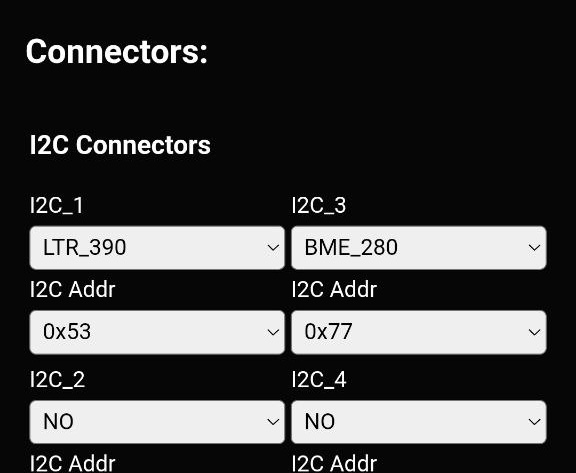
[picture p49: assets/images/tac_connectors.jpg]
| **Step 5:** Enter *Setup Board* and select the sensors that are connected to the board by selecting the specific sensor for the connectors. Make Sure to specify the right connector to which the sensor is attached to. |   |
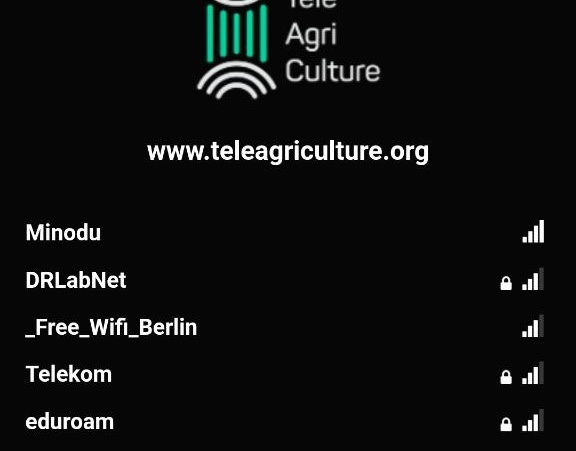
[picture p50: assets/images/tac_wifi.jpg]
| **Step 6:** Enter *Setup Wifi* and connect to the network of your Minodupi. |   |

Your Teleagriculture Board is now connected to your Minodu system. The current weather data should be shown within the Minodu app and can be downloaded through the backoffice.

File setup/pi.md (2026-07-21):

---
layout: page
title: RPI Setup
---

This will guide you through the setup process of the Minodu LCN on the Raspberry Pi.

## Requirements

* A Raspberry pi 4 or 5, preferebly with 8GB of ram.
* An ethernet adapter and a cable
* An SD card reader and an sd card with a minimum size if 64GB.
* Python has to be installed on your computer

## Setup Raspberry Pi Image

### Create Base Image

* Install Raspberry Pi OS Lite (64 bit) on Raspberry Pi. (Tested with this [version](https://downloads.raspberrypi.com/raspios_lite_arm64/images/raspios_lite_arm64-2026-04-21/).) You can use [Raspberry PI Imager](https://www.raspberrypi.com/software/) to create the Image

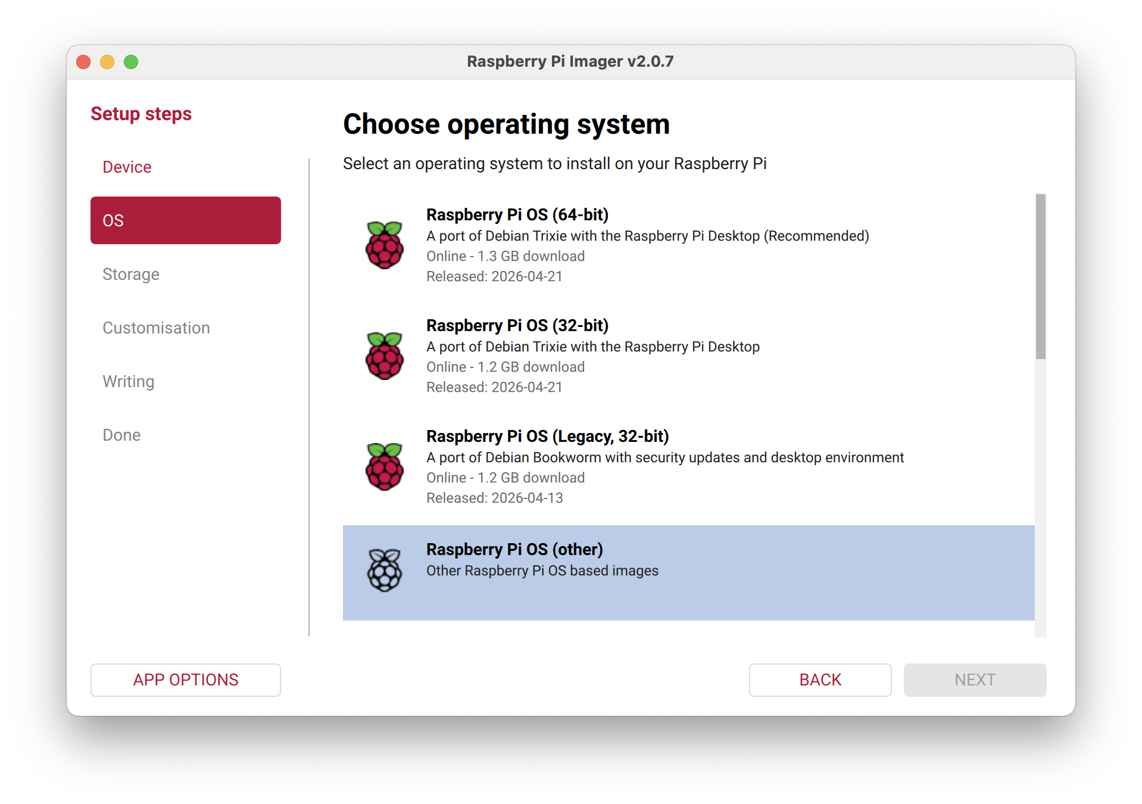
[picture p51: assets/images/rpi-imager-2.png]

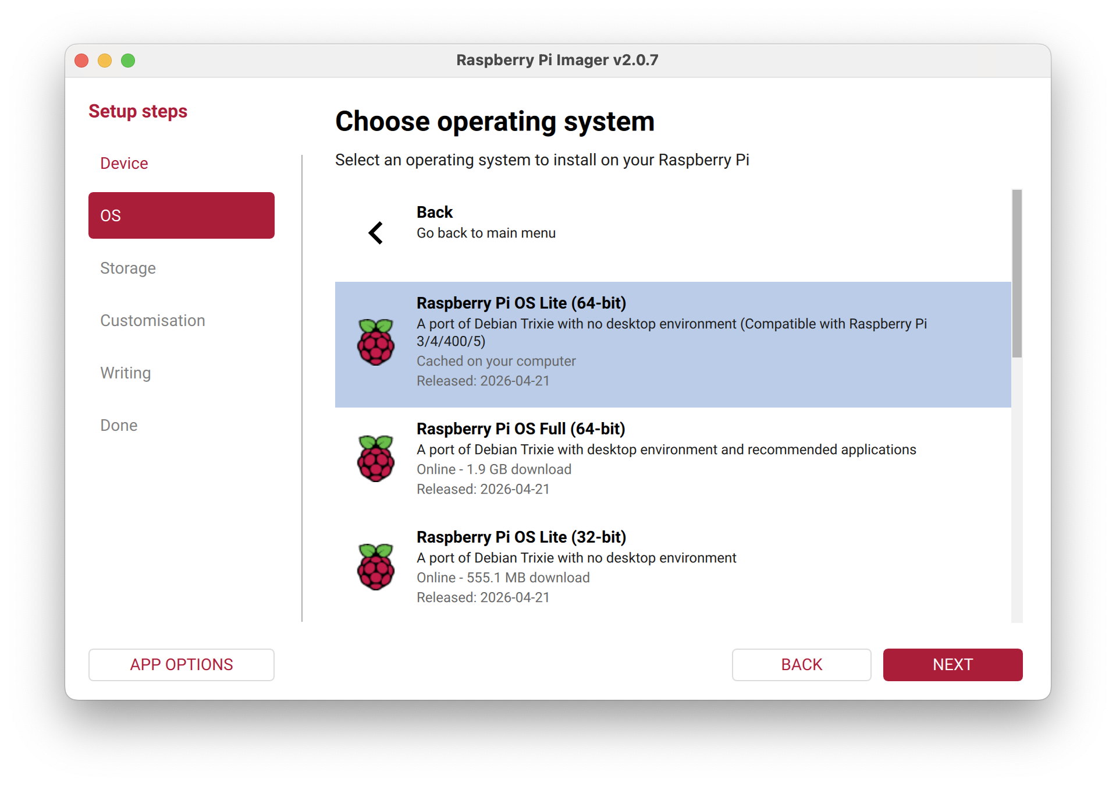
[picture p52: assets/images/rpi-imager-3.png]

* Set the hostname to minodupi.local, the username to pi and enable ssh in the custom settings of the image. remember the password you choose and write it down.
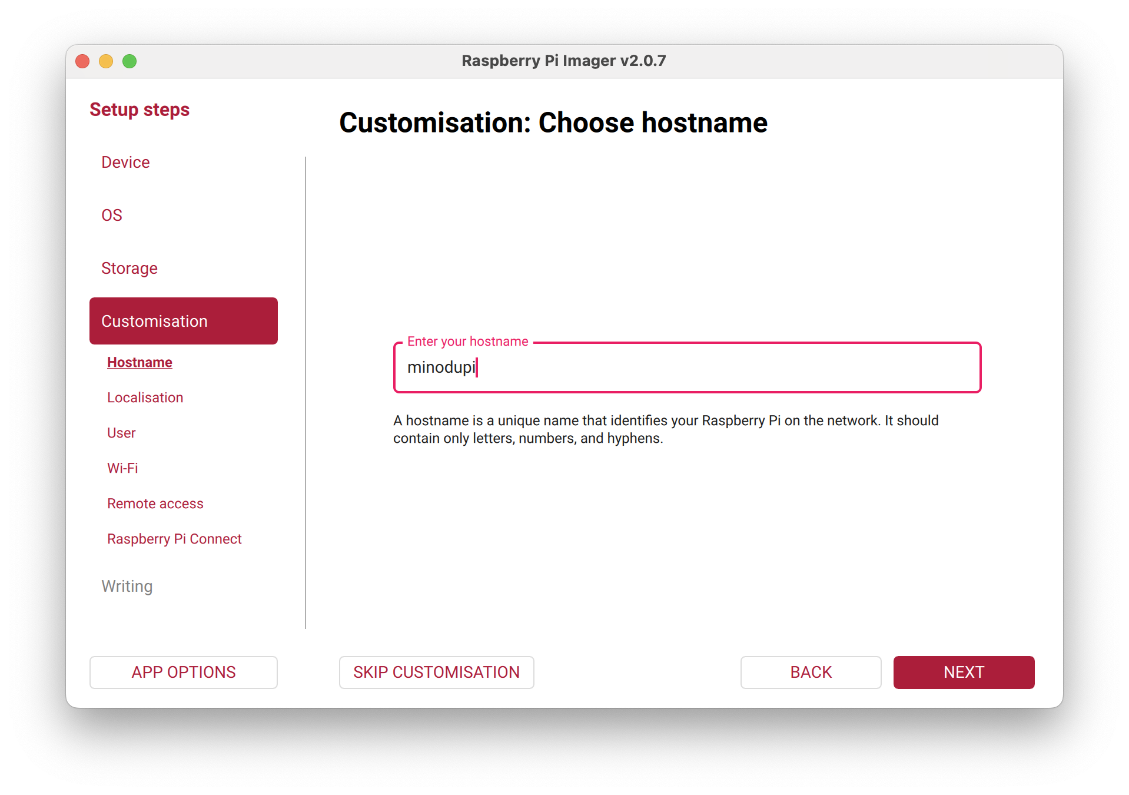
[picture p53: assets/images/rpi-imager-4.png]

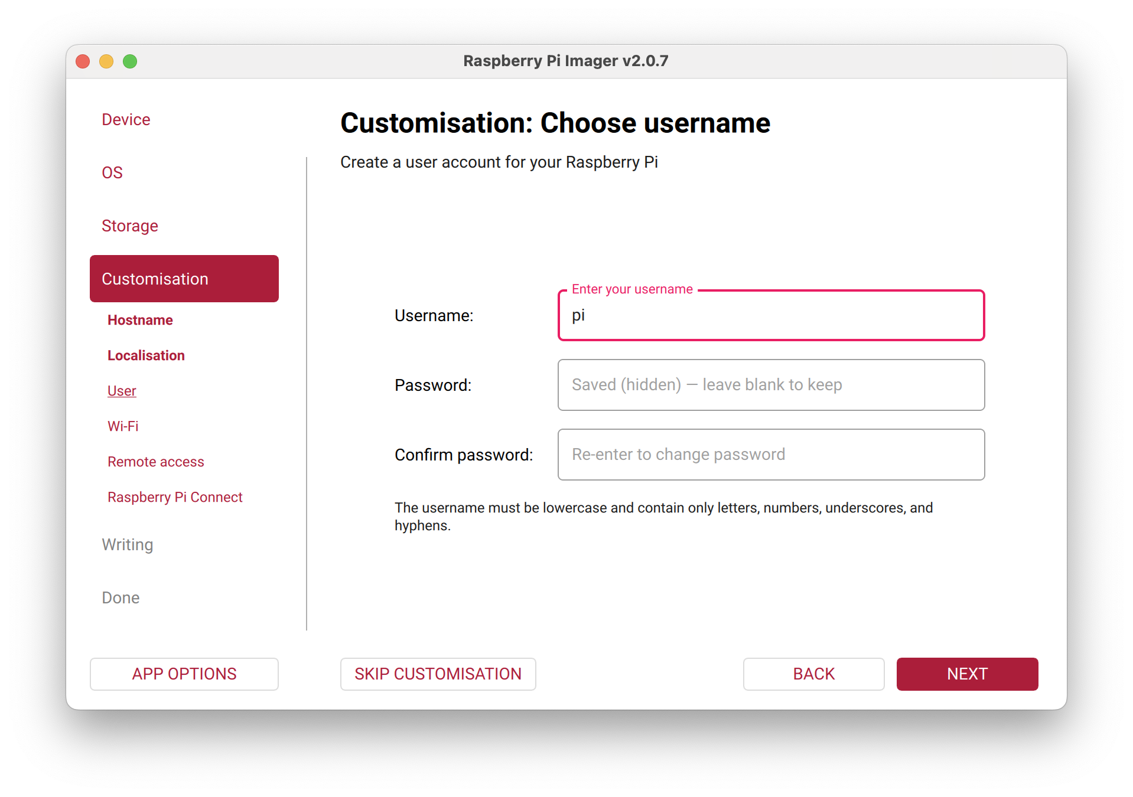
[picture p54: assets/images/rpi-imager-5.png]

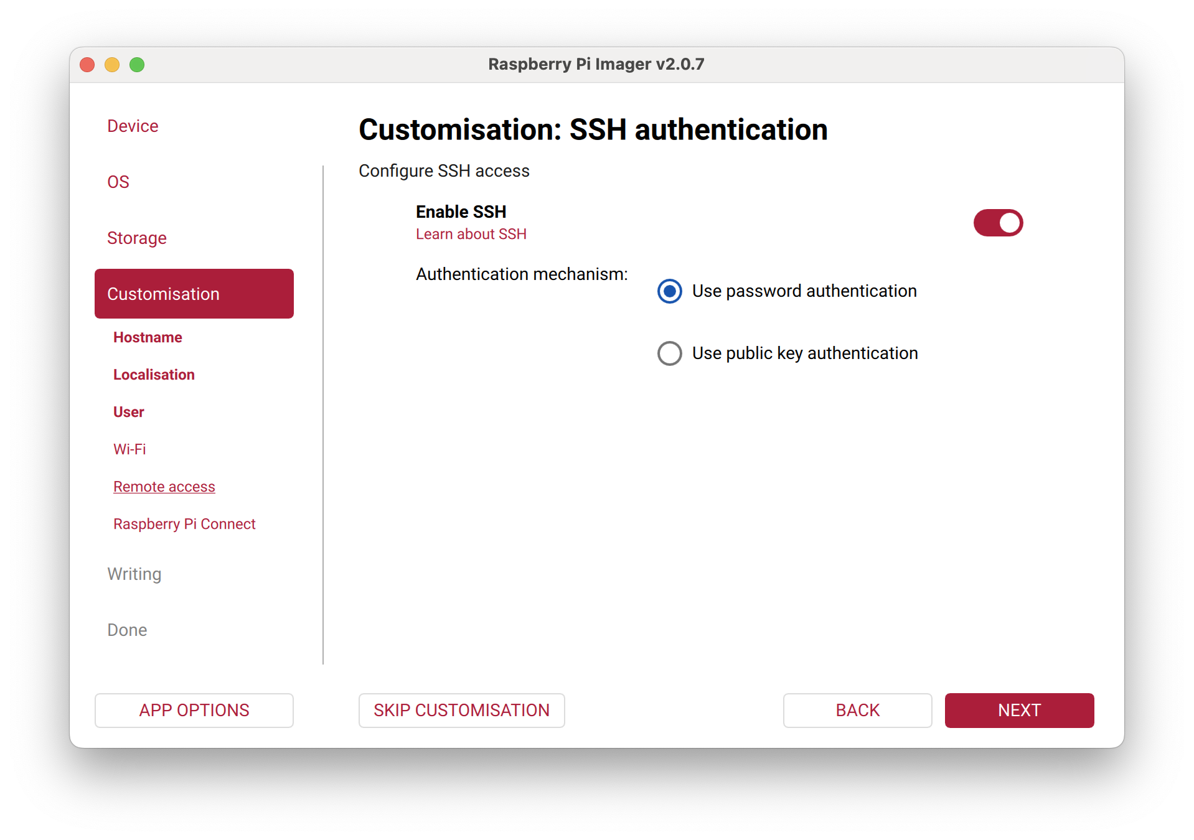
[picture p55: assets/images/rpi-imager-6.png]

* Once the image is written, insert the sd card into the pi

### Connect to RPI

* Connect via ethernet cable to raspberry pi and enable internet Sharing on mac, alternativly, you can plug the raspberry pi into your dhcp router via ethernet
* Make sure `ping minodupi.local` returns an answer, meaning your machine can discover the raspberry pi in the network
* Alternative: Connect Monitor do RPI and type in `ifconfig` to find out the RPIs ip address and use that one instead of *minodupi.local*

## Install MinoduLCN

* Run all of these commands on your host machine. **Don't run these scripts on the raspberry pi itself.**
* Download and unzip the minodu installer from [https://github.com/MinoduLCN/minodu-installer/archive/refs/heads/main.zip](https://github.com/MinoduLCN/minodu-installer/archive/refs/heads/main.zip) or download it with `curl -L https://github.com/MinoduLCN/minodu-installer/archive/refs/heads/main.zip -o repo.zip && unzip repo.zip`
* Open a terminal and run:
  ```
  cd minodu-installer-main
  pip install pyinfra
  # run full install script
  pyinfra @ssh/minodupi.local deploy.py -v --ssh-user="pi" --ssh-password="<pi-user-password>"
  # or using an ip address
  pyinfra @ssh/<ip-address> deploy.py -v --ssh-user="pi" --ssh-password="<pi-user-password>"
  # or run a single step 
  pyinfra @ssh/minodupi.local 01_system_packages.py -v --ssh-user="pi" --ssh-password="<pi-user-password>"
  # alternativly you can run the install script on the raspberry pi itself by logging in via ssh and running:
  pyinfra @local deploy.py
  ```
* It will ask you the following options. In [brackets] is the default value if you leave it empty. Installing the llm is only recommended on a raspberry pi 5 with at least 8gb of ram and a good cooling fan.
  ```
  WiFi SSID [Minodu]:
  WLAN country code [DE]:
  RaspAP admin password [secret]:
  Install Minodu LLM for Chatbot (y/n) [n]:
  Admin phone number [90000000]:
  Admin password [secret]:
  ```
* Follow the instructions and wait until the installer is done, if you select to install the llm the install procedure will take much longer, since it needs to build the vector database on the raspberry pi.
* **The installer might drop the ssh connection after installing the wlan driver and throws an error. If that happens, just wait until it is rebooted and start the script again. It will skip the completed steps**

## Manual installation
If the installation script fails, you can check this repo to guide you through the manual installation process: [https://github.com/MinoduLCN/minodu-installer](https://github.com/MinoduLCN/minodu-installer).
  
## Troubleshooting

* Make sure raspberrpi is reachable with `ping minodupi.local`. If not. reinstall image and make sure to set the hostname to minodupi.local
* make sure there is a user on the raspberry pi with the name *pi* (standard username).
* Make sure ssh is enabled, test with `ssh pi@minodupi.local`. Default password is *raspberry*. If it is not working reinstall image and enable ssh access.
* Make sure your computer is connected to the internet during the install procedure.

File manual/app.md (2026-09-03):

---
layout: page
title: Le Manuel
---

baobab

## Toolkit for Setting Up a Local Network and a DIY Weather Station
{:.no_toc}

This manual is aimed at the agricultural producers of the communities we deployed the Local Community Network (LCN) in. The original french version was printed and handed out to the communities as a guide to accompany the usage of the LCN. It can be viewed and downloaded here: [french version of the manual (print)](../assets/pdf/minodu_manuel_v2.pdf).

## Local Network / Réseau Local
___
<br>
Your local network (réseau local) runs on a single mini-computer called a Raspberry Pi. When you turn it on, it creates a private Wi-Fi network (without internet access!) that is accessible to everyone in your community via an Android phone. Through this private Wi-Fi network, you can access agricultural content in Kabiyè and French.

### The LCN application
Welcome to your digital platform! It is designed to help you:
- get farming advice
connect with others and share your knowledge and challenges on the field
- access local weather information
- sell your products at the market

**Additional information:**
*The application was implemented with the expertise of the technical team:
Séti AFANOU (software), Ousia FOLI-BÉBÉ (hardware/software interface), Friederike Fröbel (coordination and management), Lutz Reiter (software), Eric Tiedt (illustrations, animations), Victoire TSAMEDI (database), Jannes Ulbrich (UI/UX design, wireframing)*

### Access the app

| --- | --- |
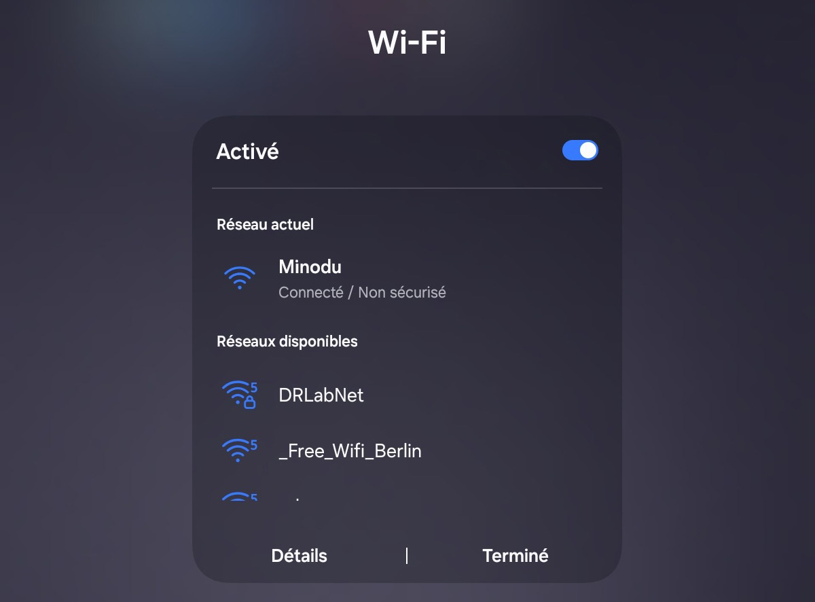
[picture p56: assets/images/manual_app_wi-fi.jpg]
manual_wifi
| 1) Start by connecting to the "Minodu" Wi-Fi network. |  |
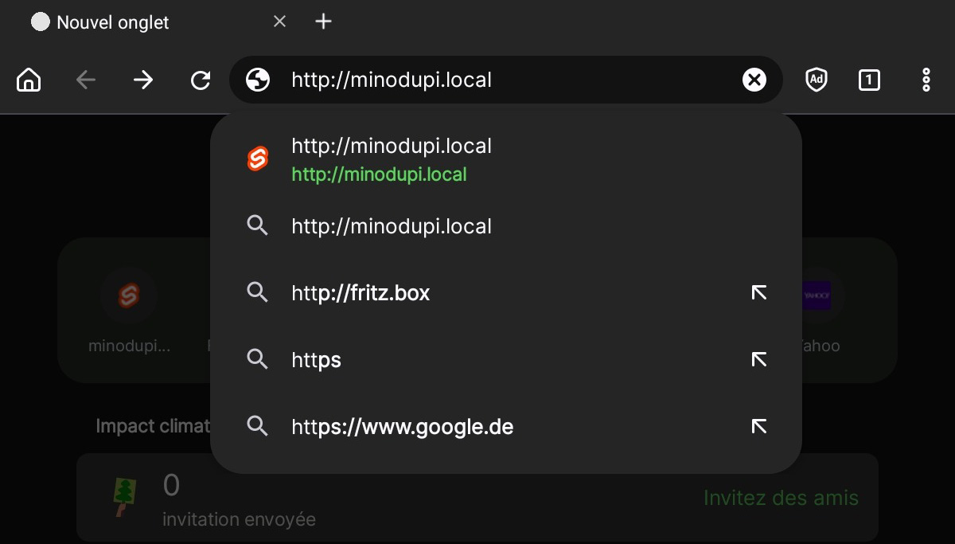
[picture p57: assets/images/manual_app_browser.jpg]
manual_browser
| 2) Open your browser and enter the address <span style="color:#25B86E">**minodupi.local**</span> |  |

<span style="color:#fff; background-color:#25B86E; padding:10px">http://minodupi.local</span>

### Home Page
This is where you land when you launch the local network. This is the home page.

The app is divided into four sections: agriculture, market, forum, and weather.

Simply click on the section of your choice on the home screen or in the menu bar at the bottom of the interface to navigate to the selected section.

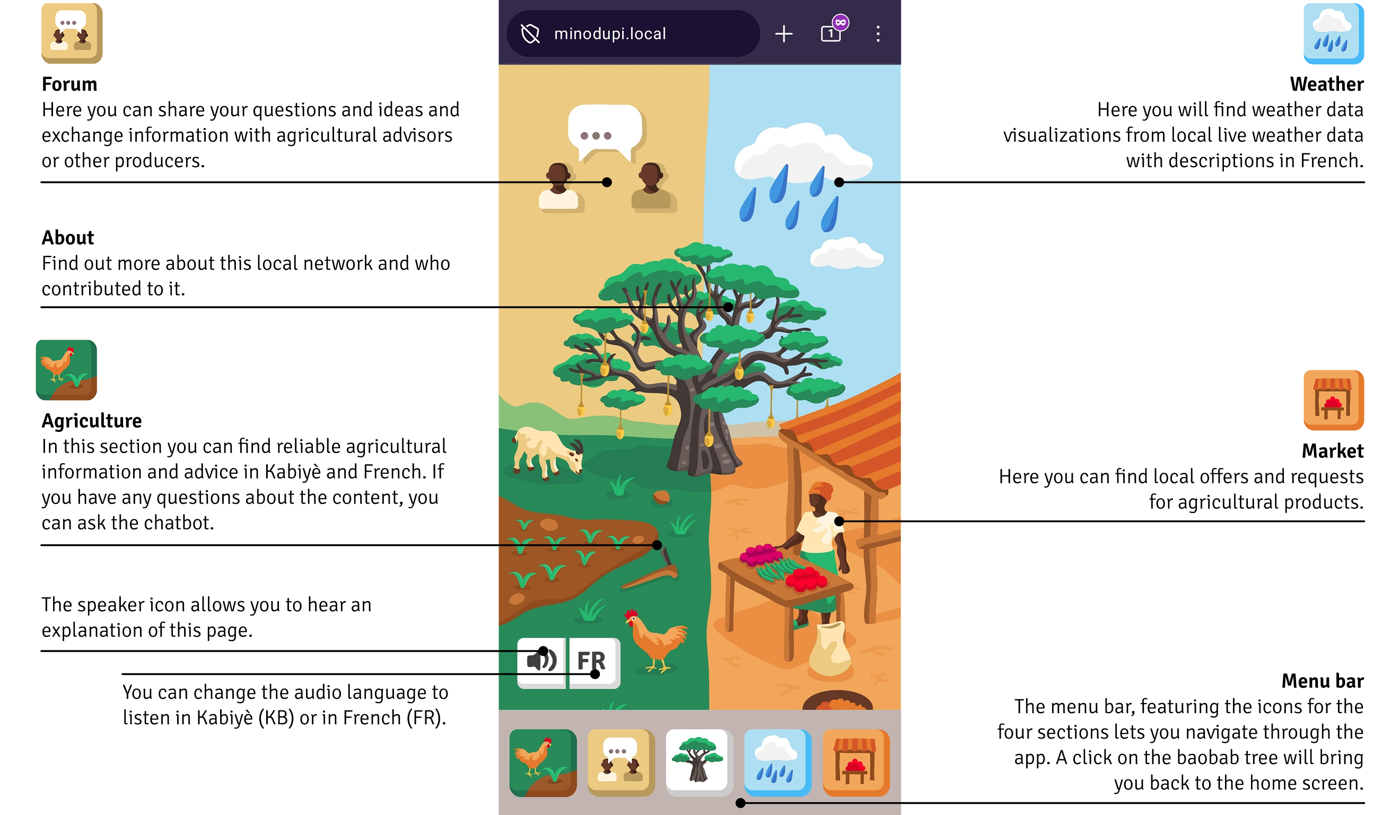
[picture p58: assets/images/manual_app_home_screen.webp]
home_screen


### Agriculture Page
This section contains reliable agricultural information and advice, as well as a chatbot—a conversational agent—that you can use to ask questions about the content.

This includes:
- best farming practices
- advice on crops, soil conservation, and livestock farming
- innovations and sustainable techniques

Improve your yields and make better farming decisions.

**How to use the agriculture page?**

The audios are organized into four categories: plants, soil, livestock, and other. You can select or deselect the different categories by clicking on their icons at the top.

To access the audio files:
Click the play button (small triangle) to play the audio. 
To pause, click the two lines that appear once you start playing the audio.

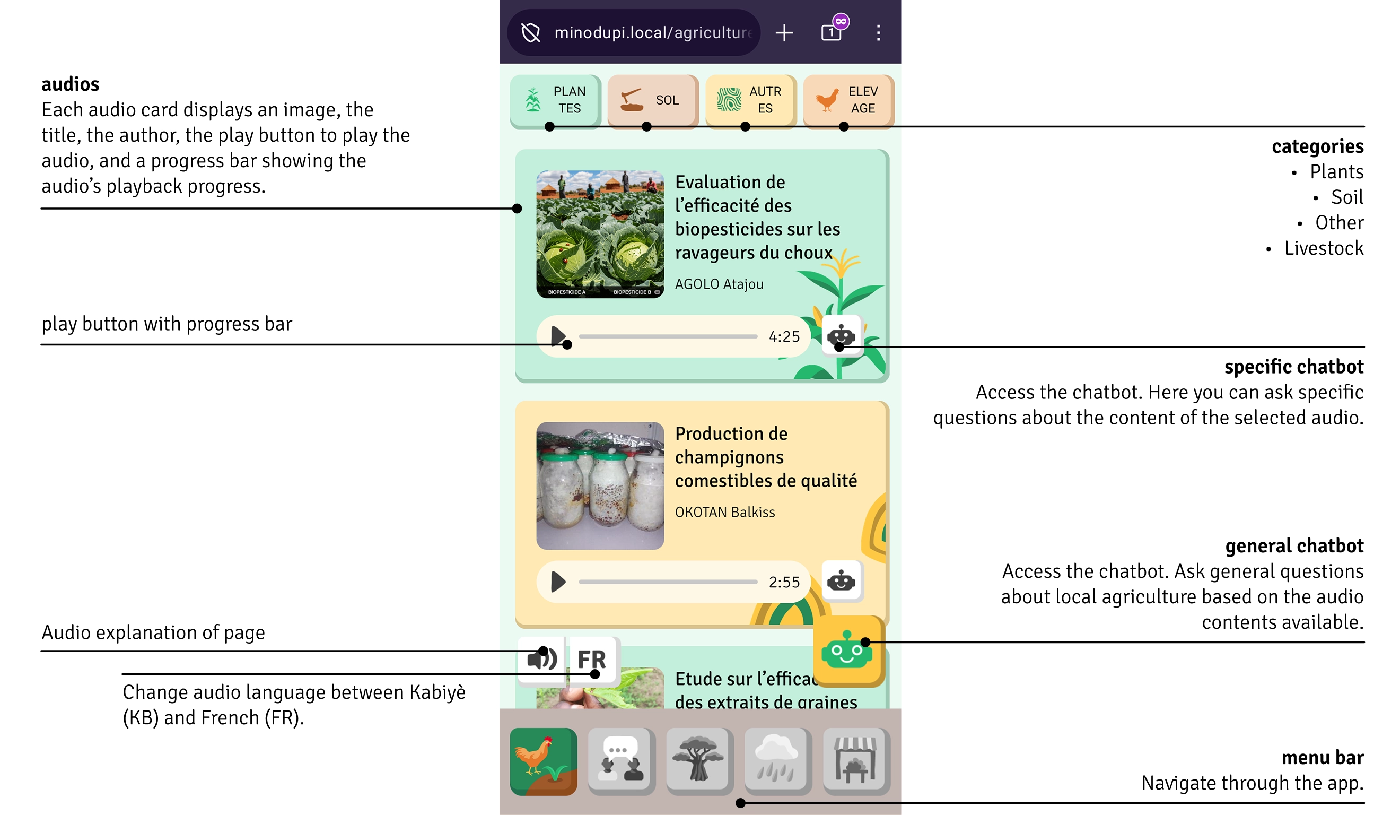
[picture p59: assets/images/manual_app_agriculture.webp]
agriculture


### Chatbot
The chatbot can answer your questions about agriculture around the clock. It can only understand and speak French.

**How to use the chatbot?**

When you open the chatbot, it will greet you. To respond to the chatbot and ask your question, you have two options:
1. Record an audio message by clicking the white microphone icon on a green background and speaking. Your message will be automatically transcribed into text. Note: Make sure the audio recording is no longer than 30 seconds.
2. Write a message using the white field at the bottom and type your message there.

Then, click the green paper airplane icon to send your question.

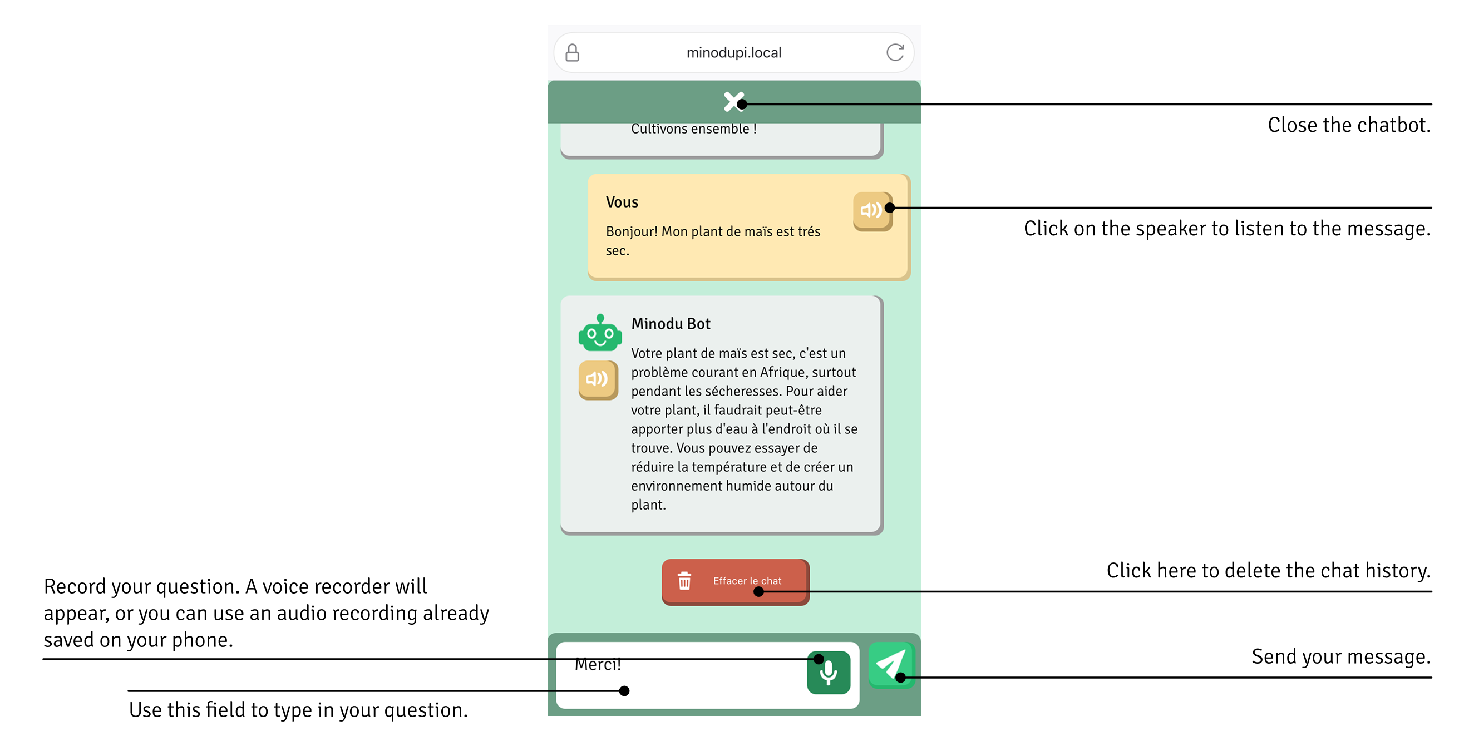
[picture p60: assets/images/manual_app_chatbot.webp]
chatbot


### Forum
Connect with the active community:
- Ask questions via text or voice message
- Share photos of issues in your fields
- Share your experiences and chat with other farmers from your community
- Discuss the challenges and opportunities facing the agricultural sector

Because agriculture thrives best when we work together. Messages can be transcribed and listened to only in French.

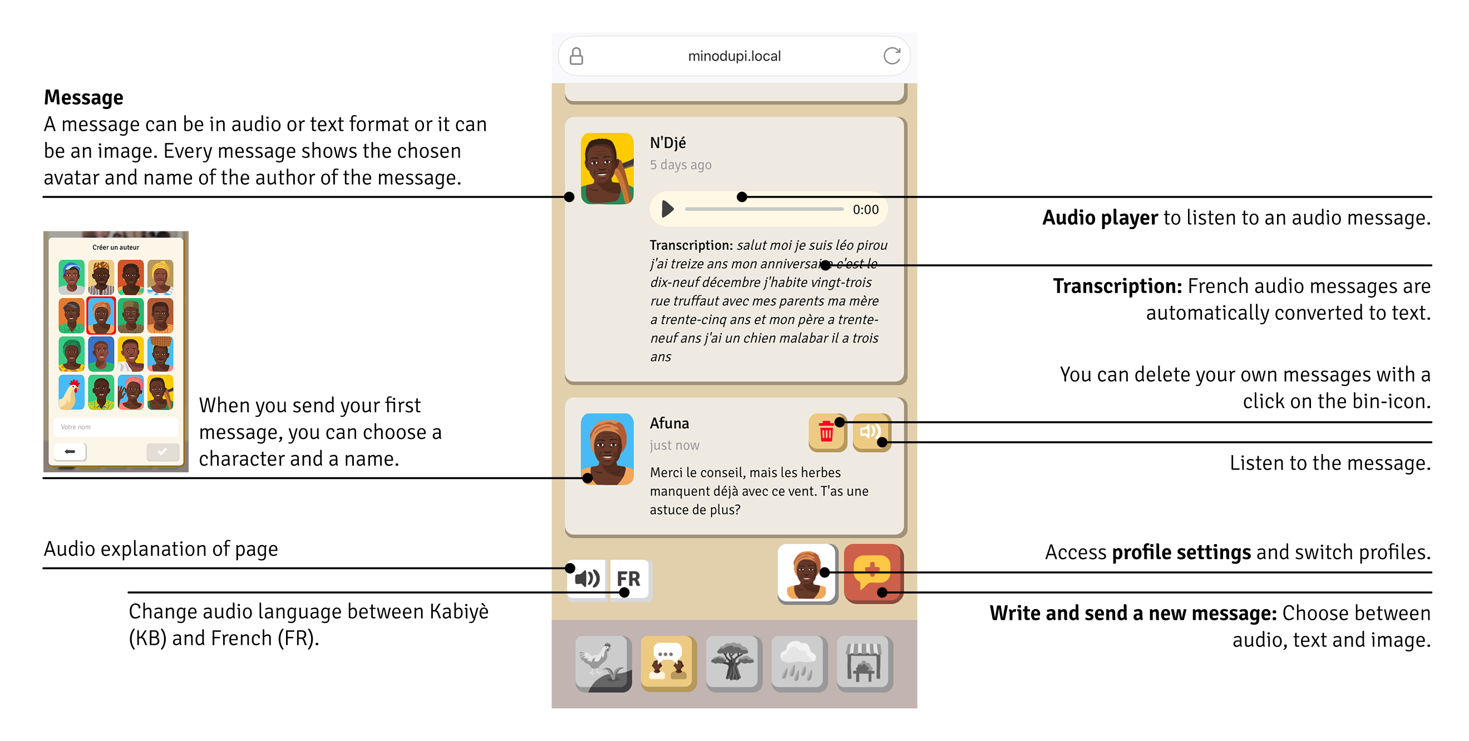
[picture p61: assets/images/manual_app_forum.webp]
forum


### Weather
This screen visualizes local live weather data. The current weather is displayed through animations and shown in figures. The audio weather report gives you information about the current weather.

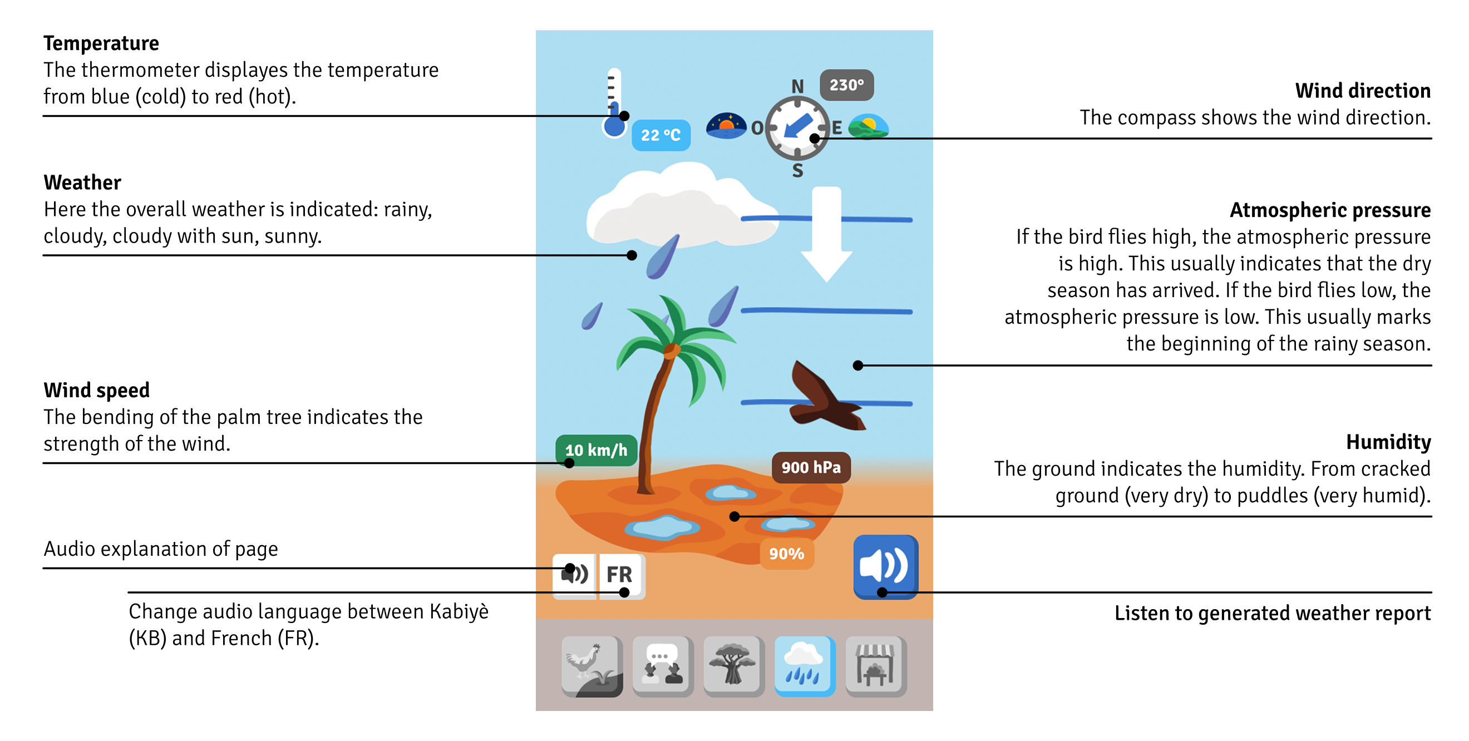
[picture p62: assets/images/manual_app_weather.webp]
weather


### Market
Welcome to your local digital marketplace! Here you can view various listings. The contact person in your community receives requests from wholesalers and posts them here. This way, you can see how many units of each product are in demand and at what price.

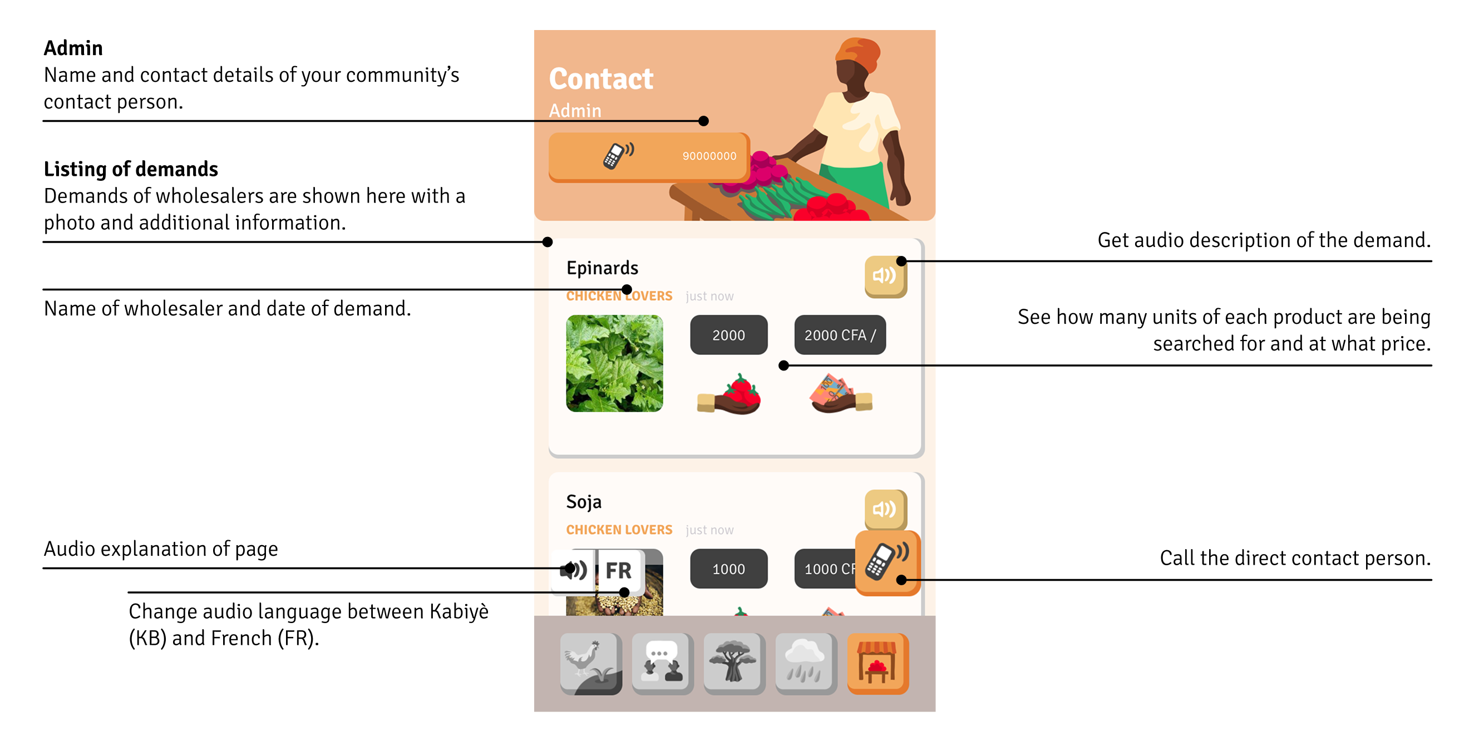
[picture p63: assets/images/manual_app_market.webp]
market


## Materials
___
<br>
Your toolkit contains all the equipment you need to set up your local network. Here are the four main components:

The Raspberry Pi mini-computer which is at the core of the local network, the weather station board which captures temperature, humidity, rain, wind and air quality, and the 3D printed protection box which keeps the boards dry and cool (protected from dust, heat and rain).

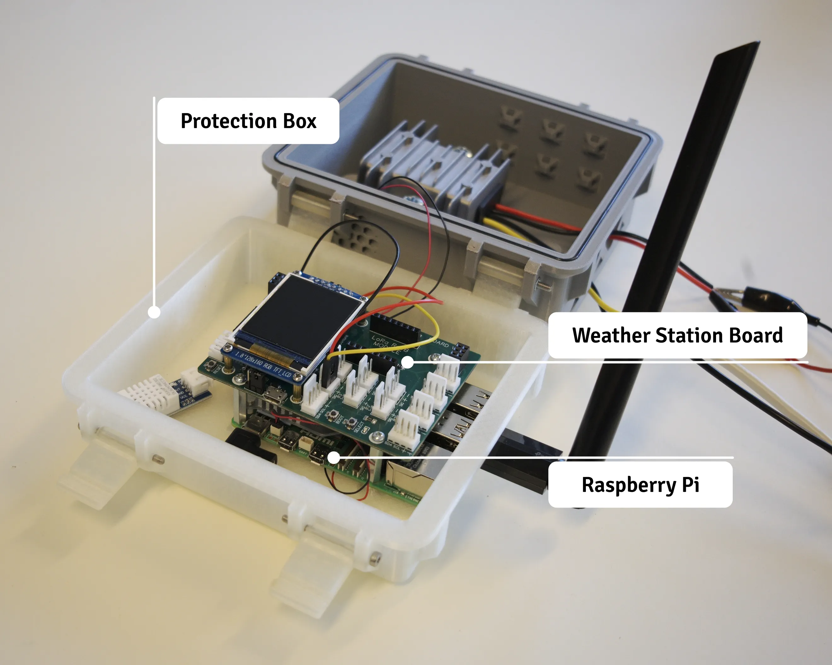
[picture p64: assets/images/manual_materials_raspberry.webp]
toolkit


Your Local Community Network is powered by a solar panel connected to a battery for complete energy independence.

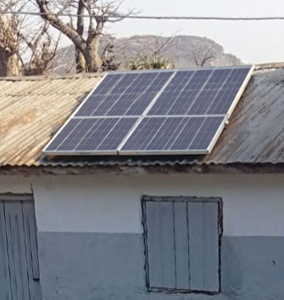
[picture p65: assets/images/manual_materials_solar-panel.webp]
solar-panel


### Core of the LCN: Raspberry Pi 5
The Raspberry Pi 5 is a small embedded module about the size of a credit card. It serves as the heart of your entire local network.

The Raspberry Pi is perfect for a local network because...
- it uses very little power,
- it is very compact: fits in a pocket or a small box,
- it has multiple ports for connecting all your devices: USB, HDMI for a display, SD card slot, and GPIO ports for sensors.

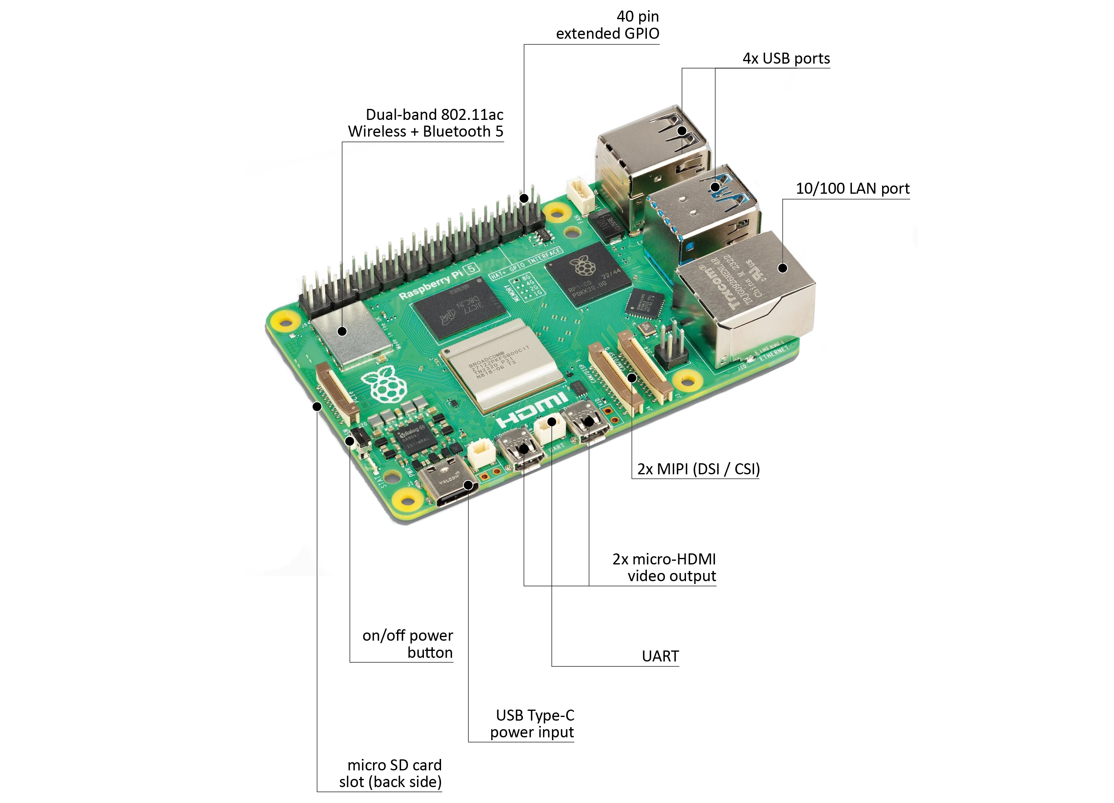
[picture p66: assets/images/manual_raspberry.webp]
raspberry


**Additional information:**
The Raspberry Pi is designed to make computers, digital transformation, and innovation accessible to everyone. It can be described as a mini-computer because, once you have one, all you need to do is connect a monitor, keyboard, and mouse, and you can use it just like a regular computer.

### Weather station: TeleAgriCulture Board & sensors
The TeleAgriculture board is a module to capture weather data, it has several ports to connect sensors to. The weather station's sensors provide information on current local conditions.

| Sensor | Measures |
| --- | --- |
| BME 680 | Temperature in °C, Humidity in %, Atmospheric pressure in hPa |
| LTR390 | Light in lux, UV radiation |
| Multichannel Gas Sensor V2 | Nitrogen dioxide (NO₂), Carbon monoxide (CO), Ethanol (C₂H₅OH) (overall air quality) |
| DS15901 | Wind speed in m/s, wind direction in degrees |

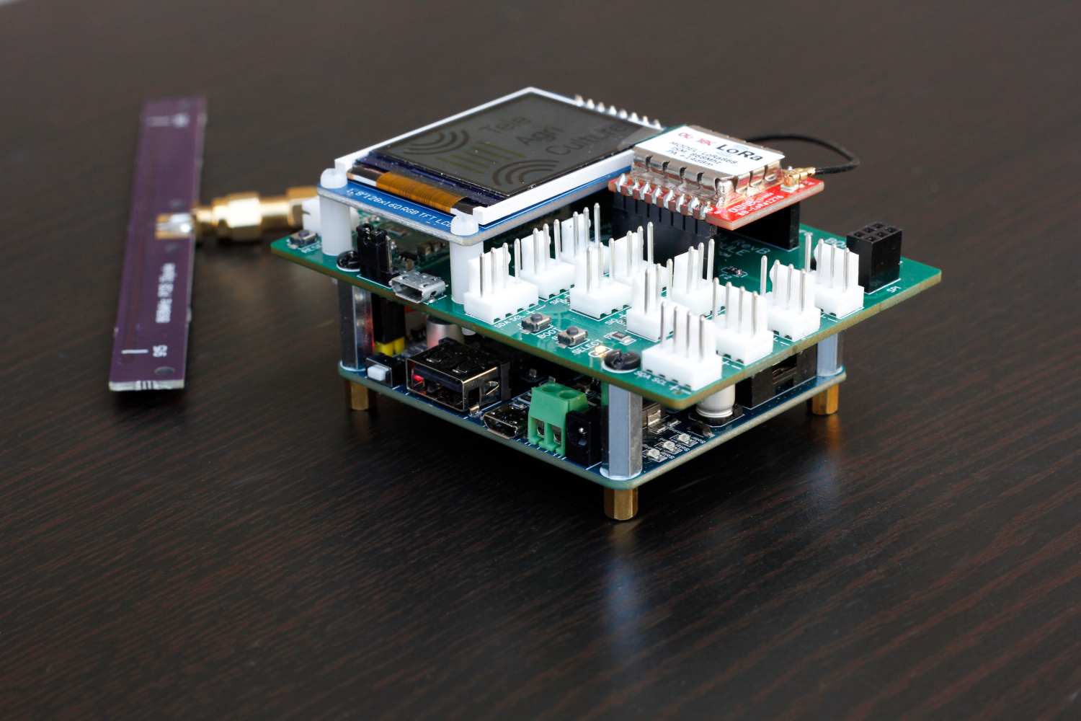
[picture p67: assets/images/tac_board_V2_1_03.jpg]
teleagriculture_board


**Additional information:**
The station is based on the TeleAgriCulture kit. TeleAgriCulture aims to make environmental sensing technologies and data visualization tools more accessible to anyone interested in exploring the interactions between plants, animals, humans, and their environment.  
*Developed by Daniel Fischer and Julian Stadon, and adapted for the local network by Lutz Reiter, Ousia FOLI-BEBE, and Friederike Fröbel.*

### Admin panel & content management system
This admin panel is used to manage the content on the local network.  
Only the administrator has access to it. Please ask your community administrator for access.

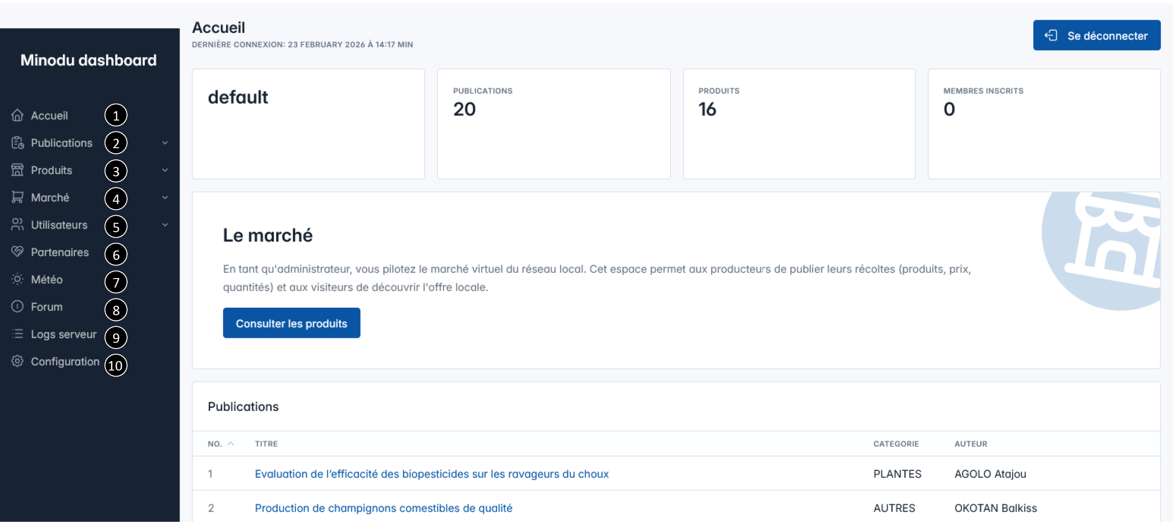
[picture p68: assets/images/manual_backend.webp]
backend


1. **Accueil:** This page is displayed here as a preview.
2. **Publications:** Management of audio content for the Agriculture section.
3. **Products:** Management of products for your village’s market.
4. **Market:** Management of products requested by wholesalers.
5. **Users:** A list of people who have access to the CMS.
6. **Partners:** Wholesalers are registered here.
7. **Weather:** Weather data is available here, along with historical data.
8. **Forum:** Manage forum discussions and posts.
9. **Server Logs:** Access to view and manage server logs.
10. **Configuration:** Enter the name, location, and other information about your community.

---  
<br>
This is the user manual. For guidance for administrators and management of the system please take a look at the *[backoffice manual](backoffice.md)*.

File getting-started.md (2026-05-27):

---
layout: page
title: Getting Started
permalink: /getting-started/
---

## Prerequisites

Before you begin, make sure you have the following installed:

- **Requirement A** — version X or higher
- **Requirement B** — version Y or higher
- *(add your actual prerequisites here)*

---

## Installation

```bash
# Example installation command — replace with the real one
npm install minodu
# or
pip install minodu
```

---

## Quick Start

1. **Step one** — describe what the user does first.

   ```bash
   minodu init my-project
   ```

2. **Step two** — describe the next action.

   ```bash
   cd my-project
   minodu run
   ```

3. **Step three** — confirm it works (expected output, URL to visit, etc.).

---

## Next Steps

- Explore all available [Features](../features)
- Read the full [Documentation](../docs)
- Learn [About](../about) the project and how to contribute

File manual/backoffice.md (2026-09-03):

---
layout: page
title: Backoffice
---

## Minodu – Administrator Backoffice Documentation
{:.no_toc}

|---|---|
| **Version** | 1.0 |
| **Date** | May 2026 |
| **Language** | English |
| **Audience** | Minodu system administrators |

---

## Authentification – Login
The login page is the single entry point to the Minodu backoffice. Only users with the **ADMIN** role and an **ACTIVATED** account can access the platform.

### 1.1 Features
{:.no_toc}
- Authentification using phone/username and password
- Show/hide password using the eye icon
- Session management via tokens (JWT)
- Custom error messages depending on the failure type
- Protection against unauthorized access

### 1.2 Access Instructions
{:.no_toc}
To log in to the Minodu backoffice dashboard:

1. Open your web browser and navigate to: **http://minodu.local:8080**
2. You will be presented with the Minodu login screen.
3. Enter your credentials in the designated fields:

| Field | Value |
|---|---|
| **Username** | `admin` |
| **Password** | `secret` |

4. Click the **"Login"** or **"Connexion"** button to authenticate.

### 1.3 Screenshots
{:.no_toc}

| Description | Screenshot |
|---|---|
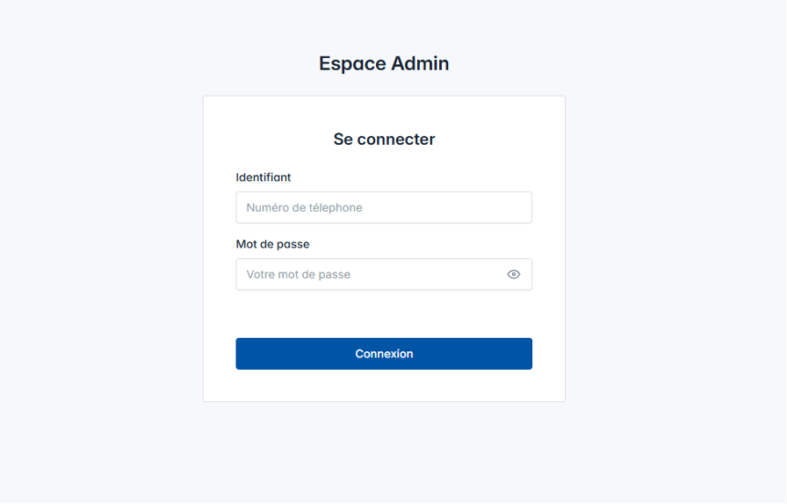
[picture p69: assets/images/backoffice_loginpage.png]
Login_page
| Login page – full form |  |

---

## Home – Dashboard

The first page displayed after login. It provides a statistical overview of the Minodu community with key indicators updated dynamically in real time.

### 2.1 Features
{:.no_toc}
- Display of the community name
- Publications counter
- Products counter
- Registered members counter
- Last login timestamp
- Logout button with confirmation modal
- Real-time data updates

### 2.2 Sections
{:.no_toc}
#### Section 1 – Header with logout
{:.no_toc}

|---|---|
| **Title** | Welcome message with the admin name |
| **Action** | “Logout” button → opens confirmation modal |

#### Section 2 – Statistics cards
{:.no_toc}

| Card | Description |
|---|---|
| **Card 1** | Community name |
| **Card 2** | Total number of publications |
| **Card 3** | Total number of products |
| **Card 4** | Total number of registered members |

#### Section 3 – Marketplace presentation
{:.no_toc}
Descriptive section of the platform with a general description and information about the Minodu marketplace.

#### Section 4 – Logout confirmation modal
{:.no_toc}
Confirmation popup before logout. Buttons: **Confirm / Cancel**.

#### Section 5 – Recent publications list
{:.no_toc}

Displays recent publications from the community.

### 2.3 Screenshots
{:.no_toc}

| Description | Screenshot |
| ---- | ---- |
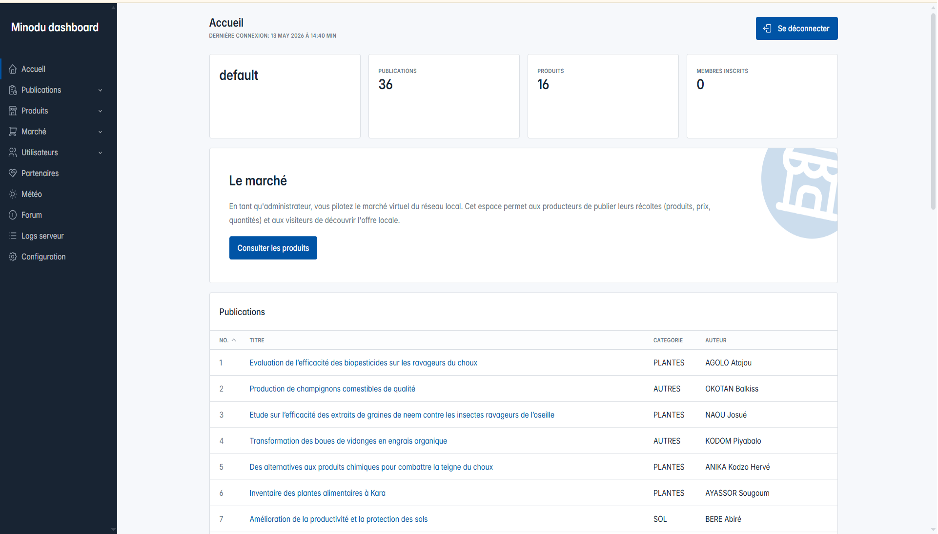
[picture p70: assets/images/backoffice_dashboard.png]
dashboard
| Complete dashboard |  |
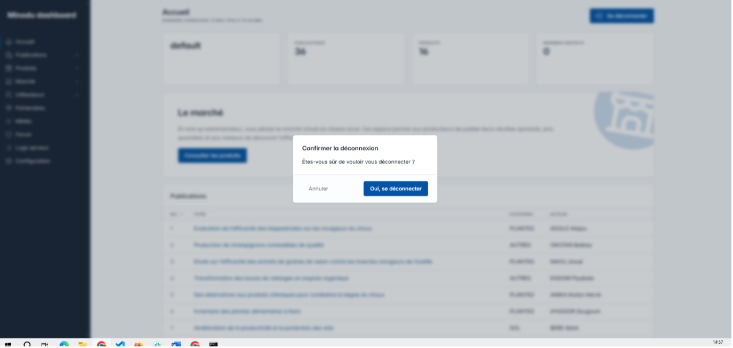
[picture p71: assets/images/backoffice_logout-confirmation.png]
logout
| Logout confirmation modal |  |

---

## Publications
Module for managing the Minodu community’s editorial content. This module is divided into four subsections: publication list, categories, tags, and the detailed view of a publication.

### 3.1 Publication List

**Full CRUD – publications with media and attachments**

Displays and manages all community publications. The administrator has access to all CRUD operations as well as advanced search and filtering tools.

#### Features
{:.no_toc}

- **Read:** paginated publications table
- **Create:** add via dedicated modal
- **Update:** edit all properties
- **Delete:** with confirmation modal
- **Search:** filter by title, author, category, and tags
- **Uploads:** images, French/Kabiyè audio, PDF, resources

#### Sections
{:.no_toc}

**Section 1 – Title bar and actions**

|---|---|
| **Title** | “Publications” |
| **Action** | “Add” button |

**Section 2 – Filters and search**

|---|---|
| **Search** | Text field – filter by title, author, category, and tags |

**Section 3 – Publications table**

|---|---|
| **Column 1** | Publication title |
| **Column 2** | Category |
| **Column 3** | Author |
| **Column 4** | Actions: Edit \| Delete |
| **Navigation** | Pagination between pages |

**Section 4 – Add/Edit modal**

|---|---|
| **Field 1** | Author (required) |
| **Field 2** | Title (required) |
| **Field 3** | Description (long text) |
| **Field 4** | Category (selector) |
| **Upload 1** | Main image (PNG/JPEG) |
| **Field 5** | Tags (multiple selection) |
| **Upload 2** | French audio |
| **Upload 3** | Kabiyè audio |
| **Upload 4** | PDF file |
| **Actions** | Save \| Cancel |

**Section 5 – Delete modal**
Confirmation before permanent deletion. Buttons: **Confirm / Cancel**.

#### Feedback messages
{:.no_toc}
- “Publication added successfully!”
- “Publication updated successfully!”
- “Publication deleted successfully!”

#### Screenshots
{:.no_toc}

| Description | Screenshot |
| ---- | ---- |
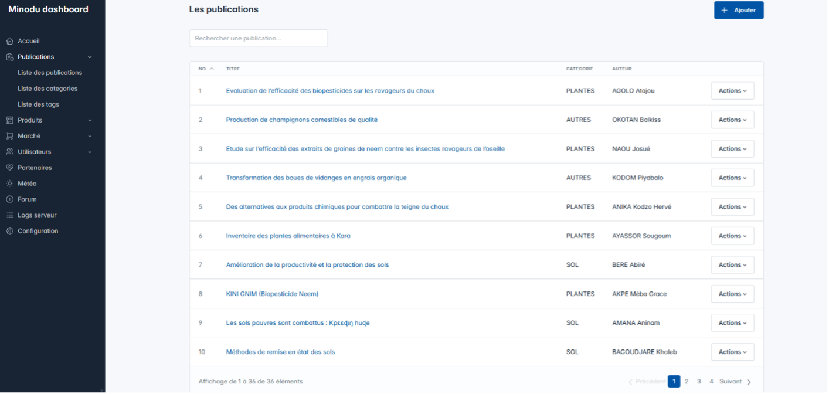
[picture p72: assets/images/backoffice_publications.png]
publications
| Publications – full table with pagination |  |
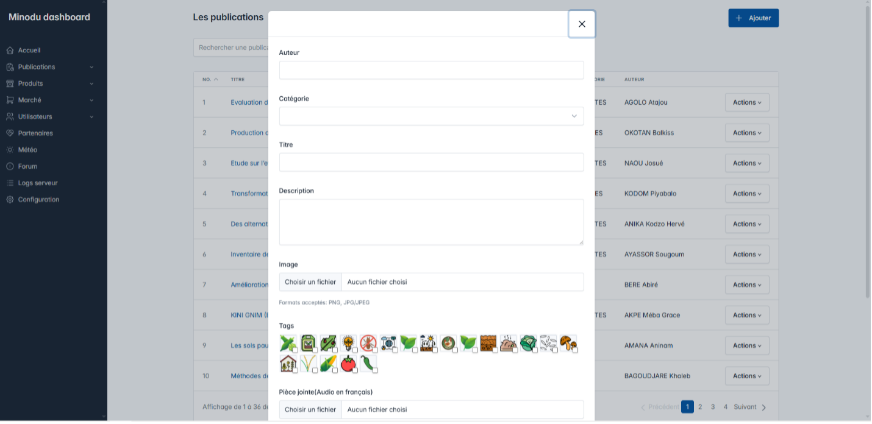
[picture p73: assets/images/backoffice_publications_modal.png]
publications_modal
| Publications – Add/Edit modal |  |
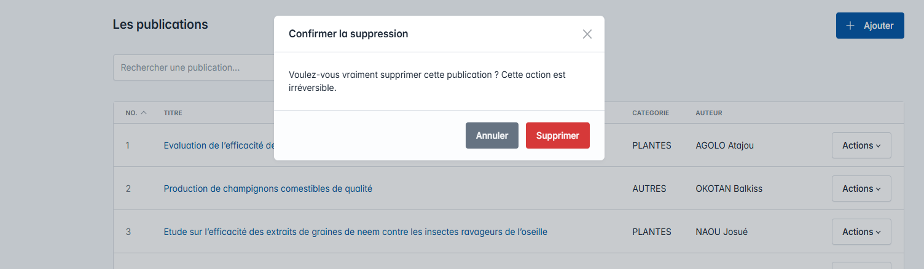
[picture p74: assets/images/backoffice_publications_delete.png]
publicatons_delete
| Publications – delete confirmation modal |  |

### 3.2 Publication Categories

**CRUD – bilingual French/Kabiyè support**  
Management of categories that organize publications. Each category has a name in two languages (French and Kabiyè) and can be illustrated with an image.

#### Features
{:.no_toc}

- **Read:** list of all categories
- **Create:** new category with image
- **Update:** edit name (FR/Kabiyè) and image
- **Delete:** with confirmation
- **Bilingual support:** French and Kabiyè fields required

#### Sections
{:.no_toc}

**Section 1 – Header**

|---|---|
| **Title** | “Categories” |
| **Action** | “Add” button |

**Section 2 – Categories table**

|---|---|
| **Column 1** | Name in French |
| **Column 2** | Name in Kabiyè |
| **Column 3** | Actions: Edit \| Delete |

**Section 3 – Add/Edit modal**

| **Field 1** | Name in French (required) |
| **Field 2** | Name in Kabiyè (required) |
| **Upload** | PNG/JPEG image + preview |
| **Actions** | Save \| Cancel |

#### Feedback messages
{:.no_toc}
- “Category added successfully!”
- “Category updated successfully!”
- “Category deleted successfully!”

#### Screenshots
{:.no_toc}

| Description | Screenshot |
| ---- | ---- |
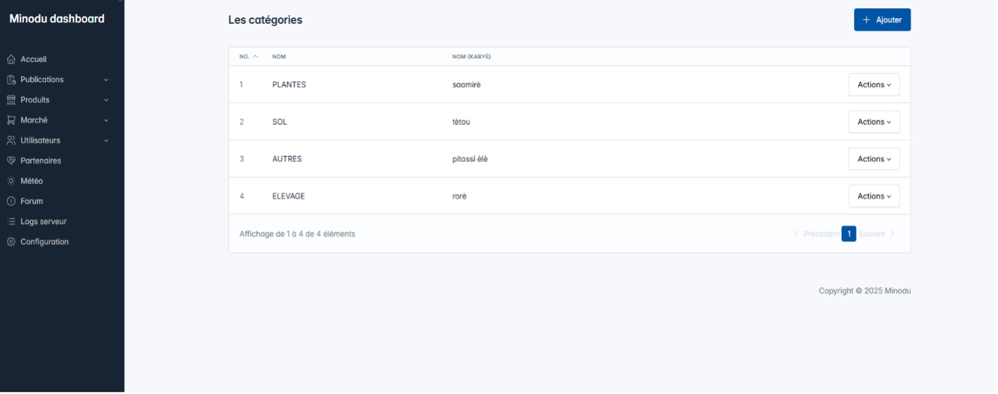
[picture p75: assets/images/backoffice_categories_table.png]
categories_table
| Publication Categories – table |  |
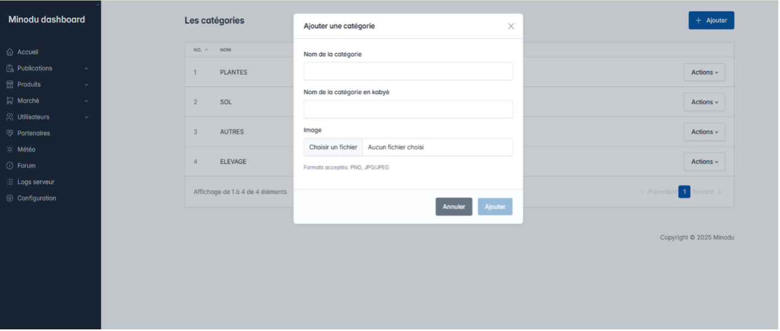
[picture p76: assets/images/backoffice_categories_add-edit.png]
categories_add-edit
| Publication Categories – Add/Edit |  |

### 3.3 Publication Tags

**CRUD – labels with avatars**  
Tags are labels associated with publications to improve organization and search. Each tag can have an illustrative image/avatar.

#### Features
{:.no_toc}

- **Read:** table with avatars
- **Create:** add with image
- **Update:** edit name and image
- **Delete:** with confirmation
- **Avatars:** each tag can have an illustration

#### Sections
{:.no_toc}

**Section 1 – Header and actions**

| --- | --- |
| **Title** | “Tags” |
| **Action** | “Add” button |

**Section 2 – Tags table**

|---|---|
| **Column 1** | Avatar (tag image) |
| **Column 2** | Tag name |
| **Column 3** | Actions: Edit \| Delete |

**Section 3 – Add/Edit modal**

|---|---|
| **Field 1** | Tag name (required) |
| **Upload** | PNG/JPEG image/avatar + preview |
| **Actions** | Save \| Cancel |

#### Feedback messages
{:.no_toc}
- “Tag added successfully!”
- “Tag updated successfully!”
- “Tag deleted successfully!”

#### Screenshots
{:.no_toc}

| Description | Screenshot |
| --- | --- |
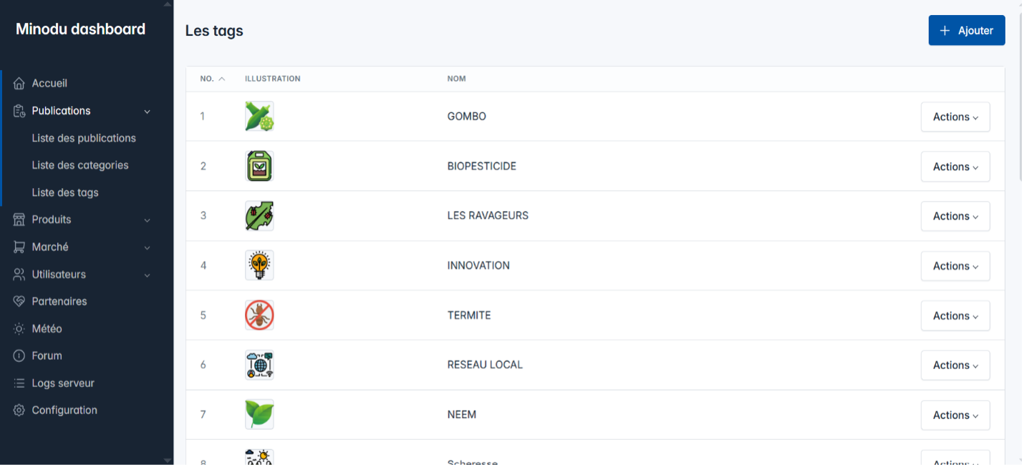
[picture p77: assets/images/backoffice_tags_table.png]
tags_table
| Publication tags – table |  |
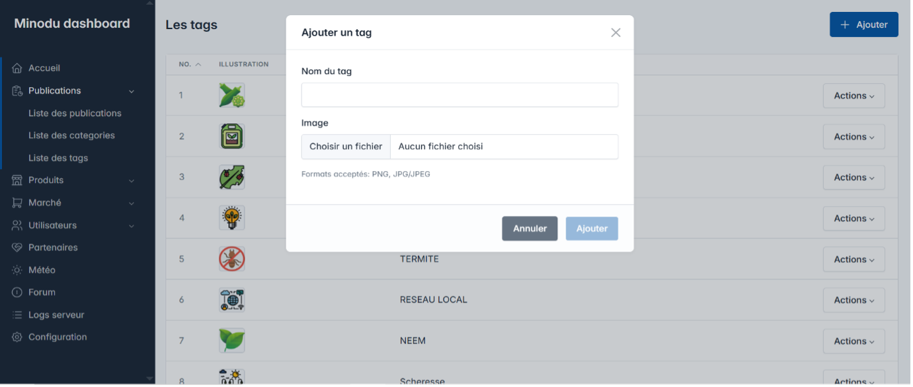
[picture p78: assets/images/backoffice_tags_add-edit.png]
tags_add-edit
| Publication Tags – Add/Edit modal |  |

### 3.4 Publication Details

**Detailed view – full consultation and editing**  
Page for in-depth consultation and editing of a single publication, accessible from the list through the “View” button. All properties and media are displayed and editable.

#### Features
{:.no_toc}
- **Consultation:** display all details
- **Update:** edit title, description, category, tags, images, and attachments
- **Navigation:** breadcrumb (Publications > Details)
- **Author:** complete author information
- **Upload:** change images and attachments

#### Sections
{:.no_toc}

**Section 1 – Header with navigation**

|---|---|
| **Breadcrumb** | Publications → Details |
| **Info** | Author name and information |

**Section 2 – General information**

|---|---|
| **Title** | Full publication title |
| **Description** | Full text |
| **Category** | Assigned category |

**Section 3 – Media and attachments**

|---|---|
| **Image** | Main publication image |
| **Tags** | List of associated tags |
| **Audio** | Audio files (FR and Kabiyè) |
| **PDF** | Attached PDF documents |

**Section 4 – Action buttons**

|---|---|
| **Action 1** | Edit publication |
| **Action 2** | Return to list |

#### Screenshots
{:.no_toc}

| Description | Screenshot |
| --- | --- |
| Publication Details – full view (information + media) | publication_details |

---

## Products
Module for managing the Minodu platform’s product catalog. It includes management of products themselves and their categories.

### 4.1 Product List

**Full CRUD – product catalog with images**  
Displays and manages the complete product catalog. The administrator can add, edit, and delete products, manage their properties (name, description, category, price, sales unit), and manage their images.

#### Features
{:.no_toc}

- **Read:** paginated table with all products
- **Create:** add via modal with image
- **Update:** edit all properties
- **Delete:** with confirmation
- **Images:** upload and manage PNG/JPEG files

#### Sections
{:.no_toc}

**Section1 – Header and actions**

|---|---|
| **Title** | “Products” |
| **Action** | “Add” button |

**Section 2 – Products table**

|---|---|
| **Column 1** | Product image |
| **Column 2** | Product name |
| **Column 3** | Category |
| **Column 4** | Price |
| **Column 5** | Actions: Edit \| Delete |

**Section 3 – Add/Edit modal**

|---|---|
| **Field 1** | Product name (required) |
| **Field 2** | Description |
| **Field 3** | Category (selector) |
| **Field 4** | Price (decimal value) |
| **Field 5** | Sales unit |
| **Upload** | PNG/JPEG image |
| **Actions** | Save \| Cancel |

#### Feedback messages
{:.no_toc}
- “Product added successfully!”
- “Product updated successfully!”
- “Product deleted successfully!”

#### Screenshots
{:.no_toc}

| Description | Screenshot |
| --- | --- |
| Products – full table | products_table |
| Products – Add/Edit modal | products_add-edit |

### 4.2 Product Categories

**CRUD – categories with illustrative images**  
Management of categories that organize products (e.g., vegetables, fruits, grains, etc.). Each category can be illustrated with an image.

#### Features
{:.no_toc}
- **Read:** list of all categories
- **Create:** add with image
- **Update:** edit name and image
- **Delete:** with confirmation
- **Images:** PNG/JPEG support

#### Sections
{:.no_toc}

**Section 1 – Header**

|---|---|
| **Title** | “Categories” |
| **Action** | “Add a category” button |

**Section 2 – Categories table**

|---|---|
| **Column 1** | Illustration image |
| **Column 2** | Category name |
| **Column 3** | Actions: Edit \| Delete |

**Section 3 – Add/Edit modal**

|---|---|
| **Field** | Category name (required) |
| **Upload** | PNG/JPEG image + preview |
| **Actions** | Save \| Cancel |

#### Feedback messages
{:.no_toc}
- “Product category added!”
- “Product category updated!”
- “Product category deleted!”

#### Screenshots
{:.no_toc}

| Description | Screenshot |
| --- | --- |
| Product Categories – table | product_cat_table |
| Product Categories – Add/Edit modal | product_cat_add-edit |

---

## Marketplace
Module for managing the Minodu marketplace. It brings together product offers published by producers/companies and product requests submitted by customers.

### 5.1 Product Offers

**Supply marketplace – published availability**  
Management of product offers: the availability that producers and companies highlight on the platform.

#### Features
{:.no_toc}
- **Read:** table of available offers
- **Create:** add a new offer
- **Update:** edit offer details
- **Delete:** remove an offer

#### Sections
{:.no_toc}

**Section 1 – Header**

|---|---|
| **Title** | “Product availability” |
| **Action** | “Add” button |

**Section 2 – Offers table**

|---|---|
| **Column 1** | Product |
| **Column 2** | Available quantity |
| **Column 3** | Producer price |
| **Navigation** | Pagination |

**Section 3 – Add/Edit modal**

|---|---|
| **Field 1** | Product selection |
| **Field 2** | Available quantity |
| **Field 3** | Producer |
| **Actions** | Save \| Cancel |

#### Screenshots
{:.no_toc}

| Description | Screenshot |
| --- | --- |
| Product Offers – full table | product_offers_table |
| Product Offers – Add/Edit modal | product_offers_add-edit |

### 5.2 Product Requests

**Demand marketplace – customer needs**  
Management of product requests: needs expressed by customers looking for products on the Minodu platform.

#### Features
{:.no_toc}
- **Read:** table of received requests
- **Status:** track request status
- **Details:** see who requests what and when
- **Tracking:** archive or process requests

#### Sections
{:.no_toc}

**Section 1 – Header**

|---|---|
| **Title** | “Product Requests” |

**Section 2 – Requests table**

|---|---|
| **Column 1** | Requested product |
| **Column 2** | Requested quantity |
| **Column 3** | Partner |
| **Column 4** | Deadline date |
| **Column 5** | Actions: Edit \| Archive \| Delete |
| **Navigation** | Pagination |

#### Screenshots
{:.no_toc}

| Description | Screenshot |
| --- | --- |
| Product Requests – full table | prodcuct_requests_table |
| Product Requests – Add/Edit modal | prodcuct_requests_add-edit |

---

## Users
Management of all users registered on the Minodu platform. Allows administrators to consult profiles and manage roles, statuses, and permissions.

### 6.1 Features
{:.no_toc}
- **Read:** paginated list
- **Actions:** edit

### 6.2 Sections
{:.no_toc}

**Section 1 – Header**

|---|---|
| **Title** | “Users” |

**Section 2 – Users table**

|---|---|
| **Column 1** | Name |
| **Column 2** | Phone |
| **Column 3** | Role |
| **Column 4** | Contact person |
| **Column 5** | Actions: Edit |
| **Navigation** | Pagination |

### 6.3 Screenshots
{:.no_toc}

| Description | Screenshot |
| --- | --- |
| Users – table | users_table |
| Users – Add/Edit modal | users_add-edit |

---

## Partners
Management of Minodu platform partners: companies, producers, and partner organizations. This section helps maintain business relationships and display partners to users.

### 7.1 Features
{:.no_toc}
- **Read:** list of all partners
- **Create:** add a new partner
- **Update:** edit information
- **Delete:** remove a partner
- **Contacts:** management of complete contact information
- **Categorization:** partner classification

### 7.2 Sections
{:.no_toc}
#### Section 1 – Header and actions
{:.no_toc}

|---|---|
| **Title** | “Partners” |
| **Action** | “Add a partner” button |

#### Section 2 – Partners table
{:.no_toc}

| **Column 1** | Name |
| **Column 2** | Address |
| **Column 3** | Phone |
| **Column 5** | Actions: Edit \| Delete |

#### Section 3 – Add/Edit modal
{:.no_toc}

|---|---|
| **Field 1** | Name |
| **Field 2** | Address |
| **Field 3** | Phone |
| **Actions** | Save \| Cancel |

### 7.3 Screenshots
{:.no_toc}

| Description | Screenshot |
| --- | --- |
| Partners – full table | partners_table |
| Partners – Add/Edit moral | partners_add-edit |

---

## Weather
Module for displaying weather data for the region covered by Minodu. Data is retrieved from an external service or a local weather station configured in the settings.

### 8.1 Features

- Current weather conditions
- Short-term forecasts (following days)
- Data: temperature, humidity, wind speed, UV
- Historical weather data
- Weather station configuration via the Configuration page

### 8.2 Weather data backup

The Minodu system provides a manual download process for weather data in XLSX format to ensure preservation and traceability of historical climate data.

| **Access** | “Download” button |
| **Format** | XLSX file with standardized structure |
| **Content** | Historical weather data |

### 8.3 Sections

#### Section 1 – Header
{:.no_toc}

|---|---|
| **Title** | “Weather” |
| **Location** | Displayed region/locality |

#### Section 2 – Current conditions
{:.no_toc}

|---|---|
| **Data 1** | Current temperature (°C) |
| **Data 2** | Conditions (Sunny / Cloudy / Rain, etc.) |
| **Data 3** | Illustrative weather icon |

**Section 3 – Weather details**

| **Data 1** | Humidity (%) |
| **Data 2** | Wind speed (km/h) |
| **Data 3** | Atmospheric pressure (hPa) |
| **Data 4** | UV index |

**Section 4 – Forecasts**

| **Content 1** | Forecasts for the coming days |
| **Content 2** | Temperature charts |

### 8.4 Screenshots
{:.no_toc}

| Description | Screenshot |
| --- | --- |
| Weather – full dashboard | weather_dashboard |

---

## Forum
Community discussion space for Minodu members. It enables exchanges between members, information sharing, and creation of discussion topics. The administrator has moderation rights.

### 9.1 Features
{:.no_toc}
- **Read:** display active discussions
- **Moderation:** delete

### 9.2 Sections
{:.no_toc}

#### Section 1 – Header
{:.no_toc}

|---|---|
| **Title** | “Forum” |

#### Section 2 – Discussion List
{:.no_toc}

|---|---|
| **Column 1** | Discussion title |
| **Column 2** | Author |
| **Column 3** | Actions: Detail \| Delete |

### 9.3 Screenshots
{:.no_toc}

| --- | --- |
| Forum – discussion list | discussion_list |
| Forum – detailed discussion | discussion_details |
| Forum – delete confirmation modal | confirmation_modal |

---

## Server Logs
Display and management of system event logs. This makes it possible to track all actions, errors, connections, and overall backoffice activity. Navigation is organized around two axes: log source and event type.

### 10.1 Features

- **Filter by source:** Backend \| Frontend \| RAG (dropdown)
- **Filter by type:** All \| Errors only \| Access only (tabs)
- **Deletion:** log cleanup (with confirmation)

### 10.2 Log navigation

#### Axis 1 – Source selector (Dropdown)
{:.no_toc}
Dropdown at the top of the page for selecting the source.

| Source | Description |
|---|---|
| **Backend** | Server logs – transactions, HTTP requests, database, server errors |
| **Frontend** | Client logs – clicks, loads, JavaScript errors, console errors |
| **RAG** | AI engine logs – requests, vector transformations, recommendations |

⚠️ The “Frontend” source is selected by default.

#### Axis 2 – Filtering tabs
{:.no_toc}
Three tabs below the dropdown for filtering by event type.

| Tab | Description |
|---|---|
| **All logs** | All events: errors + warnings + information + access |
| **Errors only** | HTTP 400–599, exceptions, critical warnings – red/orange color |
| **Access only** | Authentications, login attempts, role changes – green/orange |

⚠️ The “All logs” tab is active by default.

### 10.3 Sections

#### Section 1 – Header
{:.no_toc}

|---|---|
| **Title** | “Server logs” |
| **Subtitle** | “Display and management of server logs” |

#### Section 2 – Source selector (Dropdown)
{:.no_toc}

Dropdown selection: **Frontend** (default) \| **Backend** \| **RAG**.

#### Section 3 – Filtering tabs
{:.no_toc}

Three tabs: **All logs** (default) \| **Errors only** \| **Access only**.

#### ### Section 4 – Log file management
{:.no_toc}

Optional deletion: “Delete logs” button with mandatory confirmation before execution.

⚠️ Delete logs every 3 months.

### 10.4 Usage scenarios

| Scenario | Steps |
|---|---|
| **Scenario 1 – View all backend logs** | 1. Menu → Server logs<br>2. Dropdown (Source) → Select “Backend”<br>3. Tab (Filtering) → “All logs”<br>4. All server events are displayed |
| **Scenario 2 – Find a frontend error** | 1. Menu → Server logs<br>2. Dropdown (Source) → Select “Frontend”<br>3. Tab (Filtering) → “Errors only”<br>4. Only matching frontend errors are displayed |
| **Scenario 3 – Check access and authentication** | 1. Menu → Server logs<br>2. Dropdown (Source) → Select “Backend”<br>3. Tab (Filtering) → “Access only”<br>4. Login attempts, successful and failed authentications are displayed |
| **Scenario 4 – Delete logs** | 1. View logs using any source/filter<br>2. Click “Clear logs”<br>3. Confirm in the confirmation modal<br>4. Logs are cleared from the server (disk space freed) |

### 10.5 Common use-case guide

| Use case | Recommended view |
|---|---|
| **Daily monitoring** | Backend → All logs (hourly) |
| **User debugging** | Frontend → Errors only (when bugs are reported) |
| **Security audit** | Backend → Access only (check suspicious authentications) |
| **Monthly maintenance** | Delete to free space |

### 10.6 Screenshots
{:.no_toc}

| Description | Screenshot |
|---|---|
| Logs – Source dropdown open (Frontend / Backend / RAG) | logs_sources |
| Backend logs – all logs | logs_backend |
| Frontend logs – all logs | logs_frontend |
| RAG logs – all logs | logs_rag |
| Logs – delete confirmation modal | logs_delete-modal |

---

## Configuration
System administration page for configuring global Minodu settings. It allows customization of the community name, contact links, weather station, and administrator account security.

### 11.1 Features
{:.no_toc}
- **Community information:** name, location, address
- **Contact links:** WhatsApp, weather station
- **Description:** community presentation and introduction
- **Security:** change administrator password

### 11.2 Sections
{:.no_toc}

#### Section 1 – Header
{:.no_toc}

|---|---|
| **Title** | “Configuration” |

#### Section 2 – General information
{:.no_toc}

|---|---|
| **Field 1** | Community name |
| **Field 2** | Location |
| **Field 3** | Full address |
| **Field 4** | WhatsApp link |
| **Field 5** | Weather station link |
| **Field 6** | Community presentation |

#### Section 3 – Security
{:.no_toc}

|---|---|
| **Action 1** | “Change password” button → opens modal |
| **Action 2** | Save changes |

#### Section 4 – Change password modal
{:.no_toc}

|---|---|
| **Field 1** | New password |
| **Field 2** | Confirm new password |
| **Actions** | Validate \| Cancel |

### 11.3 Feedback messages
{:.no_toc}

- “Your community information has been updated successfully!”
- “Password changed successfully!”

### 11.4 Screenshots
{:.no_toc}

| Description | Screenshot |
|---|---|
| Configuration – general form (information + links) | configuration_form |
| Configuration – password change | configuration_pw |

### Important user flows
Here are some common procedures

#### How do you add a new audio file/podcast? 
{:.no_toc}

To add a new audio file or podcast, open the **Add** form and complete the required information.

1. Enter the **Author** and **Title** (required fields).
2. Optionally, add a **Description**.
3. Select the appropriate **Category**.
4. Upload a **Main image** (PNG or JPEG).
5. Select one or more **Tags**.
6. Upload the audio files:
   - French audio 
   - Kabiyè audio 
7. If applicable, upload a **PDF** file.(a document that content further informations about the work resumed in the audio files)
8. Click **Save** to publish the audio, or **Cancel** to discard your changes.

#### How do you remove the wrong content? 
{:.no_toc}
1. Identify the incorrect content ( Title, Author name , audio, pdf file, etc.).
2. Log in to the back office 
3. Go to the list of content (publications, categories, products, tags, ect.).
4. Search for the content by title, date, or author.
5. Open the details page for the relevant content.
To do a simple correction:
- Edit the text or metadata.
- Save the changes.
To remove content that is no longer needed:
- click the **Delete** action. 
A confirmation dialog will appear to prevent accidental deletion. 
- Click **Confirm** to permanently delete the content, or **Cancel** to keep it.

#### How do I moderate forum posts? 
{:.no_toc}

The administrator can review active discussions and remove inappropriate topics or replies if necessary.
Select the **Delete** action for the content to be removed, then confirm the deletion.
Deleted content is permanently removed from the forum.

#### How do I export weather data? 
{:.no_toc}

To collect historical weather data:
1. Log in to the backoffice using an administrator account.
2. Navigate to the **Weather Data** section.
3. Click the **Download** button.
4. The system generates an **XLSX** file containing the available historical weather data.
5. Save the downloaded file to your computer for reporting or further analysis.

#### How do I back up the system? 
{:.no_toc}

We recommend to do the backup, before any software update, maintenance operation, or configuration change.

#### What should I never delete? 
{:.no_toc}
 
 Do not delete the following items without prior validation:
- System folders required for the back office to operate (e.g., `/system`, `/core`, `/config`).
- Application and database configuration files (e.g., `config.php`, `.env`, `settings.json`).
- Files or folders required for the proper operation of the application, even if they appear unused.
- Backup files that are still important or covered by the backup retention policy.
- Administrator or technical accounts without first confirming their purpose and dependencies.
  
The default content delivered with the application must not be deleted:
   Any default data provided with the application, including but not limited to:
  - Default categories
  - Default tags
  - Initial publications
  - Default products
  - Preconfigured user accounts
  - Default partners
  - Forum categories or topics
  - Any other data installed by default during deployment
  - Any file, folder, database record, or configuration item whose purpose is not clearly understood.
Golden Rule: If you are unsure whether an item is safe to remove, **do not delete it**.

---

#### What do I do when the system is offline? 
{:.no_toc}

Here are some steps to follow if the system goes offline
Basic Checks: - Check the power supply to the raspbery pi/the server.
- Check the switch.
Restart: - If the system appears to have frozen, perform a hard reset (using the power switch).
- Wait a few minutes and check if the services are accessible again.
If the outage persists, contact the maintenance team and inform the community through the designated channels (WhatsApp group).
Provide the following information to the maintenance team:
- Time of the outage
- Observed symptoms (inaccessible pages, error messages, etc.)
- Actions already taken (restart, checking the switch, etc.)

---

## Module Summary

| # | Module | Key features | Access |
|---:|---|---|---|
| **1** | **Authentication** | Login, sessions, security | Entry page |
| **2** | **Dashboard** | Statistics, logout | After login |
| **3.1** | **Publications** | CRUD + media uploads | Publications menu |
| **3.2** | **Publication categories** | Bilingual FR/Kabiyè CRUD | Publications menu |
| **3.3** | **Publication tags** | CRUD with avatars | Publications menu |
| **3.4** | **Publication details** | Consultation + editing | Via publication list |
| **4.1** | **Products** | CRUD + price + unit | Products menu |
| **4.2** | **Product categories** | CRUD with images | Products menu |
| **5.1** | **Marketplace offers** | CRUD + availability status | Marketplace menu |
| **5.2** | **Marketplace requests** | Consultation + status tracking | Marketplace menu |
| **6** | **Users** | Consultation + blocking | Users menu |
| **7** | **Partners** | CRUD + contacts | Partners menu |
| **8** | **Weather** | Real-time display | Weather menu |
| **9** | **Forum** | Discussions + moderation | Forum menu |
| **10** | **Server logs** | Backend / Frontend / RAG | Logs menu |
| **11** | **Configuration** | Settings + password | Config menu |

<br>

---

© 2026 Minodu – Confidential  
Minodu Backoffice – Administrator Documentation

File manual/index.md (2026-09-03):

---
layout: page
title: Manual
---

manual

This section provides practical guidance for using and managing the Local Community Network (LCN). It combines user-facing instructions with administrative documentation.
The manuals are structured to support two main user groups:
- **Users** → accessing information and interacting with the application  
- **Administrators** → managing content, data, and system configuration  
Together, these manuals ensure that the Local Community Network can be **used, maintained, and adapted locally**.

## The User Manual
This manual explains how to use the Local Community Network from a user perspective. It covers how to access the system, navigate the interface, and use the different application features such as agriculture, market, forum, and weather.  

*[→ App manual](app)*

## The Admin Manual
The backoffice manual provides guidance for administrators managing the system. It covers content creation, user management, market administration, and system configuration.

*[→ Backoffice manual](backoffice)*

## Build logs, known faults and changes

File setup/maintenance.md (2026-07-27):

---
layout: page
title: Maintenance
heading_title: Maintenance Guide
---

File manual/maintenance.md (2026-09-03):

---
layout: page
title: Backoffice
---

# Maintenance

Regular maintenance is necessary to keep the system operational, up to date, and useful for the community. For the Minodu LCN, maintenance is shared between our 3 local communities (users), CAVRIS (working with technical partners), and Kara University (Students, researchers, and different institutions work together for the content creation). The following structure defines the main responsibilities and recommended maintenance rhythm.

## 1. Roles and responsibilities

### Community focal point - daily/regular operational check

The community focal point is the first person responsible for checking that the system is available and functioning from the user's perspective.

**Main responsibilities:**

* Check that the system is switched on and accessible.
* Verify that the main interface and content can be opened normally.
* Check whether users encounter obvious problems.
* Collect and report recurring issues or user feedback in the WhatsApp group.
* The technical focal point will be imformed if a technical intervention is needed.

**Recommended frequency:**
A quick operational check should be carried out regularly, ideally as part of the normal use of the system.

### Technical focal point - first-line technical support : Fablab/CAVRIS

The technical focal point is responsible for basic technical troubleshooting and for coordinating technical problems with the appropriate technical partner.

**Main responsibilities:**

* Check the power supply and physical connections.
* Restart the Raspberry Pi when necessary.
* Check whether the system starts correctly after a restart.
* Check basic network/connectivity issues where applicable.
* Document technical problems and attempted solutions.
* Escalate problems that cannot be solved locally to the maintenance whatsapp group.

**Recommended frequency:**
Intervention when a problem is reported, plus a periodic basic technical check.

### Kara University - content and knowledge support

Kara University supports the quality and relevance of the information available through the system, particularly agricultural and climate-related content.

**Main responsibilities:**

* Support content updates.
* Create new audios/content through the '' Cellule de communication scientifique ''.
* Provide expert answers to agriculture and climate-related questions in the forum
* Provide expert feedback when content needs to be corrected or updated.
* Help identify new content needs based on community feedback.

**Recommended frequency:**
New content should be add periodically or whenever new audios are available from the '' Cellule de communication scientifique ''.

### Fablab / CAVRIS - technical maintenance

Fablab/CAVRIS provides higher-level technical support and maintains the system.

**Main responsibilities:**

* Diagnose technical problems that cannot be solved locally.
* Maintain and update the Raspberry Pi and associated software.
* Check system performance and storage.
* Perform necessary software or system updates.( Digital inspiration for assistance)
* Support hardware troubleshooting and replacement when required.(Ecoteclab for assistance)
* Maintain technical documentation.
* Support recovery in case of system failure.
* Provide the technical focal point that will coordinate with the focal point when an intervention is required.

**Recommended frequency:**
Periodic preventive maintenance, in addition to intervention when technical problems are reported.

## 2. Maintenance rhythm

A simple maintenance calendar helps prevent problems before they affect users.

| Activity | Recommended frequency | Responsible |
| --- | --- | --- |
| Check that the system is running | Regular / daily when in active use | Community focal point |
| Check power and basic hardware | when problems occur | Community focal point |
| Check system performance | Monthly | Technical focal point / Fablab-CAVRIS |
| Backup/export weather data | Monthly | Technical focal point / Fablab-CAVRIS |
| Review and new contents | Periodically / at least quarterly  | Kara University |
| Check and update system/software | As needed / scheduled maintenance  | Fablab-CAVRIS |
| Forum moderation | Weekly | Community focal point / designated moderator |
| Review user feedback and recurring problems | Regular | Community focal point + Kara University |
| Full maintenance review | Every 6 months | All focal points |

The exact rhythm can be adapted according to the frequency of use, available connectivity, and local capacity.

## 3. Backup and data management

Backups should be performed regularly to avoid losing locally stored data in case of hardware failure or accidental deletion.

### Recommended backup rhythm

**Monthly:**

* Export or back up weather data.
* Check that the backup was completed successfully.
* Keep the most recent backup in a safe location.
* Where possible, maintain more than one copy of important data.

The backup procedure should be documented in the technical documentation so that another person can perform it if the usual technical focal point is unavailable.

## 4. Forum moderation

### Recommended rhythm: weekly

The moderator should:

* Check new posts and questions.
* Identify unanswered questions.
* Remove or flag inappropriate or irrelevant content where necessary.
* Forward technical questions to the technical focal point.( Whatsapp group)
* Forward agricultural or climate questions requiring expert input to Kara University.( Whatsapp group)
* Identify recurring questions or feedback that could lead to content improvements.

Forum moderation should not only be seen as content control: it is also an important **feedback loop** for improving the system and understanding users' needs.

## 5. Problem reporting and escalation

When a problem occurs, it should be reported through a simple escalation process:

**User / Community / Community focal point --> Whatsapp group ( --> Kara University --> Technical focal point --> Fablab/CAVRIS )**

For content-related issues:

**User / Community / Community focal point --> Whatsapp group ( --> Kara University )**

For issues involving both content and technology, the Technical Focal Point and Kara University should coordinate with Fablab/CAVRIS and technical partners as appropriate.

Each significant problem should ideally be recorded with:

* Date and time
* Description of the problem
* Person reporting it
* Actions already taken
* Result of the intervention
* Whether further action is required

## 6. Maintenance log - Fablab/CAVRIS

A simple maintenance log can be used to keep track of interventions.

| Date | Problem / activity | Person responsible | Action taken | Result | Follow-up |
| --- | --- | --- | --- | --- | --- |
| YYYY-MM-DD | Example: system not accessible | Technical focal point | Restarted Raspberry Pi | System restored  | Monitor |
| YYYY-MM-DD | Monthly backup | Technical focal point | Weather data exported  | Backup completed | Next backup: YYYY-MM-DD |

Keeping this log makes it easier to identify recurring problems and ensures that maintenance knowledge is not dependent on one person.

## 7. Minimum maintenance checklist

Before considering maintenance complete, verify:

* [ ] System starts correctly.
* [ ] Power supply is stable.
* [ ] Raspberry Pi is operational.
* [ ] Main interface/content is accessible.
* [ ] Recent data is available.
* [ ] Scheduled backup has been completed.
* [ ] Forum has been checked.
* [ ] Reported technical problems have been recorded.
* [ ] Content issues have been forwarded to the appropriate focal point.
* [ ] Any unresolved problem has a designated person responsible for follow-up.

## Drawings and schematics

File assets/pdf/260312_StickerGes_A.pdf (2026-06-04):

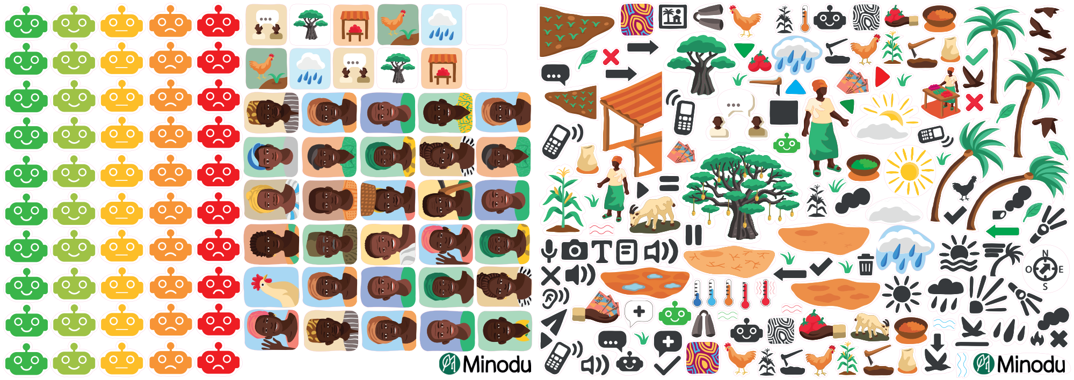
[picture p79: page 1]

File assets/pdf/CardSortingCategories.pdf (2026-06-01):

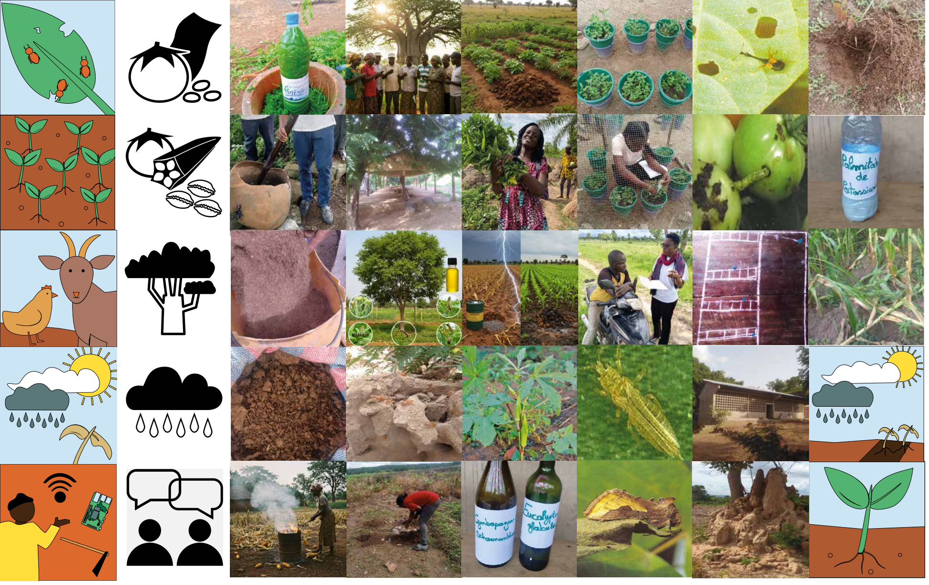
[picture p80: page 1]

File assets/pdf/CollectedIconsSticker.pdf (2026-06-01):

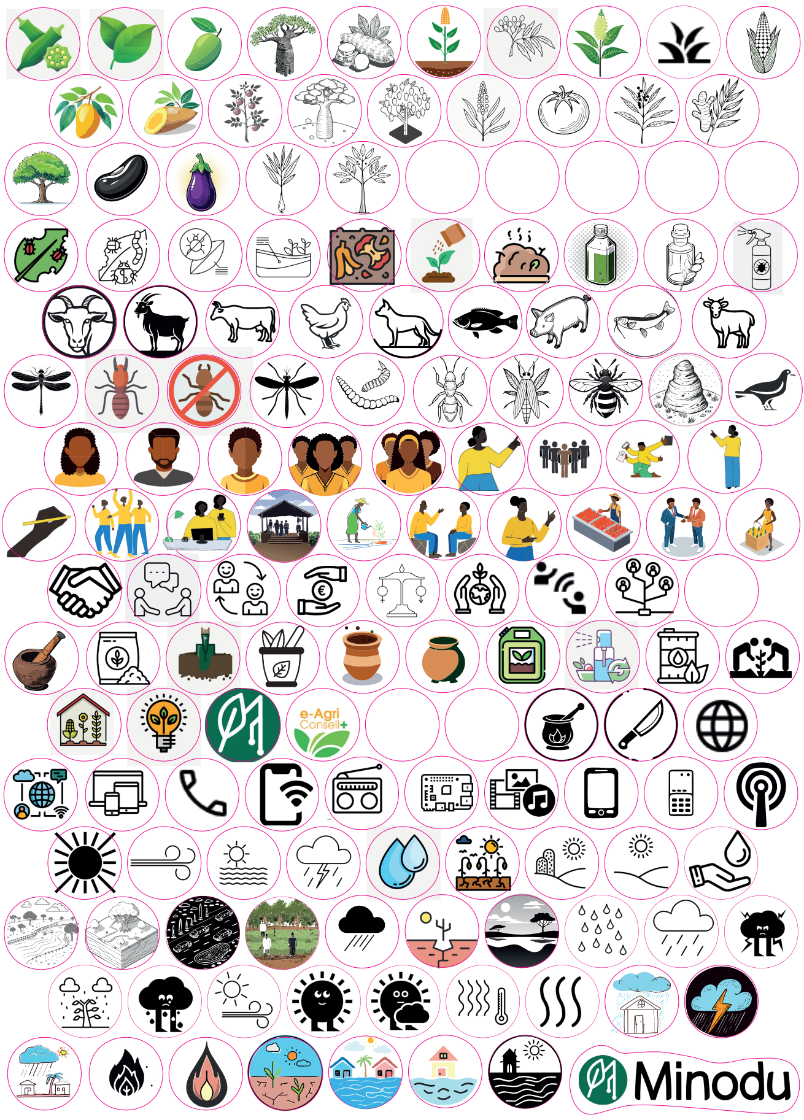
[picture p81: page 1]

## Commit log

2026-06-03 Enhance RPI setup documentation with installation guide
    Added detailed installation instructions for setting up Minodu LCN on Raspberry Pi, including requirements and troubleshooting tips.
2026-06-08 adds discussion board links
2026-06-15 Hardware: Add 3D files for Minodu Box and related components
    [50mm_Pole_Fixation.stl, Base_x01.stl, Clip_x02.stl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]
2026-06-15 Youtube Assembly PlaceHolder, Fusion 360 Live view Fix and Preview Fix
2026-06-17 STL files list Updated
2026-06-23 Minor fix On setup Page "Climate" to "community"
    [StevensonScreen_RC01_Base.stl, StevensonScreen_RC01_Botom.stl, StevensonScreen_RC01_Midlle_SensorPlate Holder.stl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]
2026-06-24 hardware assembly image display fix
2026-06-29 Protection Box Guide draft 01
    [StevensonScreen_RC01_Midlle_SensorPlate_Holder.stl]
2026-06-29 Assembly Steps Video
2026-06-29 assembly seps video Fix00
2026-06-29 ABS UV resistance mention-Hardware Assembly
2026-07-05 Correct spelling of 'MINODU' to 'Minodu' / Finding ways to add explanation of the i;portant user flows ..proposed
2026-07-06 Update backoffice.md with consolidated user instructions
    Reorganized and consolidated instructions for adding audio files, removing content, and managing forum posts. Removed redundant sections and added new user flow details.
2026-07-13 add sensors, add qr-quode
2026-07-20 adds link buttons
2026-07-21 added description to hardware assembly
2026-07-27 make logo = home button
2026-08-26 StevesonS 3D assembly guide and images added to the repository. Updated about/index.md and setup/hardware.md to include references to the new 3D assembly guide and images.
    [Minodu_Box.3mf]
2026-08-26 Stevenson screen assembly Video fix
2026-09-08 adds weather sensors
2026-10-09 Rpi Windows Setup Guide & Wiring Diagram
